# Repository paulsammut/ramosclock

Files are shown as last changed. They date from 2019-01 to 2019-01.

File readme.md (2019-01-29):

# Ramos Alarm Clock

The Ramos Alarm Clock was an alarm clock that forced people to get out of bed in
the morning by making it impossible to shut off the alarm from bed and simply
going back to sleep. It accomplished this by the use of a "defuse panel" which
was a wireless keypad that the user would place somewhere far away from their
bedroom. Most users put it in the bathroom; more extreme users put in their car.
When the alarm went off, the user had to get out of bed, and walk to the defuse
panel and punch in a defuse code to turn off the alarm. This gave well
intentioned users that really wanted to get up early but just had a hard time
escaping the cozy gravitational field of their bed the push they needed to start
their day fresh and early (kinda like how mom woke you up during high school).

This project started out as a [kickstarter
campaign](https://www.kickstarter.com/projects/2074185253/ramos-alarm-clock).

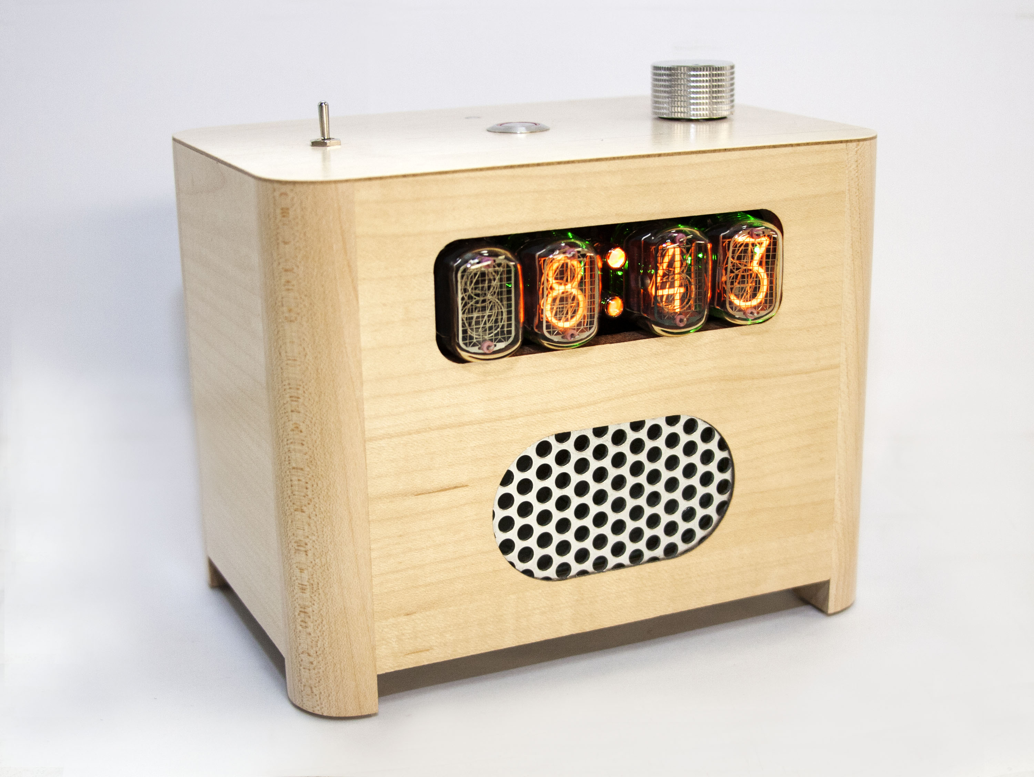
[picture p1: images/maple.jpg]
Maple Nixie Ramos Nixie_Ramos


## Source Code

This source was written by Nolan Sandberg, and Paul Sammut.

This is the source code for the Nixie Ramos, LED Ramos and the defuse panel.
These 3 devices shared similar code and all ran on the same PIC18F45K20
microcontroller. The code includes the MPLAB X project files and the compiler used
was the C18 compiler. All source is written in C and programmed using a PicKit3.
There are loads of features in the clock such as:

* Sound system for playing tones and a voice menu 
* Digit cycling on each minute for Nixie Tube health 
* The defuse code could be either the day's date or a random code 
* An external RTC with an built in TCXO with a clock accuracy of 3 ppm 
* Multiplex display driver that allowed for 32 levels of brightness for each tube 
* Auto-dim brightness with an light sensor, to dim the display to a settable
  level when there is no light in the room.

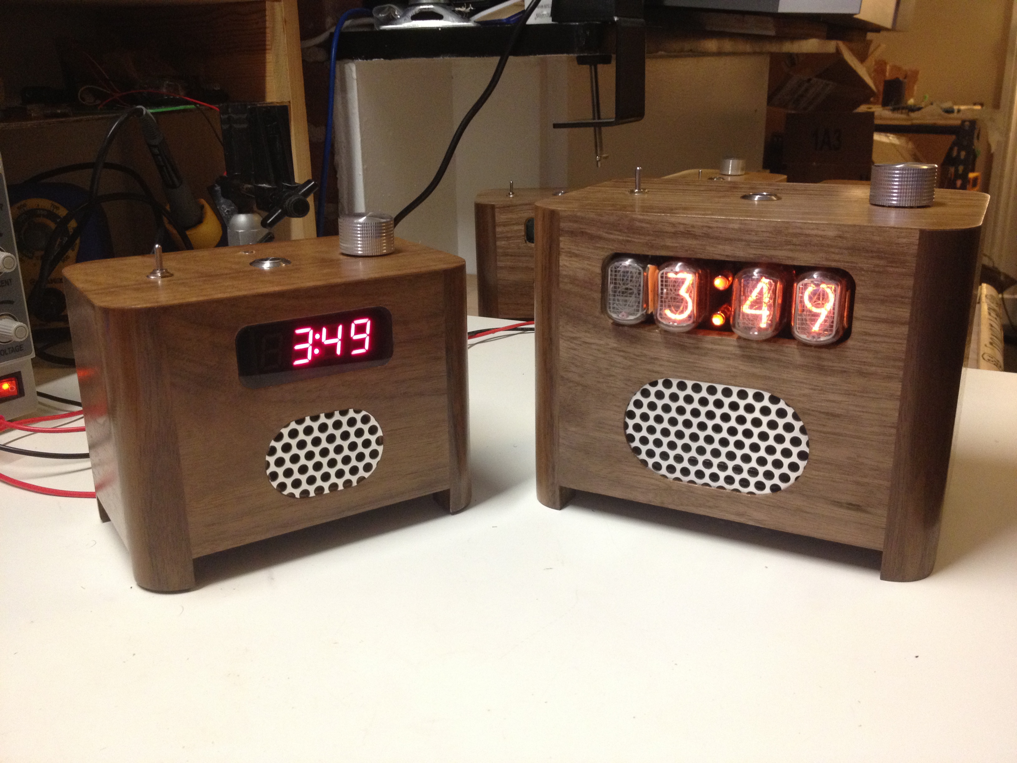
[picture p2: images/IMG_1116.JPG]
LED Ramos left and Nixie Ramos right LED_Nixie_Ramos


## Circuit Files

Included in this repo are also all the schematics, gerbers and Altium files. The
boards were panelized and mass produced. Great consideration was taken to
minimize the BOM count and facilitate assembly. These clocks all passed FCC
testing, even the Nixie! One of the very few Nixie Clocks that's FCC certified.
The EMC report is included in the schematics folder.

Circuit Board Nixie board

### Nixie Circuit

IN-12A Nixie tubes were used. I bought thousands in bulk from sellers in the
Ukraine and Russia. When I bought them in 2012-2014 the price was around $1.50 a
tube shipped. 

The nixie circuit used a Taylor Edge 1364 high voltage power supply that
supplied the 170 Volts. The display was controlled using ULN2003s in a neat way.
You can't find 8 channel transistor IC's that can handle 180V's anymore, and I
didn't want to use the original Russian nixie drivers IC's for reliability
issues, so I used the ULN2003's which had a max volt rating of 100V and clamped
the common voltage to 91V. This meant that in their off state, the tubes saw
91V, which wasn't enough to fire the tubes, and in their on state they saw the
full 170V. The ULN's only saw the delta of 170 and 91, which was below the max
rated voltage, so it was happy. Out of the thousand clocks we sold, we never had
an issue with the driver circuitry. 

### Wireless

The wireless data link between the defuse panel and the clock is handled by a
CC1101 chip on board an Anaren module. This module was the most expensive part
of the BOM ($11 at high volume) but it was pre-certified as an intentional
radiator. Interfacing to the CC1101 chip was a bit of a pain, the but the source
is all there as a reference. Great chip and we had very good range throughout a
house and sometimes outside the house.

### The Alarm Not Going Off Bug

We made a thousand of these clocks and only had one return. But, there was one
major bug that we caught early on and it had to do with the sound system
communication. A couple of people would email us, swearing that their alarm
didn't go off.

It was a really interesting problem because you could never replicated it on the
bench, and when the user would power cycle their clock it would magically work
again. This was because the problem was related to accumulated oscillator drift
which effected the PWM communication timing with the sound chip, meaning that
whenever you restarted the clock the problem would go away. The problem would
only manifest itself in a tiny percentage of our clocks, after the clock was
running for a long period of time. I was never ever able to reproduce the
problem, but I was able to pin point it to a less than robust communications PWM
protocol with the sound chip.

In the original firmware, the PIC18, who handled all the state flow stuff, would
send a signal to the sound chip using a PWM serial comms protocol to play a
sound. The PIC18 would assume that the sound was playing and happily move on.
This worked all the time during bench testing and our beta testing, and our
initial shipments. But it had no error checking and when you start playing
statistics, with a 1000 devices each with an alarm event every day, with
oscillator drift ranges, it meant that a tiny percentage of those sound commands
sent through PWM had their pulse widths exceeding the limits, meaning a poor
person's alarm wouldn't go off that morning. 

I fixed it by monitoring a DO line from the sound chip that would go high when
sound was playing. On every sound command sent by the PIC18, it made sure to
monitor the response from the sound chip. If it detected no sound was playing it
would do a live oscillator re-cal and resend the command. I was lucky to have
routed this line to a DI pin on the PIC18, so it was a simple firmware fix. 

### Altium Board Files

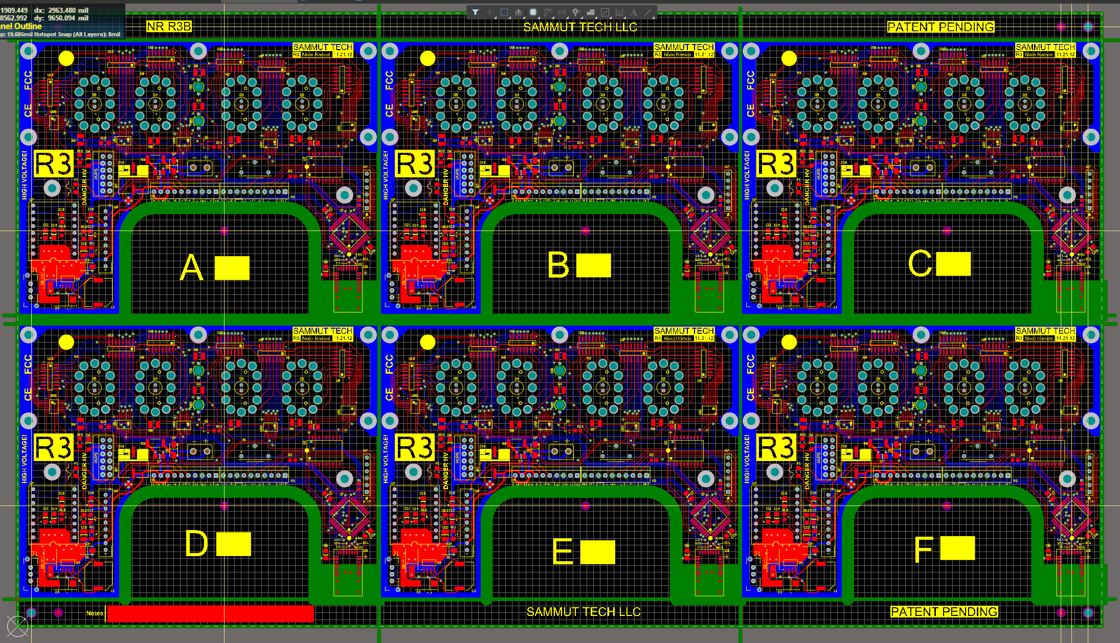
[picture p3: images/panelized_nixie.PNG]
Panelized boards Panelized Board


Included are packaged Altium files for all the boards. They were packed using
Altium 2019. Included are also all the panelized boards. The circuit boards were
4 layer: two signal, a ground and a power plane.

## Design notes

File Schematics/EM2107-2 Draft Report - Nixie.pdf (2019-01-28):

# Test Report

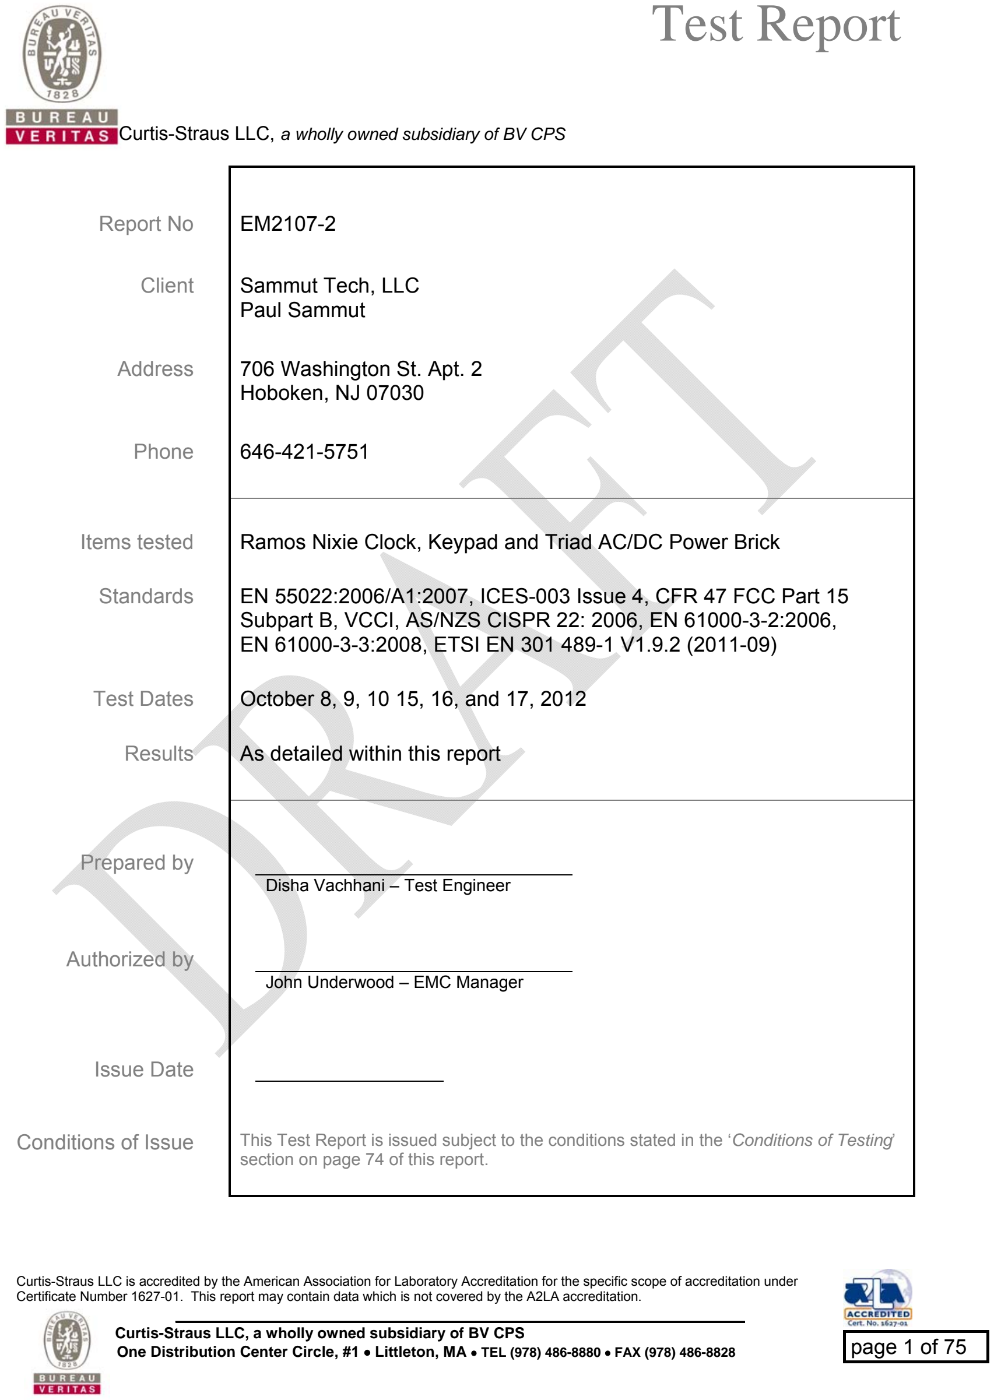
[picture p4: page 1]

Curtis-Straus LLC is accredited by the American Association for Laboratory Accreditation for the specific scope of accreditation under Certificate Number 1627-01. This report may contain data which is not covered by the A2LA accreditation.
____________________________________________________________
LLC • | Curtis-Straus LLC, a wholly owned subsidiary of BV CPS
One Distribution Center Circle, #1 • Littleton, MA • TEL (978) 486-8880 • FAX (978) 486-8828 | page 1 of 75

Curtis-Straus LLC, a wholly owned subsidiary of BV CPS

Report No | EM2107-2
Client | Sammut Tech, LLC Paul Sammut
Address | 706 Washington St. Apt. 2 Hoboken, NJ 07030
Phone | 646-421-5751
Items tested | Ramos Nixie Clock, Keypad and Triad AC/DC Power Brick
Standards | EN 55022:2006/A1:2007, ICES-003 Issue 4, CFR 47 FCC Part 15 Subpart B, VCCI, AS/NZS CISPR 22: 2006, EN 61000-3-2:2006, EN 61000-3-3:2008, ETSI EN 301 489-1 V1.9.2 (2011-09)
Test Dates | October 8, 9, 10 15, 16, and 17, 2012
Results | As detailed within this report

Prepared by
Disha Vachhani – Test Engineer

Authorized by
John Underwood – EMC Manager

Issue Date

Conditions of Issue This Test Report is issued subject to the conditions stated in the ‘Conditions of Testing’ section on page 74 of this report.

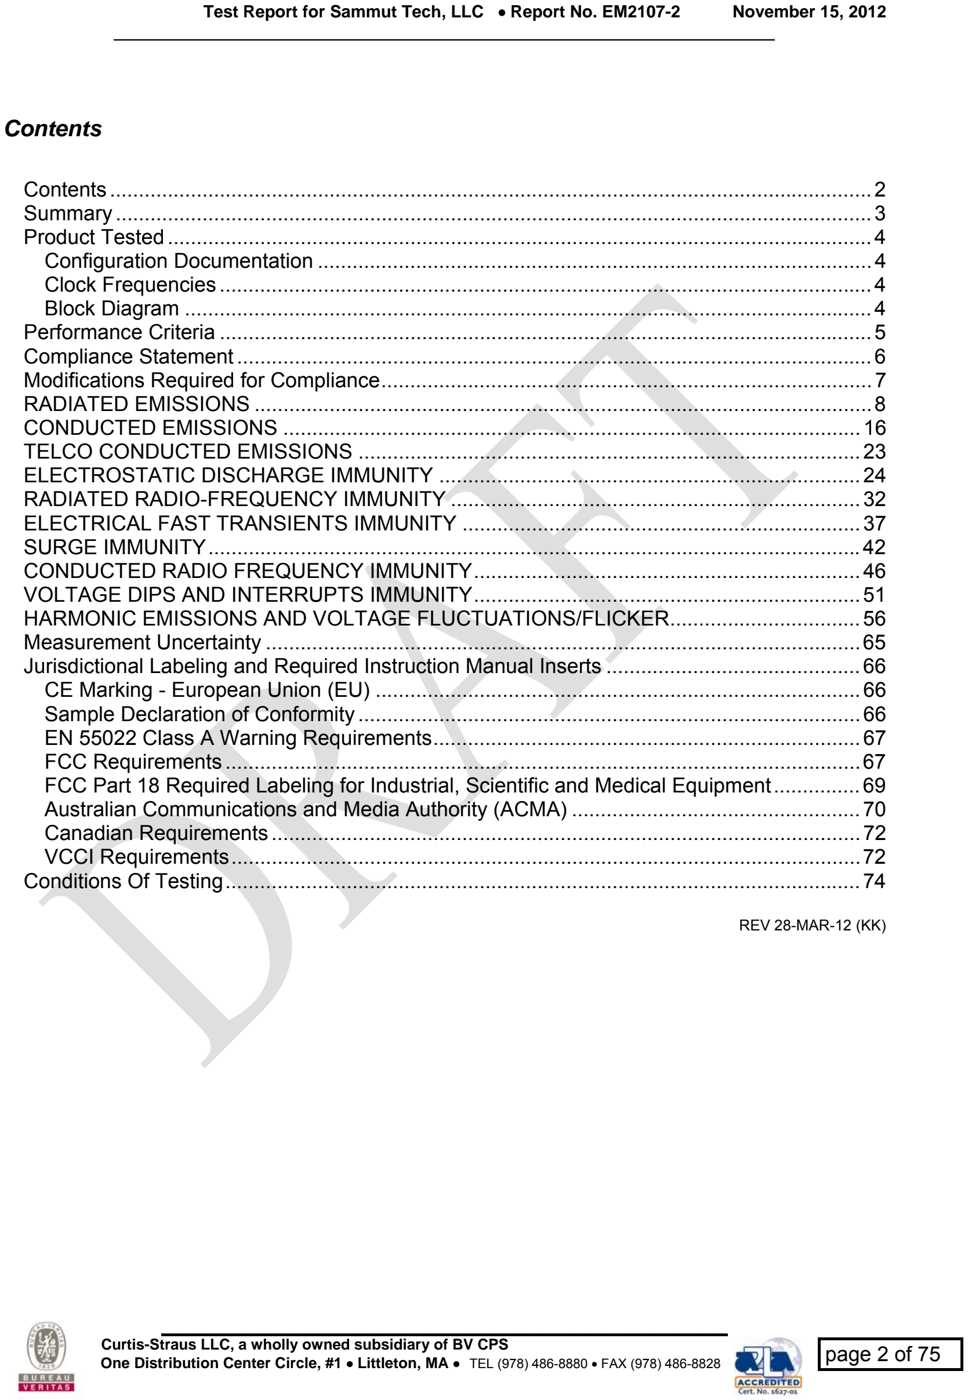
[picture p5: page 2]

Test Report for Sammut Tech, LLC • Report No. EM2107-2 November 15, 2012 ______________________________________________________________________

____________________________________________________________
Curtis-Straus LLC, a wholly owned subsidiary of BV CPS One Distribution Center Circle, #1 • Littleton, MA • TEL (978) 486-8880 • FAX (978) 486-8828 | page 2 of 75

Contents

REV 28-MAR-12 (KK)

Issue No. | Reason for change | Date Issued
1 | Original Release | November 15, 2012

_____________________________________________________________ Curtis-Straus LLC, a wholly owned subsidiary of BV CPS
One Distribution Center Circle, #1 • Littleton, MA • TEL (978) 486-8880 • FAX (978) 486-8828

page 3 of 75

Summary

On October 8, 9, 10 15, 16, 17, 2012 we tested the Ramos Nixie Clock, Keypad and Triad AC/DC Power Brick for compliance with the following requirements:

EMC Emissions:
- EN 55022:2006/A1:2007 Class B ITE emissions requirements (EU)
- ICES-003 Issue 4 Class B Digital Apparatus emissions requirements (Canada)
- CFR 47 FCC Part 15 Subpart B Class B emissions requirements (USA)
- VCCI Class B ITE emissions requirements (Japan)
- AS/NZS CISPR 22: 2006 Class B ITE emissions requirements (Australia)
- EN 61000-3-2:2006 Limits for harmonic current emissions (equipment input current up to and including 16A per phase)
- EN 61000-3-3:2008 Limitation of voltage fluctuations and flicker in low-voltage supply systems for equipment with rated current up to and including 16 A

EMC Emissions and Immunity:
- ETSI EN 301 489-1 V1.9.2 (2011-09) Electromagnetic compatibility and Radio spectrum Matters (ERM); ElectroMagnetic Compatibility (EMC) standard for radio equipment and services; Part 1: Common technical requirements – Fixed use

We found that the product met the above requirements with modification (see Modifications Required for Compliance section on page 6). The test sample was received in good condition. The sample was received on August 31, 2012.

Please note that the Ramos Nixie Clock was tested in alarm and standby modes.

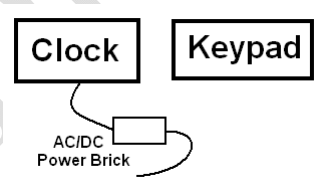
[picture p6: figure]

One Distribution Center Circle, #1 • Littleton, MA • TEL (978) 486-8880 • FAX (978) 486-8828 | page 4 of 75

Product Tested

Configuration Documentation

EUT Configuration

Work Order: M2107
Company: Sammut Tech, LLC
Company Address: 706 Washington St. Apt. 2 Hoboken, NJ 07030
Contact: Paul Sammut
| | MN | | | | | | SN
EUT:
Ramos Clock | | Nixie Ramos | | | | | | Sample 1
Ramos Keypad | | Not Listed | | | | | | Sample 1
Triad AC/DC Power Brick | | WSU135-1330 | | | | | | Sample 1
EUT Description: Ramos Clock and Ramos Clock Keypad
EUT Max Frequency: 32Mhz
EUT Min Frequency: 8MHz
EUT Ports:
Port Label | Port Type No. of ports
| | | No.
Populated Cable Type Shielded | Ferrites | Length
| | | | | | | | Max
| | | | | | | | Length | In/Out
| | | | | | | | | NEBS Type

Unpopulated
Reason
AC/DC Power Brick | AC Power | 1 | 1 | 2-wire | NA | no | NA | NA | Indoor
Software / Operating Mode Description:
EUT is a clock that has alarm settings. It can be operated with AC/DC power or battery. The keypad is used to set the alarm and to turn off the alarm.

Clock Frequencies

### EUT Frequencies (MHz)

8
32

Block Diagram

One Distribution Center Circle, #1 • Littleton, MA • TEL (978) 486-8880 • FAX (978) 486-8828 | page 5 of 75

Performance Criteria
Criterion A: The unit must operate as intended during the test. In particular, the clock shall update the time by 1 minute every 60 seconds; before the time is updated a random number will be displayed. In normal mode: the LED on the keypad shall continuously blink pink (indicating data is being sent) and then green (indicating data is being received). The LED shall not turn blue, which indicates standby mode. In standby mode: The clock shall not unintentionally transmit.

Criterion B: The unit must operate as intended at the conclusion of the test with no loss of state or data.

Criterion C: Temporary loss of function is allowed, provided the function is self-recoverable or can be restored by the operation of the controls by the user in accordance with the manufacturer's instructions.

One Distribution Center Circle, #1 • Littleton, MA • TEL (978) 486-8880 • FAX (978) 486-8828 | page 6 of 75

Compliance Statement

TEST | RESULT | STANDARD | TEST LEVEL | MARGIN | COMMENTS

Radiated
Emissions

PASS

EN55022:2006/A1:2007
ICES-003 Issue 4
CFR 47 FCC Part 15
Subpart B
VCCI
AS/NZS CISPR22:2006
Class B | -8.8dB @ 51.8MHz

AC Mains
Conducted
Emissions

PASS

EN55022:2006/A1:2007
ICES-003 Issue 4
CFR 47 FCC Part 15
Subpart B
VCCI
AS/NZS CISPR22:2006
Class B | -6.8dB @ 0.17MHz

Telco Line
Conducted
Emissions
N/A | EN55022:2006/A1:2007
VCCI | N/A | N/A | No telco cables
ESD | PASS | EN 61000-4-2

±4kV contact
±8kV air

N/A

Performance
Criteria B

RFI -
Amplitude
Modulated
| PASS | EN 61000-4-3

80-1000MHz and
1.4-2.7GHz at
3V/m
1KHZ 80% AM

N/A

Performance
Criteria A
EFT | PASS | EN 61000-4-4 | ±1kV AC | N/A
| | Performance Criteria B
±1kV Line-Line ±2kV Line-Earth | N/A | Performance Criteria B
| | EUT is AC powered
AC Surge | PASS | EN 61000-4-5
DC Surge | N/A | EN 61000-4-5 | N/A | N/A

Signal/Telco
Surge
N/A | EN 61000-4-5 | N/A | N/A | No signal/telco
cables

One Distribution Center Circle, #1 • Littleton, MA • TEL (978) 486-8880 • FAX (978) 486-8828 | page 7 of 75
TEST | RESULT | STANDARD | TEST LEVEL | MARGIN | COMMENTS
CRFI | PASS | EN 61000-4-6

0.15-80MHz at
3Vrms
1KHZ 80% AM

N/A

Performance
Criteria A

Voltage Dips
And Short
Interruptions
PASS | EN 61000-4-11

0%V for 0.5 and 1
cycle (B)
70%V for 25/30
cycles (C)
0%V 250/300
cycles (C)

N/A

Harmonics | PASS | EN 61000-3-2 | Class A | N/A
Flicker | PASS | EN 61000-3-3 | N/A | N/A

Modifications Required for Compliance

Modifications were required for the following tests:

- Conducted Emissions

In order to be compliant with AC Line conducted emissions, a 0.098µF capacitor was added to the Triad power supply. Prior to the modification, the EUT failed by 2.6dB at 0.21MHz.

One Distribution Center Circle, #1 • Littleton, MA • TEL (978) 486-8880 • FAX (978) 486-8828 | page 8 of 75

RADIATED EMISSIONS

Test Method:
In accordance with the following:
- EN55022:2006/A1:2007
- ICES-003 Issue 4
- CFR 47 FCC Part 15 Subpart B
- VCCI
- AS/NZS CISPR22:2006

Results:

TEST | RESULT | TEST LEVEL | MARGIN | COMMENTS

Radiated
Emissions
| PASS | Class B | -8.8dB @
51.8MHz

One Distribution Center Circle, #1 • Littleton, MA • TEL (978) 486-8880 • FAX (978) 486-8828 | page 9 of 75

Radiated Emissions Data Table(s):

Radiated Emissions Table | Version 1.017.066
Date: 09-Oct-12 | Company: Sammut Tech, LLC | Work Order: M2107
Engineer: Nirak So | EUT Desc: Nixie Ramos Clock | EUT Operating Voltage/Frequency: 230Vac, 50Hz
Temp: 24.7°C | Humidity: 24% | Pressure: 1016mBar
Frequency Range: 30 MHz to 1000MHz | Measurement Distance: 3 m
Notes: Alarm On mode with Triad PS and 0.098 microfarad capacitor | EUT Max Freq: 8MHz
Also checked Alarm on in Battery Mode. The emissions were not significantly different.
Antenna Polarization (H / V) | Frequency (MHz) | Reading (dBµV) | Preamp Factor (dB) | Antenna Factor (dB/m) | Cable Factor (dB) | Adjusted Reading (dBµV/m) | CISPR Class B | FCC Class B
Limit (dBµV/m) | Margin (dB) | Result (Pass/Fail) | Limit (dBµV/m) | Margin (dB) | Result (Pass/Fail)
v v v v v v | 51.8 84.5 102.8 144.0 154.0 206.0 | 49.0 27.6 30.5 26.0 38.0 29.0 | 25.7 25.7 25.7 25.8 25.7 25.9 | 7.5 7.4 11.6 12.8 12.4 10.6 | 0.4 0.6 0.5 0.6 0.7 0.8 | 31.2 9.9 16.9 13.6 25.4 14.5 | 40.5 40.5 40.5 40.5 40.5 40.5 | -9.3 -30.6 -23.6 -26.9 -15.1 -26.0 | Pass Pass Pass Pass Pass Pass | 40.0 40.0 43.5 43.5 43.5 43.5 | -8.8 -30.1 -26.6 -29.9 -18.1 -29.0 | Pass Pass Pass Pass Pass Pass
Table Result: | Pass | by | -8.8 dB | Worst Freq: | 51.8 MHz
Test Site: EMI Chamber 2 | Cable 1: Asset #1522 | Cable 2: Asset #1506 | Cable 3: ---
Analyzer: Gold | Preamp: Green | Antenna: Red-Brown | Preselector: ---
Radiated Emissions Table | Version 1.017.066
Date: 09-Oct-12 | Company: Sammut Tech, LLC | Work Order: M2017
Engineer: Nirak So | EUT Desc: Nixie Ramos Clock | EUT Operating Voltage/Frequency: 230Vac, 50Hz
Temp: 24.7°C | Humidity: 24% | Pressure: 1016mBar
Frequency Range: 30MHz to 1000MHz | Measurement Distance: 3 m
Notes: Alarm Off mode with Triad PS and 0.098 microfarad capacitor | EUT Max Freq: 8MHz
Also checked Alarm off in Battery mode. The emissions were not significantly different.
Antenna Polarization (H / V) | Frequency (MHz) | Reading (dBµV) | Preamp Factor (dB) | Antenna Factor (dB/m) | Cable Factor (dB) | Adjusted Reading (dBµV/m) | CISPR Class B | FCC Class B
Limit (dBµV/m) | Margin (dB) | Result (Pass/Fail) | Limit (dBµV/m) | Margin (dB) | Result (Pass/Fail)
v v v v v v | 51.8 85.3 103.3 156.0 185.2 207.0 | 47.7 32.0 30.5 40.0 28.5 28.2 | 25.7 25.7 25.7 25.7 25.8 25.9 | 7.5 7.4 11.8 12.4 11.1 10.6 | 0.4 0.6 0.5 0.7 0.7 0.8 | 29.9 14.3 17.1 27.4 14.5 13.7 | 40.5 40.5 40.5 40.5 40.5 40.5 | -10.6 -26.2 -23.4 -13.1 -26.0 -26.8 | Pass Pass Pass Pass Pass Pass | 40.0 40.0 43.5 43.5 43.5 43.5 | -10.1 -25.7 -26.4 -16.1 -29.0 -29.8 | Pass Pass Pass Pass Pass Pass
Table Result: | Pass | by | -10.1 dB | Worst Freq: | 51.8 MHz
Test Site: EMI Chamber 2 | Cable 1: Asset #1522 | Cable 2: Asset #1506 | Cable 3: ---
Analyzer: Gold | Preamp: Green | Antenna: Red-Brown | Preselector: ---
Rev.10/5/2012 | _
Spectrum Analyzers / Receivers /Preselectors | Range | MN | Mfr | SN | Asset | Cat | Calibration Due
Gold | 100Hz-26.5 GHz | E4407B | Agilent | MY45113816 | 1284 | I | 2/3/2013
_
Radiated Emissions Sites | FCC Code | IC Code | VCCI Code | | | Cat | Calibration Due
EMI Chamber 2 | 719150 | 2762A-7 | A-0015 | | | II | 2/15/2014
_
Preamps /Couplers Attenuators / Filters | Range | MN | Mfr | SN | Asset | Cat | Calibration Due
Green | 0.009-2000MHz ZFL-1000-LN | CS | N/A | 802 | II | 9/19/2013
_
Antennas | Range | MN | Mfr | SN | Asset | Cat | Calibration Due
Red-Brown Bilog | 30-2000MHz | JB1 | Sunol | A0032406 | 1218 | I | 10/25/2012
_
Cables | Range | | Mfr | | | Cat | Calibration Due
Asset #1522 | 9kHz - 26.5GHz | | Florida RF | | | II | 2/8/2013
Asset #1506 | 9kHz - 18GHz | | Florida RF | | | II | 2/2/2013
_
Meteorological Meters | | MN | Mfr | SN | Asset | Cat | Calibration Due
Weather Clock (Pressure Only) | | BA928 | Oregon Scientific | C3166-1 | 831 | I | 3/28/2013
CHAMBER2 Thermohygrometer | | 35519-044 | Control Company | 72457639 | 1347 | II | 8/19/2013
_
All equipment is calibrated using standards traceable to NIST or other nationally recognized calibration standard.

One Distribution Center Circle, #1 • Littleton, MA • TEL (978) 486-8880 • FAX (978) 486-8828 | page 10 of 75

Radiated Emissions Modifications:
None

Additional Modifications in place during testing: See modification required for AC Conducted Emissions.

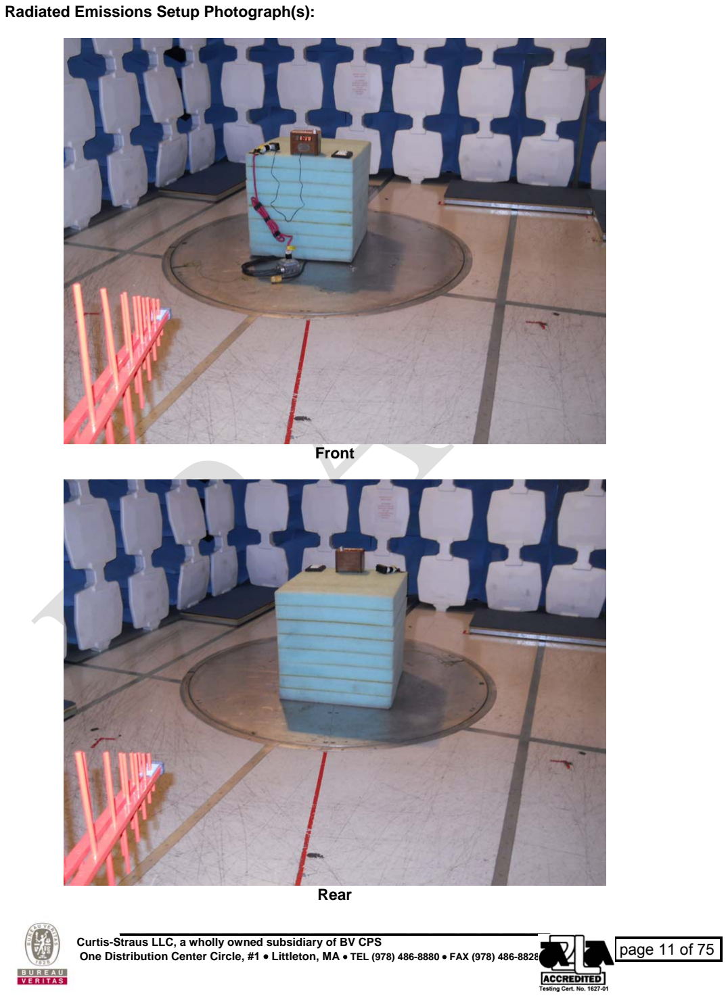
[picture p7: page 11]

One Distribution Center Circle, #1 • Littleton, MA • TEL (978) 486-8880 • FAX (978) 486-8828 | page 11 of 75

Radiated Emissions Setup Photograph(s):

Front

Rear

One Distribution Center Circle, #1 • Littleton, MA • TEL (978) 486-8880 • FAX (978) 486-8828 | page 12 of 75

Radiated Emissions Testing Overview

REV 10-APR-09
Digital and microprocessor based devices use radio frequency (RF) digital signals for timing purposes. An unintentional consequence of this signal usage is that a certain amount of RF energy is radiated from the device into the local environment. This radiated RF energy has the potential to interfere with constructive uses of the RF spectrum such as television broadcasting, police and fire radio, and the like. In order to reduce the likelihood that a device will interfere with these services, it is required that the amplitudes of radiated RF signals from the device are kept below an allowable level.
These RF signals decrease in strength as the distance from the source increases. Thus if the potential victim of interference, e.g. a TV receiver, is far enough from the radiator, e.g. a computer, then no interference will occur. For certain environments it is appropriate to expect that potential interference victims will be located at least a minimum distance from the radiator. For the residential environment this distance is generally accepted to be 10 meters while in the commercial environment the accepted distance is 30 meters. The allowable emissions levels are therefore specified to protect equipment which is located further than that distance from the radiator. In general, radiation from the Equipment Under Test (EUT) is measured at 3 or 10 meters to insure that it is at or below allowable levels.
Measurements of the radiated energy are made by recording the field strength indicated by an antenna placed at a specific distance from the device. Most devices do not radiate the RF energy in a predictable manner. The emitted energy may vary with changes in operating mode, physical configuration, or orientation. During the measurement process these parameters are varied to confirm that the emissions will remain below the allowable levels in the range of typical installations.
The extent of annoyance experienced by a person who is being affected by interference is related to the persistence of the interfering signal. For example, a low level steady whine from a receiver is considered to be more annoying than brief, loud, intermittent pops or clicks. This “human factor” is accounted for by the use of a “quasi-peak” detector in the receiver or spectrum analyzer which measures the signal from the measurement antenna. The detector is a weighted averaging filter with a fast charge time and a slow discharge time. Thus steady continuous signals will charge the quasi-peak detector fully while intermittent signals (those with pulse repetition rates less than 1kHz) are reported at a level which can be significantly below their peak level. It should be noted that most RF signals produced by digital devices are continuous in nature and thus the quasi-peak reading will be identical to the peak signal reading. To reduce the test time, the peak emission level is recorded for continuous wave signals as it is the same as the quasi-peak signal level.
Testing is performed according to test methods from ANSI C63.4 and CISPR 22.
The test site used for measuring radiated emissions follows the format developed internationally for a weather protected Open Area Test Site (OATS). The test site used for measuring radiated emissions above 1GHz for CISPR limits is a Free Space Open Area Test Site (FSOATS). An antenna mast is installed at the specified distance from a rotating table and is used to raise and lower the measuring antenna. The reference site is clear of reflecting objects, such as metal fences and buildings for an ellipse of twice the measurement test

One Distribution Center Circle, #1 • Littleton, MA • TEL (978) 486-8880 • FAX (978) 486-8828 | page 13 of 75

distance. Measuring equipment and personnel are present within the ellipse to facilitate cable manipulation, but measures are taken to minimize the effects. Often preliminary radiated emissions measurements are made at alternate test sites which do not meet the clear space reference criteria. The data collected at alternate test sites is not considered conclusive unless the alternate site also complies with a volumetric site attenuation survey performed over the area that the EUT occupies. The EUT and measuring antenna mark the two foci of the ellipse. The ground plane is made of a combination of galvanized steel sheets and tight wire mesh electrically connected along the seams. This metal ground plane extends 1 meter beyond the furthest extent of the EUT and the measuring antenna. It also covers the area between the EUT and the measuring antenna. The hardware cloth is connected to the utility ground or to stakes driven into the earth for safety. The site configuration for CISPR testing above 1GHz is a semi-anechoic chamber. The ground plane in the test volume is covered by an absorbing material between the antenna and the EUT. In the case of table top equipment, the absorbing material is also placed under the table. In the case of floor-standing equipment the absorbing material extends up from the ground plane 30cm into the test volume, and surrounds the EUT by at most 10cm from the footprint of the equipment.
In order for accurate emissions measurements to be made the test site must possess propagation characteristics which fall within accepted norms. The site has been checked for suitability using techniques specified in American National Standards Institute (ANSI) document C63.4. This document details a procedure which measures the attenuation of the site which is the chief indicator of site acceptability. The theory behind site attenuation is quite simple. A transmitting antenna is set up at a fixed location at one end of the site with a receiving antenna at the other end. If a signal of some arbitrary amplitude is fed into the transmitting antenna, a lesser amount of signal ought to be measured at the receiving antenna. This difference in signal amplitude is known as the site attenuation, which should follow a predicted curve. Data that does not correspond to the predicted site attenuation curve points to a problem with either the equipment being used or the physical characteristics of the site.
Actual emissions measurements are taken with broadband biconical-log-periodic hybrid antennas calibrated in accordance with the standard site method detailed in ANSI C63.5. Emissions are measured with the receiving antenna oriented in horizontal and vertical polarization with respect to the ground plane. If measurements are made at other than the limit distance, then the readings obtained are scaled to the limit distance using an inverse relationship. The actual test distance used is noted in the report.
The antenna mast is capable of a varying the antenna height between 1 and 4 meters above the ground plane. The receiving antenna is moved over this range at each emission frequency in order to record the maximum observed signal. The mast is non-conductive and remotely controllable. The test distance is measured from the antenna center (marked during calibration) and the periphery of the EUT.
The Equipment Under Test (EUT) is rotated in order to maximize emissions during the test. For equipment intended to operate on a tabletop or desk radiated tests are conducted on a 0.8 meter high, non-conductive platform. Larger floor standing equipment is tested on a floor mounted rotatable platform. In some cases, large equipment on its own casters may be tested without a platform.

One Distribution Center Circle, #1 • Littleton, MA • TEL (978) 486-8880 • FAX (978) 486-8828 | page 14 of 75

Since radiated emissions are a function of cable placement, the cable placement is varied to encompass typical configurations that an end user might encounter to determine the configuration resulting in maximum emissions. At least one cable for each I/O port type is attached to the EUT. If peripherals or modules are available, at least one of each available type is installed and noted in the report. Excess cable length beyond one meter is bundled in the center into a 30 to 40 cm bundle. Cables requiring non-standard lead dress are recorded in the report.
Network connections are simulated if necessary. Any simulator used matches the expected real network connection in terms of both functionality and impedance. For distributed systems, the support equipment may be placed at such a distance that it does not influence the measured emissions. If this option is used, such placement is noted in the test report.
The possible operating modes of the EUT are explored to determine the configuration which maximizes emissions. Software is investigated as well as different methods of displaying data if available. Data is recorded in the worst case operating mode.
At least the six highest emissions with respect to the limit are recorded. If less than six emissions are visible above the noise floor of the instrumentation, then noise floor
measurements at six representative frequencies are recorded. The test report will document if noise floor readings are reported.

FCC and European Norms Radiated Emissions Limits at 10 meters

Frequency (MHz) | FCC Class A | FCC Class B | CISPR Class A | CISPR Class B | Frequency (MHz)
30-88 | 39.1 | 29.5 | 40 | 30 | 30-88
88-216 | 43.5 | 33.1 | 40 | 30 | 88-216
216-230 | 46.4 | 35.6 | 40 | 30 | 216-230
230-960 | 46.4 | 35.6 | 47 | 37 | 230-960
960-1000 | 49.5 | 43.5 | 47 | 37 | 960-1000
1000-3000 | Avg: 49.5 Peak: 69.5 | Avg: 43.5 Peak: 63.5 | Not defined | Not defined | 1000-3000
3000+ | Avg: 49.5 Peak: 69.5 | Avg: 43.5 Peak: 63.5 | Not defined | Not defined | 3000+

At the transitions, the lower limit applies. Simple inverse scaling utilized to convert limits where appropriate.

FCC and European Norms Radiated Emissions Limits at 3 meters

Frequency (MHz) | FCC Class A | FCC Class B | CISPR Class A | CISPR Class B | Frequency (MHz)
30-88 | 49.5 | 40 | 50.5 | 40.5 | 30-88
88-216 | 54 | 43.5 | 50.5 | 40.5 | 88-216
216-230 | 56.9 | 46 | 50.5 | 40.5 | 216-230
230-960 | 56.9 | 46 | 57.5 | 47.5 | 230-960
960-1000 | 60 | 54 | 57.5 | 47.5 | 960-1000

One Distribution Center Circle, #1 • Littleton, MA • TEL (978) 486-8880 • FAX (978) 486-8828 | page 15 of 75
1000-3000 | Avg: 60 Peak: 80 | Avg: 54 Peak: 74 | Avg: 56 Peak: 76 | Avg: 50 Peak: 70 | 1000-3000
3000+ | Avg: 60 Peak: 80 | Avg: 54 Peak: 74 | Avg: 60 Peak: 80 | Avg: 54 Peak: 74 | 3000+

At the transitions, the lower limit applies. Simple inverse scaling utilized to convert limits where appropriate.

The measurement range is based on the highest frequency signal present or used in the device. The following table details the frequency range of measurements performed.

Frequency range of radiated emissions measurements
Highest frequency generated or used in the device or on which the device operates or tunes (MHz) | Upper frequency of measurement range (MHz)
FCC | EU/CISPR
Below 1.705 | 30 (No radiated measurements) | 1000
1.705-108 | 1000 | 1000
108-500 | 2000 | 2000
500-1000 | 5000 | 5000
Above 1000 | 5th harmonic of the highest frequency 40 GHz whichever is lower. | 5th harmonic of the highest frequency 6 GHz whichever is lower.

The test data is derived from the voltage on the spectrum analyzer. First the reading is corrected for gain factors associated with the use of preamps and loss in the cable. A factor in dB is subtracted from the reading to account for preamp gain, while a factor in dB is added to the signal to account for cable loss. A conversion is performed from the resulting voltage to field strength by multiplying the voltage by the antenna factor. Since antenna factor is expressed as a logarithm (dB/m), this operation takes the form of an addition (to multiply logarithmic numbers, you add them together). Thus:

Field Strength (dBuV/m) = Voltage Reading (dBuV) - Preamp Gain (dB) + Cable Loss (dB) + Antenna Factor (dB/m)
When the levels of ambient radio signals such as local television stations are within 6 dB of the appropriate limit, the following steps may be taken to assure compliance:
1. The measurement bandwidth may be reduced. A check is made to see that peak readings are not affected. The use of a narrower bandwidth allows examination of emissions close to local ambient signals.
2. The antenna may be brought closer to the EUT to increase signal-to-ambient signal strength.
3. For horizontally polarized signals the axis of the test site may be rotated to discriminate against local ambients.

One Distribution Center Circle, #1 • Littleton, MA • TEL (978) 486-8880 • FAX (978) 486-8828 | page 16 of 75

CONDUCTED EMISSIONS

Test Method:
In accordance with the following:
- EN55022:2006/A1:2007
- ICES-003 Issue 4
- CFR 47 FCC Part 15 Subpart B
- VCCI
- AS/NZS CISPR22:2006

Results:

TEST | RESULT | TEST LEVEL | MARGIN | COMMENTS

AC Mains
Conducted
Emissions
| PASS | Class B | -6.8dB @
0.17MHz

DC Mains
Conducted
Emissions
| N/A | N/A | N/A

EUT is AC
powered

One Distribution Center Circle, #1 • Littleton, MA • TEL (978) 486-8880 • FAX (978) 486-8828 | page 17 of 75

Conducted Emissions Data Table(s):

AC Conducted Emissions Data Table Date: 08-Oct-12 | Company: Sammut Tech | Work Order: M2107
Engineer: Ami Soni | EUT Desc: Nixie Ramos Clock
Temp: 22.5 ºC | Humidity: 30% | Pressure: 1014 mBar
Notes: Alarm mode with Triad PS and 0.098 microfarad capacitor
| Frequency Range: 0.15-30MHz | EUT Input Voltage/Frequency: 230V, 50Hz
Frequency (MHz) | Quasi-Peak Readings | Average Readings | LISN Factors | Cable Factor | ATTN Factor | FCC/CISPR Class B | FCC/CISPR Class B
| QP1 QP2 (dBuV) (dBuV) | AVG1 AVG2 (dBuV) (dBuV) | L1 L2 (dB) (dB) | | | QP Limit Margin Result (dB) (dB) (Pass/Fail) | AVG Limit Margin Result (dB) (dB) (Pass/Fail)
(dB) | (dB)
0.17 0.40 0.61 1.76 8.73 10.22 19.95 29.83 | 36.7 37.6 28.6 28.5 22.5 22.9 16.7 12.5 13.1 8.7 9.5 6.9 14.9 17.8 3.2 3.0 | 15.5 15.4 9.9 8.1 7.5 4.9 6.3 3.4 2.7 0.2 2.6 -0.2 1.2 7.6 -2.5 -2.8 | -0.9 -0.3 -0.6 -0.2 -0.5 -0.2 -0.2 -0.1 -0.1 -0.1 -0.1 -0.1 -0.4 -0.4 -0.7 -0.7 | -0.1 -0.1 -0.1 -0.1 -0.2 -0.2 -0.3 -0.4 | -20.0 -20.0 -20.0 -20.0 -20.0 -20.0 -20.0 -20.0 | 64.7 -6.8 Pass 57.9 -8.6 Pass 56.0 -12.9 Pass 56.0 -19.0 Pass 60.0 -26.6 Pass 60.0 -30.2 Pass 60.0 -21.5 Pass 60.0 -35.7 Pass | 54.7 -18.2 Pass 47.9 -17.3 Pass 46.0 -17.9 Pass 46.0 -19.3 Pass 50.0 -27.0 Pass 50.0 -27.1 Pass 50.0 -21.7 Pass 50.0 -31.4 Pass
Result: Pass | Worst Margin: | -6.8 dB | Frequency: | 0.17 MHz
Measurement Device: 230VAC LISN Asset 1492 | Cable: CEMI-05 | Spectrum Analyzer: Red
Attenuator: 20dB Attenuator-64 | Site: CEMI 1
Rev.10/5/2012 | _
Spectrum Analyzers / Receivers /Preselectors | Range | MN | Mfr | SN | Asset | Cat | Calibration Due
Red | 9kHz-1.8GHz | 8591E | Agilent | 3441A03559 | 24 | I | 5/23/2013
_
LISNs/Measurement Probes | Range | MN | Mfr | SN | Asset | Cat | Calibration Due
230VAC LISN Asset 1492 | 10kHz-50MHz 9252-50-R-24-BNC | Solar | 84713 | 1492 | I | 5/10/2013
_
Conducted Test Sites (Mains / Telco) | FCC Code | | VCCI Code | | | Cat | Calibration Due
CEMI 1 | 719150 | | A-0015 | | | III | NA
_
Cables | Range | | Mfr | | | Cat | Calibration Due
CEMI-05 | 9kHz - 2GHz | | C-S | | | II | 5/1/2013
_
Attenuators | Range | MN | Mfr | SN | Asset | Cat | Calibration Due
20dB Attenuator-64 | 9kHz-2GHz | | | N/A | | II | 6/28/2013
_
Meteorological Meters | | MN | Mfr | SN | Asset | Cat | Calibration Due
Weather Clock (Pressure Only) | | BA928 | Oregon Scientific | C3166-1 | 831 | I | 3/28/2013
CEMI1 Thermohygrometer | | 35519-044 | Control Company | 72457738 | 1335 | II | 8/19/2013
_
All equipment is calibrated using standards traceable to NIST or other nationally recognized calibration standard.
AC Conducted Emissions Data Table Date: 10-Oct-12 | Company: Sammut Tech, LLC | Work Order: M2107
Engineer: Tuyen Truong | EUT Desc: Ramos Clock and Ramos Clock Keypad
Temp: 22.0 ºC | Humidity: 31% | Pressure: 1015 mBar
Notes: Nixie config - Alarm mode
| Frequency Range: 0.15-30 MHz | EUT Input Voltage/Frequency: 120Vac/60Hz
Frequency (MHz) | Quasi-Peak Readings | Average Readings | LISN Factors | Cable Factor | ATTN Factor | FCC/CISPR Class B | FCC/CISPR Class B
| QP1 QP2 (dBuV) (dBuV) | AVG1 AVG2 (dBuV) (dBuV) | L1 L2 (dB) (dB) | | | QP Limit Margin Result (dB) (dB) (Pass/Fail) | AVG Limit Margin Result (dB) (dB) (Pass/Fail)
(dB) | (dB)
0.18 0.24 1.97 3.68 9.70 21.69 | 33.1 25.9 24.3 18.7 18.2 22.5 12.5 13.1 10.0 13.2 15.0 17.9 | 10.1 8.7 8.8 7.3 13.0 15.6 0.5 3.5 8.6 12.4 4.9 6.7 | -0.8 -0.3 -0.7 -0.2 -0.2 -0.1 -0.1 -0.1 -0.1 -0.1 -0.5 -0.4 | -0.1 -0.1 -0.1 -0.1 -0.2 -0.3 | -20.7 -20.7 -20.6 -20.6 -20.6 -20.6 | 64.4 -9.8 Pass 62.0 -16.3 Pass 56.0 -12.7 Pass 56.0 -22.1 Pass 60.0 -25.9 Pass 60.0 -20.8 Pass | 54.4 -22.8 Pass 52.0 -21.8 Pass 46.0 -9.7 Pass 46.0 -21.7 Pass 50.0 -16.7 Pass 50.0 -21.9 Pass
Result: Pass | Worst Margin: | -9.7 dB | Frequency: | 1.97 MHz
Measurement Device: 230VAC LISN Asset 1492 | Cable: CEMI-05 | Spectrum Analyzer: Red
Attenuator: 20dB Attenuator-74 | Site: CEMI 1
Rev.10/10/2012 | _
Spectrum Analyzers / Receivers /Preselectors | Range | MN | Mfr | SN | Asset | Cat | Calibration Due
Red | 9kHz-1.8GHz | 8591E | Agilent | 3441A03559 | 24 | I | 5/23/2013
_
LISNs/Measurement Probes | Range | MN | Mfr | SN | Asset | Cat | Calibration Due
230VAC LISN Asset 1492 | 10kHz-50MHz 9252-50-R-24-BNC | Solar | 84713 | 1492 | I | 5/10/2013
_
Conducted Test Sites (Mains / Telco) | FCC Code | | VCCI Code | | | Cat | Calibration Due
CEMI 1 | 719150 | | A-0015 | | | III | NA
_
Cables | Range | | Mfr | | | Cat | Calibration Due
CEMI-05 | 9kHz - 2GHz | | C-S | | | II | 5/1/2013
_
Attenuators | Range | MN | Mfr | SN | Asset | Cat | Calibration Due
20dB Attenuator-74 | 9kHz-2GHz | | | N/A | | II | 10/4/2013
_
Meteorological Meters | | MN | Mfr | SN | Asset | Cat | Calibration Due
Weather Clock (Pressure Only) | | BA928 | Oregon Scientific | C3166-1 | 831 | I | 3/28/2013
CEMI1 Thermohygrometer | | 35519-044 | Control Company | 72457738 | 1335 | II | 8/19/2013
_
All equipment is calibrated using standards traceable to NIST or other nationally recognized calibration standard.

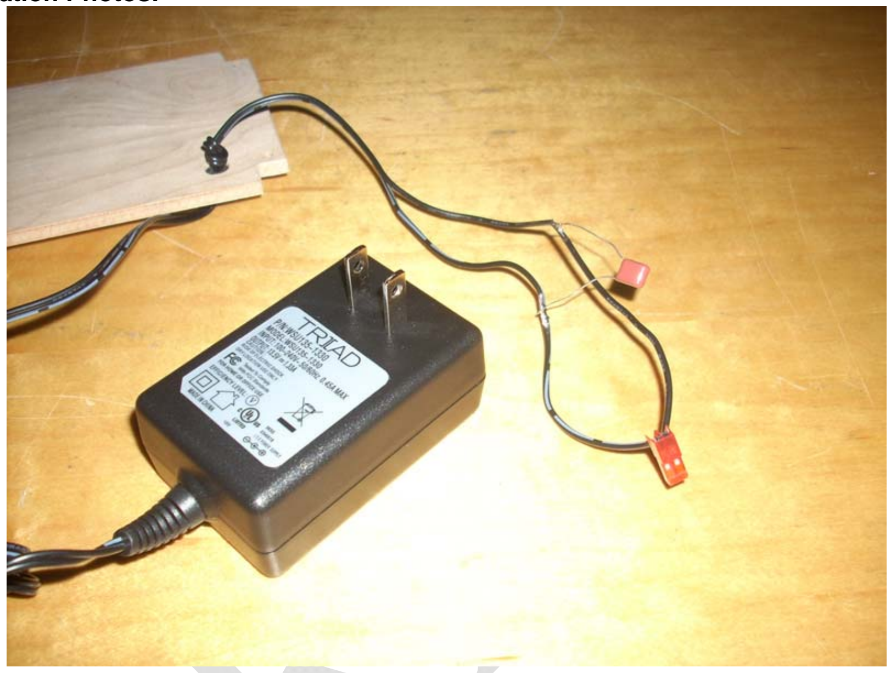
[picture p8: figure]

One Distribution Center Circle, #1 • Littleton, MA • TEL (978) 486-8880 • FAX (978) 486-8828 | page 18 of 75

Conducted Emissions Modifications:
In order to be compliant with AC Line conducted emissions, a 0.098µF capacitor was added to the Triad power supply. Prior to the modification, the EUT failed by 2.6dB at 0.21MHz.

Modification Photos:

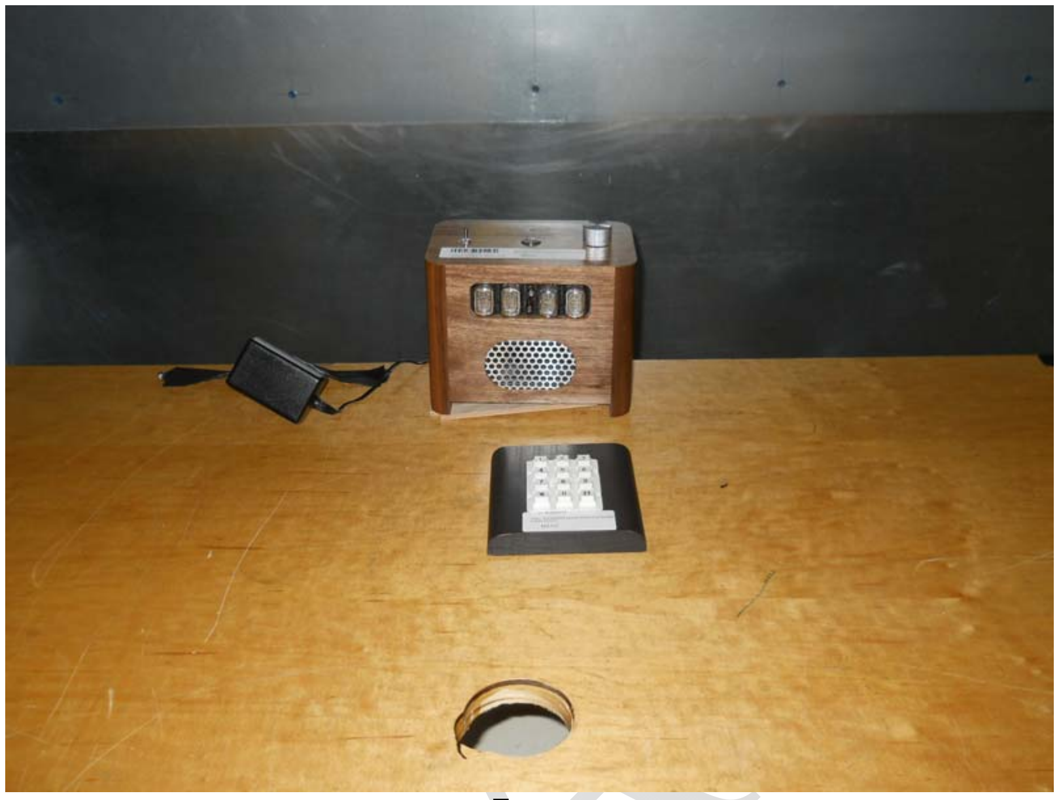
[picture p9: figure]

One Distribution Center Circle, #1 • Littleton, MA • TEL (978) 486-8880 • FAX (978) 486-8828 | page 19 of 75

Conducted Emissions Setup Photograph(s):

Front

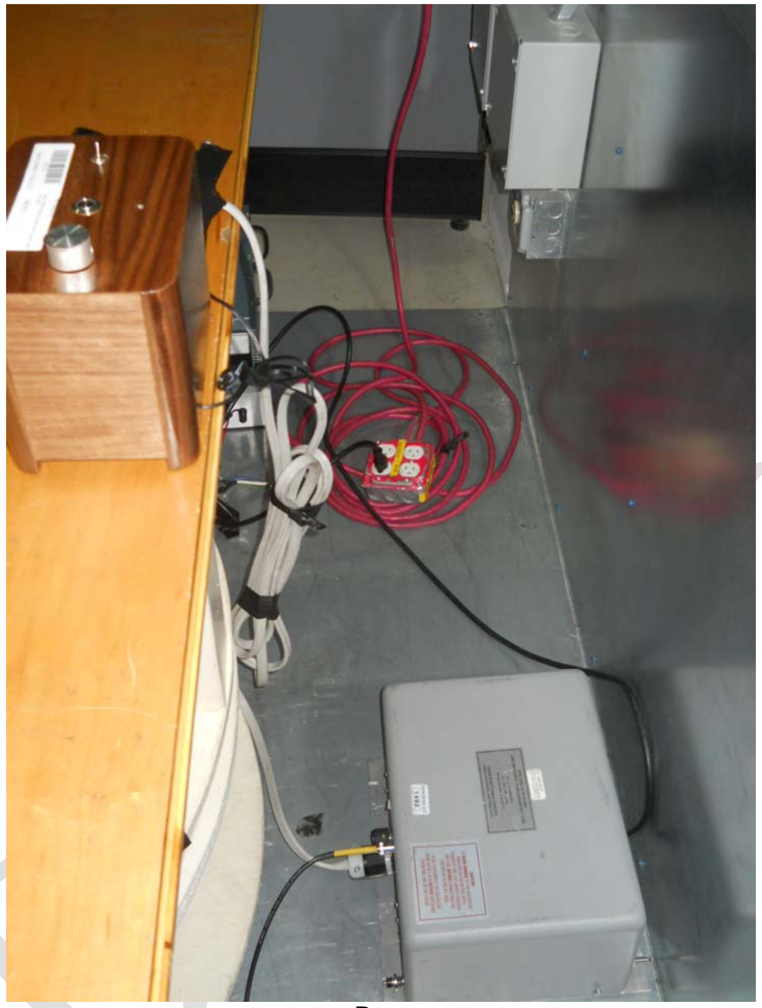
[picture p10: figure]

One Distribution Center Circle, #1 • Littleton, MA • TEL (978) 486-8880 • FAX (978) 486-8828 | page 20 of 75

Rear

One Distribution Center Circle, #1 • Littleton, MA • TEL (978) 486-8880 • FAX (978) 486-8828 | page 21 of 75

Line Conducted Emissions Overview:

REV 9-MAY-06
Digital and microprocessor based devices use radio frequency (RF) digital techniques for timing purposes and in applications such as switching power supplies. An unintentional consequence of this for AC powered devices is that a certain amount of the RF energy is impressed upon the AC power mains in the form of a conducted noise voltage. These conducted emissions have the potential to interfere with constructive uses of the RF spectrum such as AM radio and may also interfere with other devices attached to the same AC mains circuit. In order to reduce the likelihood that a device will interfere it is required that the conducted RF signals from the device are below an allowable level.
Testing is performed according to test methods from ANSI C63.4 and CISPR 22.
Line conducted emissions are measured from the device over the frequency range of 0.15 to 30 MHz. The EUT is powered from a Line Impedance Stabilization Network (LISN). The purpose of the LISN is to provide a calibrated impedance across which to measure the conducted emissions. The RF noise voltage produced by the EUT across the LISN is measured and compared to the limit. In order for the LISN to perform properly it is attached to a ground plane at least 2 meters by 2 meters in size. For tabletop equipment the measurement is performed with the equipment 40 cm from a vertical conducting surface bonded to a ground plane under the product. The ground plane extends 0.5 meters beyond the product and is 2.5mx3.7m in size. The vertical surface is 2.5mx2.5m.
As with radiated emissions, the “human factor” is accounted for by the use of a “quasi-peak” detector in the receiver or spectrum analyzer that measures the signal from the LISN. For certain tests (such as EN55022), both an average and a quasi-peak limit are specified. Emissions from a device must be below both limits when measured with the appropriate detector. If the emission level is below the average limit when measured with the quasi-peak detector, the EUT is presumed to pass both limits.
The possible operating modes of the EUT are explored to determine the configuration that maximizes emissions. Software is investigated as well as different methods of displaying data if available. Data is recorded in the worst case operating mode.
As of September 9, 2002, the FCC has harmonized its conducted emission limits with CISPR. The following table displays the limits applicable to both FCC and CISPR.

One Distribution Center Circle, #1 • Littleton, MA • TEL (978) 486-8880 • FAX (978) 486-8828 | page 22 of 75

Line Conducted Emissions Limits: Class A (dBµV)

Frequency (MHz) | Quasi-Peak | Average
0.15 - 0.5 | 79 | 66
0.5 - 30 | 73 | 60

Line Conducted Emissions Limits: Class B (dBµV)

Frequency (MHz) | Quasi-Peak | Average
0.15 - 0.5 | 66 - 56* | 56 - 46*
0.5 - 5 | 56 | 46
5 - 30 | 60 | 50
Note 1: The lower limit applies at the transition frequencies
*Note 2: The limit decreases linearly with the logarithm of the frequency

At least the six highest emissions with respect to the limit are recorded. If less than six emissions are visible above the noise floor of the instrumentation, then the noise floor at six representative frequencies is recorded. The test report will document if noise floor readings are reported.
All testing is performed within the framework of a laboratory quality system modeled on ISO/IEC 17025 General requirements for the competence of calibration and testing laboratories and is subject to our terms and conditions. This test method is covered by our A2LA accreditation.

One Distribution Center Circle, #1 • Littleton, MA • TEL (978) 486-8880 • FAX (978) 486-8828 | page 23 of 75

TELCO CONDUCTED EMISSIONS

Test Method:
In accordance with the following:
- EN55022:2006/A1:2007
- VCCI

Results:

TEST | RESULT | TEST LEVEL | MARGIN | COMMENTS

Telco Line
Conducted
Emissions
| N/A | N/A | N/A | No telco cables

One Distribution Center Circle, #1 • Littleton, MA • TEL (978) 486-8880 • FAX (978) 486-8828 | page 24 of 75

ELECTROSTATIC DISCHARGE IMMUNITY

Test Method:

In accordance with EN 61000-4-2:2001.

Results:

TEST | RESULT | TEST METHOD | TEST LEVEL | COMMENTS
ESD | PASS | EN 61000-4-2

±4kV contact
±8kV air

Performance
Criteria B

One Distribution Center Circle, #1 • Littleton, MA • TEL (978) 486-8880 • FAX (978) 486-8828 | page 25 of 75

Electrostatic Discharge Immunity Data Table(s):

ESD DATA SHEET
Work Order: M2107
Date(s): 10-Oct-12 17-Oct-12
Engineer(s): Tuyen Truong, Saida Elfaquir
EUT: Ramos clock (Nixie) and Ramos clock Keypad
Company: Sammut Tech, LLC | Client Present: None

Testing Location: Littleton Distribution Center, One Distribution Center Circle, #1 Littleton, MA 01460 Performance Criteria: B
Maximum Test Parameters: | ±4kV contact | ±8kV air
EUT Operating Voltage/Frequency: 230Vac, 50Hz
Test Equipment Used:
ESD Generators | MN | Mfr | SN | Asset | Cat | Calibration Due
Green | NSG435 | Schaffner | 839 | 763 | I | 10/4/2013
Green | NSG435 | Schaffner | 839 | 763 | I | 10/4/2013
_
Oscilloscopes and Probes | MN | Mfr | SN | Asset | Cat | Calibration Due
ESD Reference 1GHz | TDS 684B | Tektronix | B011287 | Rental | I | 7/6/2013
_
Meteorological Meters | MN | Mfr | SN | Asset | Cat | Calibration Due
Temp./Humidity/Atm. Pressure Gauge | 7400 Perception I | Davis | N/A | 965 | I | 4/4/2013
CEMI1 Thermohygrometer | 35519-044 | Control Company | 72457738 | 1335 | II | 8/19/2013
CEMI2 Thermohygrometer | 35519-044 | Control Company | 72436083 | 1336 | II | 8/19/2013
_
Atmospheric Conditions:
10-Oct-2012 Temp: 22.9°C | Humidity: 32% | Pressure: 998mbar
17-Oct-2012 Temp: 21.8°C | Humidity: 22% | Pressure: 1006mbar
Test Points: | | Pass/Fail | Test Levels: | | | Comments:
Horizontal Coupling Plane | | Pass | ±2kV, ±4kV | | | normal and standby modes
Vertical Coupling Plane | | Pass | ±2kV, ±4kV
Contact Discharge Test Points | | Pass | ±2kV, ±4kV
Photo Label
All contact discharge points are labeled with a C on the photos provided.
Air Discharge Test Points | Pass | ±2kV, ±4kV, ±8kV
Photo Label
All air discharge points are labeled with an A. Points where a discharge occurred are listed below:
Discharge Point Description | Discharge Voltage
Around Alarm and controlled knobs | | | ±8kV

ESD Modifications:
None

Additional Modifications in place during testing:
See modification required for AC Line Conducted Emissions.

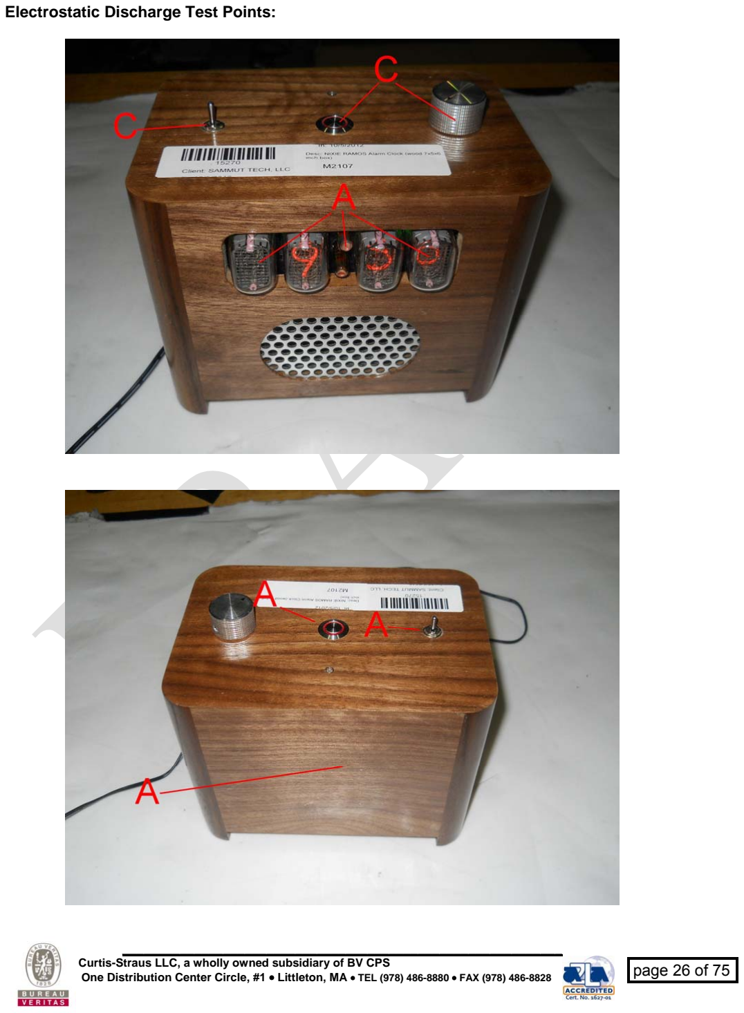
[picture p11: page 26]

One Distribution Center Circle, #1 • Littleton, MA • TEL (978) 486-8880 • FAX (978) 486-8828 | page 26 of 75

Electrostatic Discharge Test Points:

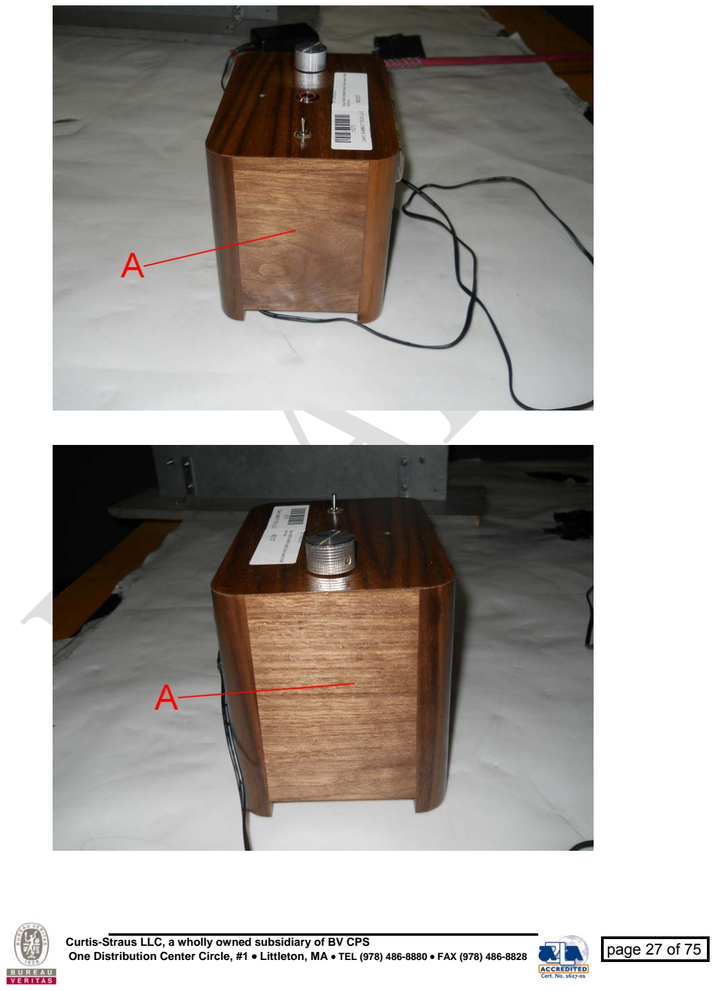
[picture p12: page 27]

One Distribution Center Circle, #1 • Littleton, MA • TEL (978) 486-8880 • FAX (978) 486-8828 | page 27 of 75

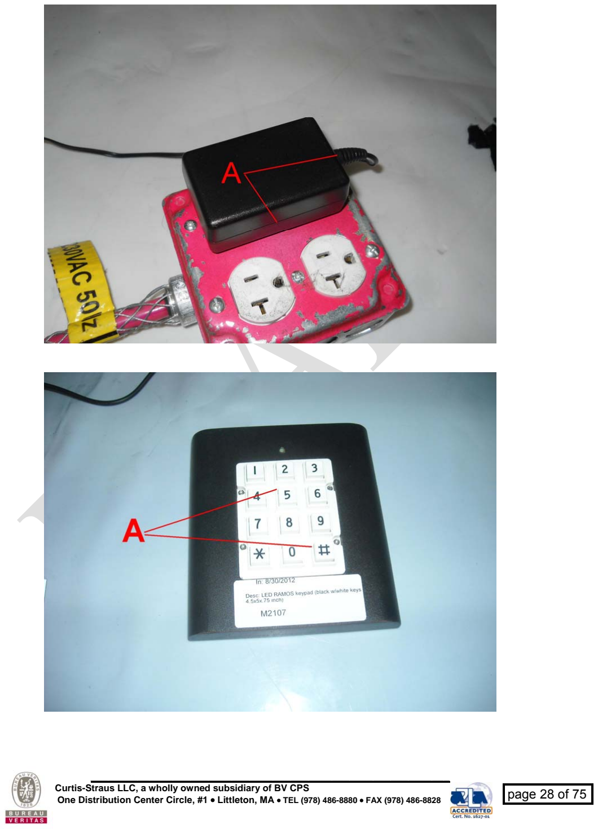
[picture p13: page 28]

One Distribution Center Circle, #1 • Littleton, MA • TEL (978) 486-8880 • FAX (978) 486-8828 | page 28 of 75

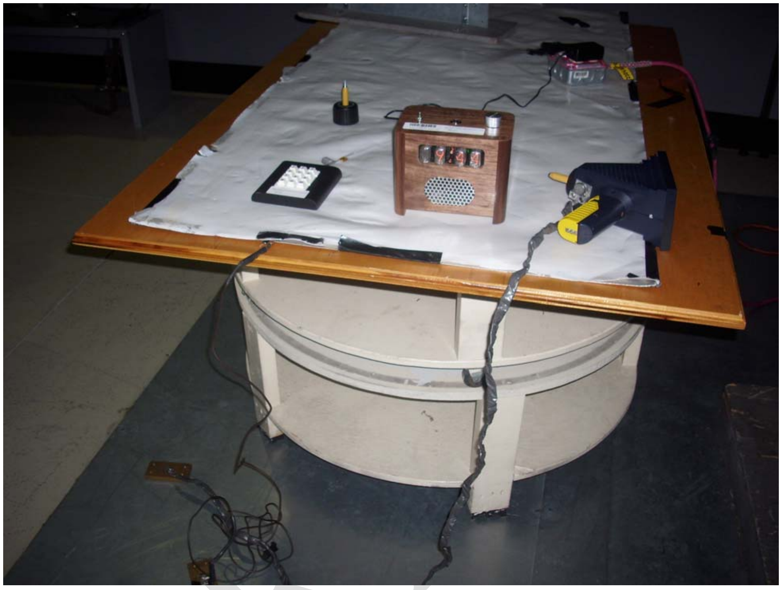
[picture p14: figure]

One Distribution Center Circle, #1 • Littleton, MA • TEL (978) 486-8880 • FAX (978) 486-8828 | page 29 of 75

Electrostatic Discharge Immunity Setup Photograph(s):

One Distribution Center Circle, #1 • Littleton, MA • TEL (978) 486-8880 • FAX (978) 486-8828 | page 30 of 75

Electrostatic Discharge Testing Overview

REV 17-FEB-04
Electrostatic charges build up on isolated materials under various conditions. One such condition is the rubbing of two materials together. When this occurs, the materials develop opposing charges. If they are isolated, this charge does not dissipate and will continue to accumulate. At some high level of voltage, depending on the material types and spacing, the insulation will break down and the charge will rapidly migrate in an attempt to reach equilibrium. This is what is commonly referred to as "Electrostatic Discharge" (ESD).
One example of materials rubbing creating an electrostatic buildup through friction is that of shoes (rubber, plastic, leather, etc.) on carpet (nylon, etc.), as a result of walking. A human body exhibits a capacitance depending on several factors including physical size. This capacitance stores the charge created by walking or other motions which can cause charge storage. The level of the stored voltage is limited by the size of the capacitance (human body is typically 100-400 pF) and the effects of leakage and corona discharge. Once the body accumulates charge, contact with a neutral or oppositely charged item causes a rapid discharge. The shape of the discharge waveform, and the amplitude of the discharge current, depend in part on the distributed capacitance and series resistance of the human body. A lumped element model of these distributed elements is commonly referred to as a human body model. The values of the lumped elements of the human body model, as well as the maximum charge voltage, vary widely. The model currently selected for use in EN 61000-4-2 is 330 Ohm/150 pF, usually with a charge voltage of 4kV contact mode/ 8 kV air discharge mode.
EN 61000-4-2 is the basic procedure for ESD testing. The preferred discharge method specified in EN 61000-4-2 is referred to as "contact discharge". In this method, a charged internal 150pF capacitor is isolated from the probe tip by a mechanical relay (typically filled with sodium hexaflorine gas). The tip is applied to a nearby metal surface or metal points on the product that the user may touch. The relay is then closed and the arc occurs within the relay, transferring the charge on the cap down the tip. If the product has insulated surfaces, then the “air discharge” method is also employed. In this method the relay is closed while the tip is at a great distance from the product. The tip is then brought to the insulated parts of the product at high speed. If an arc over occurs (though the insulation or more typically through cracks or slots) then that area is subject to more ESD stimulation.
For air discharge the high approach speed is especially important. As the length of the ionized air gap changes, it is necessary to control this variable. Some control can be exerted by making the discharge electrode approach the device under test at high speed. This high approach speed makes test results more repeatable because it reduces the variability of the discharge impedance.
The test site is assembled on top of a ground plane made of overlapping galvanized steel sheets 2.5m x 3.5m. The ground plane is connected to safety earth. Table top equipment is tested on an .8mx1.6m non-conductive table placed on this ground plane. If the tabletop system is especially large a second, separate table is added to support the additional equipment. A sheet of galvanized steel is placed on the tabletop. This plate is connected to the lower ground plane by a wire with 470k Ohm resistors at each end. The plate is called the Horizontal Coupling Plane (HCP). An additional .5mx.5m galvanized steel plate is used as a

One Distribution Center Circle, #1 • Littleton, MA • TEL (978) 486-8880 • FAX (978) 486-8828 | page 31 of 75

Vertical Coupling Plane (VCP). The VCP is also connected to the lower ground plane via a wire with 470k Ohm resistors at each end. Tabletop EUTs are isolated from the HCP by an insulator <.5mm thick. Typically a plastic sheet is employed. Floor standing equipment is tested on a 10cm insulator on top of the ground plane. For floor standing EUT configurations which do not have a tabletop component, an HCP is not part of the test setup as the ground plane is not an HCP. The EUT is grounded as normally installed.
The test begins with discharges to the HCP (if present) and VCP. All discharges are applied only in the contact discharge mode. 15 discharges are applied to the HCP 10cm from the EUT, at each of the four sides of the EUT at each voltage and polarity. Every voltage step of 2, 4, 6, 8kV is explored if below or equal to the maximum voltage to be applied. 15 discharges are also applied to the VCP held in four positions so that it illuminates in turn the four sides of the EUT. For large distributed floor standing systems, additional illumination points for the HCP and VCP are usually explored and will be noted in the test report. For EN55024, a minimum of four discharge points may be selected; this includes the coupling planes as well as the contact and air discharge points. The front center of the HCP must be one of the discharge points selected.
Once the indirect discharges to the coupling planes are done, testing moves on to direct discharges to the product itself. If the product is totally metal, only direct discharges are applied as that is the preferred mode. Air discharges are not performed to metal areas of the product. If the product has areas covered with an insulating material than those areas are subject to an air discharge test to see if an arc occurs. Contact discharges are not performed to insulated areas of the product. Some products are tested with only contact discharge (exclusively metal products) and some with only air discharge (insulated products such as those with plastic enclosures). Every voltage step in the standard is explored up to and including the maximum specified in the test. Thus 2 and 4 kV would be applied in a 4kV test. Each point subject to final ESD testing is noted in the test report.
While humidity is important in the charging of actual humans, it is much less important in the testing environment where a power supply within the ESD simulator controls very exactly the test voltage applied. For humans, the upper charging voltage achieved is limited by the bleed off of charge through the humidified atmosphere. EN 61000-4-2 requires air discharge testing to be performed with humidity in the range of 30% to 60%. Due to the lack of influence of humidity on ESD testing with ESD simulators operated with high approach speeds, we will occasionally perform testing outside of this range when atmospheric conditions warrant. Actual humidity conditions during the test are recorded on the test data sheet.
All testing is performed within the framework of a laboratory quality system modeled on ISO/IEC 17025 General requirements for the competence of calibration and testing laboratories and is subject to our terms and conditions. This test method is covered by our A2LA accreditation.

One Distribution Center Circle, #1 • Littleton, MA • TEL (978) 486-8880 • FAX (978) 486-8828 | page 32 of 75

RADIATED RADIO-FREQUENCY IMMUNITY

Test Method:

In accordance with EN 61000-4-3:2008.

Results:

TEST | RESULT | TEST METHOD | TEST LEVEL | COMMENTS
RFI | PASS | EN 61000-4-3

80-1000MHz
and 1.4-2.7GHz
at 3V/m
1KHZ 80% AM

Performance
Criteria A

One Distribution Center Circle, #1 • Littleton, MA • TEL (978) 486-8880 • FAX (978) 486-8828 | page 33 of 75

Radiated RF Immunity Data Table(s):

Work Order: M2107
| Date(s): 15-Oct-12 | 17-Oct-12
Engineer(s): Ami Soni, Adrian Gugushi
EUT: Ramos clock (Nixie) and Ramos clock Keypad
Company: Sammut Tech, LLC | Client Present: None

Testing Location: Littleton Distribution Center, One Distribution Center Circle, #1 - Littleton, MA 01460
Performance Criteria: A
Frequency Range: | 80-1000MHz | 1400-2700MHz
Maximum Field Strength: | 3V/m | 3V/m
Modulation: 1KHZ 80% AM
Dwell frequencies: none
EUT Operating Voltage/Frequency: 230Vac, 50Hz | EUT Cycle Time: continuous
Clock dwell frequencies include:
Test Equipment Used:
RFI Systems | Range | Equipment Combo | | | | Cat | Calibration Due
RFI 1 - Yellow Amp - Yellow-Black Bilog | 80 - 1000MHz | RFI Combo 18 | | | | II | 2/4/2013
RFI 1 | | 3 Meter Compact | Panashield | N/A | 797 | II
Yellow Amp | 80-1000MHz | 150W1000 | AR | 324607 | 1253 | II
Yellow-Black Bilog | 20-2000MHz | CBL6140A | Chase | 1112 | 126 | II
RFI 1 - High 1c - Red Horn - EU | 1 - 2GHz | RFI High Combo 1 | | | | II | 1/7/2013
RFI 1 | | 3 Meter Compact | Panashield | N/A | 797 | II
High 1c | 1.0-2 GHz | 8020H09F000 | Hughes | 257 | 1688 | II
Red Horn | 1-10GHz | 3115 | EMCO | | 1687 | II
RFI 1 - High 2 - Red Horn - EU | 2 - 4GHz | RFI High Combo 2 | | | | II | 1/7/2013
RFI 1 | | 3 Meter Compact | Panashield | N/A | 797 | II
High 2 | 2.0-4.0GHz | 1177H01 | Hughes | 55 | 1689 | II
Red Horn | 1-10GHz | 3115 | EMCO | | 1687 | II
_
Field Probes | Range | MN | Mfr | SN | Asset | Cat | Calibration Due
Blue | 0.01-1000MHz | HI-4422 | Holaday | 95696 | 1100 | I | 8/13/2013
_
Signal Generators | Range | MN | Mfr | SN | Asset | Cat | Calibration Due
Blue | 0.1-1000MHz | HP8648A | Agilent | 3426A00548 | 34 | I | 12/2/2012
Brown-White | 0.01Hz-15MHz | HP33120A | Agilent | SG40019842 | 1232 | I | 3/19/2013
Rental Sweeper | 0.01-20.0GHz | HP83752B | Agilent | 3610A01297 | Rental | I | 8/28/2013
_
Meteorological Meters | | MN | Mfr | SN | Asset | Cat | Calibration Due
Weather Clock (Pressure Only) | | BA928 | Oregon Scientific | C3166-1 | 831 | I | 3/28/2013
RFI1 Thermohygrometer | | 35519-044 | Control Company | 90823034 | 1499 | II | 4/4/2013
_
Cables | Range | | Mfr | | | Cat | Calibration Due
Asset #1722 | 1GHz -20GHz | | Florida RF | | | II | 1/31/2013
Asset #1723 | 1GHz -20GHz | | Florida RF | | | II | 1/31/2013
CRFI-RFI-05 | 9kHz - 2GHz | | C-S | | | II | 3/31/2013
RFI-High-08 | 1GHz - 10GHz | | C-S | | | II | 6/4/2013
_
Atmospheric Conditions:
17-Oct-2012 Temp: 22.7°C | Humidity: 29% | Pressure: 999mbar
15-Oct-2012 Temp: 24.3°C | Humidity: 31% | Pressure: 997mbar
Results:
| Front | Back | Left | Right | | | Comments
Horizontal | Pass | Pass | Pass | Pass | In Stand By mode, 80-1000MHz was tested only on front and left sides
Vertical | Pass | Pass | Pass | Pass | In Stand By mode, 80-1000MHz was tested only on front and left sides

RFI DATA SHEET

None in this range.

RFI Modifications:
None

Additional Modifications in place during testing: See modification required for AC Conducted Emissions.

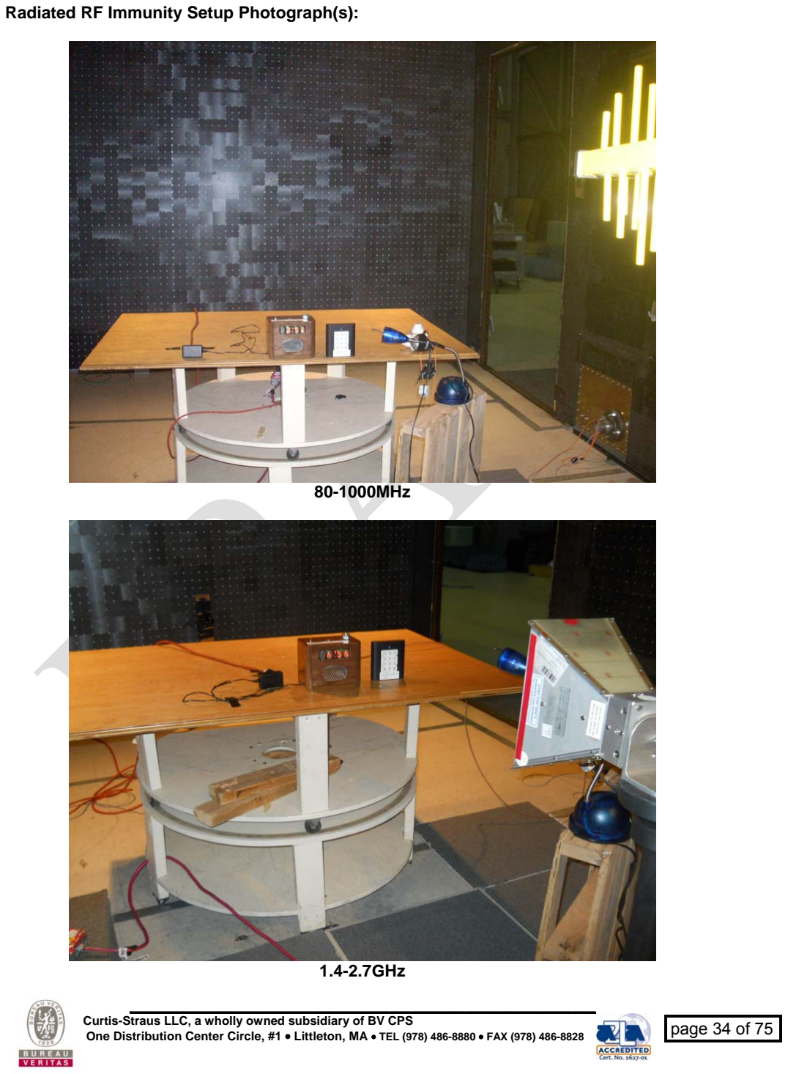
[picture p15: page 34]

One Distribution Center Circle, #1 • Littleton, MA • TEL (978) 486-8880 • FAX (978) 486-8828 | page 34 of 75

Radiated RF Immunity Setup Photograph(s):

80-1000MHz

1.4-2.7GHz

One Distribution Center Circle, #1 • Littleton, MA • TEL (978) 486-8880 • FAX (978) 486-8828 | page 35 of 75

Radiated RF Immunity Testing Overview
REV 13-SEP-07
Radiated fields result from many sources. In today's environment the RF spectrum is crowded by broadcast media (radio and TV), cellular phone systems, telemetry, amateur radio, radio navigation aids, industrial scientific, medical (ISM) devices, etc. All of which have the potential to disturb electronic products.
The development of test standards is based on statistical analysis of various RF sources within these allocations. In some rare cases, electrical field levels can reach hundreds of volts per meter (e.g. - an installation close to a high power broadcast transmitter). At other, remote locations, fields are usually less than 1 V/m. Modulation types and levels also vary from site to site.
The generic immunity standard for residential, commercial and light industrial environments EN 50082-1 and EN61000-6-1 specify the EN 61000-4-3 test methodology and applies a field intensity level of 3 V/m in the frequency range of 80 to 1000 MHz. The 3V/m field intensity, which corresponds to Severity Level 2 as specified in EN 61000-4-3, is generated with 1kHz, 80% depth amplitude modulation.
The generic heavy industrial immunity specification EN 61000-6-2 specifies the EN 61000-4-3 test methodologies. It applies a field intensity level of 10 V/m in the frequency range of 80 to 1000 MHz with reductions to 3 V/m in the European TV bands of 87-108 MHz, 174-230 MHz, and 470-790 MHz. The 3V/m field intensity, which corresponds to Severity Level 2 as specified in EN 61000-4-3, is generated with 1kHz, 80% depth amplitude modulation. Other test levels and frequency ranges may be explored depending on client request. Frequency ranges, field strength levels, and modulation schemes are recorded on the test data sheets.
The field levels specified in EN 61000-4-3, while generally lower than accepted safe human exposure levels, can cause harmful interference to communications and other electronics. For this reason, testing for radiated immunity must be conducted in a controlled area. This controlled area may be a RF shielded enclosure, a Transverse Electromagnetic (TEM) cell (also known as a Crawford cell) or an RF absorber lined shielded enclosure. Most testing is performed in a shielded enclosure.
Power is applied to the EUT in its normal operating condition either through an AC power cord, from an external power supply or battery. In the case of DC units, the power supply or battery is placed on the floor of the shielded enclosure.
Any Test Support Equipment (TSE) which is used to operate or monitor the performance of the EUT is placed either outside of the shielded enclosure or at such a distance that it is unaffected by the field. In cases where cable length prohibits placement of the TSE outside the enclosure, the TSE is placed on the enclosure floor or otherwise isolated from the radiated field. Unless specified by the manufacturer, all interface cabling used is twisted pair wire which is unshielded for at least 1m from the EUT. I/O cables are terminated in their normal resistance as specified by the manufacturer. All cables beyond 1m may be shielded to prevent additional coupling. All cables which exit the shielded enclosure are filtered or suppressed using ferrite beads to prevent affecting the TSE.
In cases where no TSE is used to monitor EUT performance, a closed circuit TV camera may be set up inside the shielded enclosure. The camera is used to monitor any performance

One Distribution Center Circle, #1 • Littleton, MA • TEL (978) 486-8880 • FAX (978) 486-8828 | page 36 of 75

indications. The TV monitor can be located outside the enclosure and the EUT is observed for performance deviations during testing.
The RF field is generated by linearly polarized antennas such as bicon/log periodic hybrid antennas. The antenna is set up at a distance of 1m from the EUT. A signal generator is set up outside of the enclosure and connected by a coaxial cable to a 10 watt broadband amplifier. The output of the amplifier is connected via coaxial cable to the transmitting antenna. An isotropic field probe is placed near the EUT to monitor the field strength present at the EUT. For EN 61000-4-3 and similar standards, the signal generator and amplifier are adjusted by a leveling computer to generate a constant field as the signal generator is tuned from 80 to 1000 MHz at a rate of approximately 10 minutes per decade (.0015 decades/second). Step size for the frequency tuning is 1%. As the frequency is tuned, the signal generator output amplitude is adjusted by the computer to maintain the required field strength. The amplitudes are then reproduced for the desired immunity disturbance level once the EUT is configured inside the enclosure. In each frequency band, the test is performed with the antenna in both horizontal and vertical polarization, for each of the 4 sides of the EUT.
For EN 61000-4-3, the enclosure is calibrated without the EUT present. The 1.5m x 1.5m field is uniform within 0 to +6dB of the calibration level. At the 40cm height, the field is uniform within -12 to +6dB of the calibration level. The distance between the UFA and the antenna is 3m.
In the event of an operating anomaly, the transmitting frequency and the nature of the anomaly is recorded. The field strength is reduced until the normal operation is restored. This field strength is recorded as the threshold of susceptibility. After the device is characterized in the required environment, modifications are made to the EUT to improve immunity as appropriate. In some cases, the EUT is extremely sensitive at several frequencies. In these instances, characterization testing may be terminated early to preclude damage.
All testing is performed within the framework of a laboratory quality system modeled on ISO/IEC 17025 General requirements for the competence of calibration and testing laboratories and is subject to our terms and conditions. This test method is covered by our A2LA accreditation.

One Distribution Center Circle, #1 • Littleton, MA • TEL (978) 486-8880 • FAX (978) 486-8828 | page 37 of 75

ELECTRICAL FAST TRANSIENTS IMMUNITY

Test Method:

In accordance with EN 61000-4-4:2004.

Results:

TEST | RESULT | TEST METHOD | TEST LEVEL | COMMENTS
EFT | PASS | EN 61000-4-4 | ±1kV AC

Performance
Criteria B

One Distribution Center Circle, #1 • Littleton, MA • TEL (978) 486-8880 • FAX (978) 486-8828 | page 38 of 75

Electrical Fast Transient Burst Immunity Data Table(s):

EFT DATA SHEET
Work Order: M2107
Date(s): 10-Oct-12 17-Oct-12
Engineer(s): Tuyen Truong, Saida Elfquir
EUT: Ramos clock (Nixie) and Ramos clock Keypad
Company: Sammut Tech, LLC | Client Present: None scan

Testing Location: Littleton Distribution Center, One Distribution Center Circle, #1 Littleton, MA 01460
Performance Criteria: B
Maximum Test Parameters: | ±1kV AC
EUT Operating Voltage/Frequency: 230Vac, 50Hz
Test Equipment Used:
EFT | MN | Mfr | SN | ASSET | Cat | Calibration Due
CAS 3025 Burst Verification Attenuators | INA 265A/266 | Schaffner | 20096 | 947 | II | 6/1/2013
Modula6150 | Modula6150 | Teseq | 34525 | 1268 | I | 6/18/2013
_
Meteorological Meters | MN | Mfr | SN | Asset | Cat | Calibration Due
Temp./Humidity/Atm. Pressure Gauge | 7400 Perception II | Davis | N/A | 965 | I | 4/4/2013
CEMI1 Thermohygrometer | 35519-044 | Control Company | 72457738 | 1335 | II | 8/19/2013
CEMI2 Thermohygrometer | 35519-044 | Control Company | 72436083 | 1336 | II | 8/19/2013
_
Atmospheric Conditions:
10-Oct-2012 Temp: 22.9°C | Humidity: 32% | Pressure: 998mbar
17-Oct-2012 Temp: 21.8°C | Humidity: 22% | Pressure: 1006mbar
Test Points: | | Pass/Fail/NA | | Comments:
AC/DC Power Brick | Pass | normal and standby modes

EFT Modifications:
None

Additional Modifications in place during testing:
See modification required for AC Line Conducted Emissions.

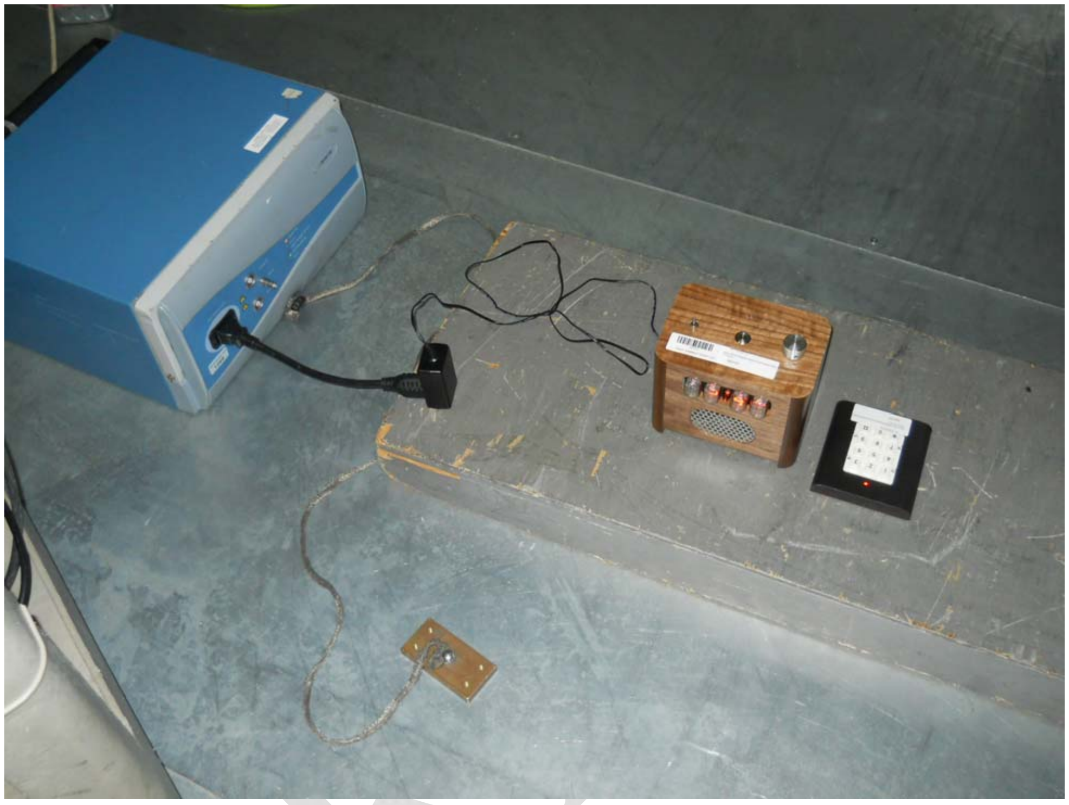
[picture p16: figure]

One Distribution Center Circle, #1 • Littleton, MA • TEL (978) 486-8880 • FAX (978) 486-8828 | page 39 of 75

Electrical Fast Transient Burst Immunity Setup Photograph(s):

One Distribution Center Circle, #1 • Littleton, MA • TEL (978) 486-8880 • FAX (978) 486-8828 | page 40 of 75

Electrical Fast Transient Burst Testing Overview

REV 18-MAR-04
High-voltage transients are developed on the power mains as a result of numerous types of switching actions. The interruption of current to inductive loads, relay contact bounce, and other actions may cause transients of several thousands of volts. These transients are characterized by very fast rise times and short pulse widths. They typically occur in bursts, with repetition rates as high as 100 kHz.
With the fast rise time associated with the transient, the energy content of the waveform extends to several hundred megahertz. With this high frequency content, the generated noise exists not only on the power lines, but also as noise coupled to the control and signal lines.
The basic measurement standard for these Electrical Fast Transient Bursts (EFT) is EN 61000-4-4. This standard specifies transients with a double exponential waveshape. The rise time of the pulse is 5 nS, and the pulse width is 50 nS. The transients are injected in 15 mS bursts with a repetition rate between individual pulses of 5 kHz. The period between each burst is 300 mS.
The test equipment necessary to generate the required bursts usually uses an energy storage capacitor and high voltage source to charge the capacitor. The capacitor is charged to a specified high voltage and discharged into a discharge shaping resistor. The interaction of the storage capacitor and the discharge resistor determine the fall time of the pulse. The rise time of the waveform depends on the inductance in the discharge path, and the capacitance to ground. The standard (EN 61000-4-4) specifies that the transient generator should have a source impedance of 50 Ohms and that signal characteristics should be measured with the generator loaded with a matched 50 Ohm impedance.
EN 61000-4-4 offers a choice between two different test set-ups. The first is for a "field test" which is performed in actual installed conditions. In the case of a stationary, floor-mounted EUT, a 1m x 1m reference ground plane is placed near the EUT and grounded to the protective earth at the electrical mains outlet. The plane must be a metallic sheet of at least 0.25mm thick if made of copper or aluminum, or 0.65mm thick if made of other metal. The transient generator is located on the ground plane and grounded directly to the plane. The transient output of the generator is connected by an unshielded wire through a 33 nF capacitor to each of the power supply terminals and the protective earth terminal.
For field tests on non-stationary equipment, the EUT is in a normal configuration, and no artificial ground plane is used. The transient is injected between each power supply terminal and the protective earth terminal at the mains outlet to which the EUT is connected.
"Type tests", which are performed in a laboratory, use a somewhat different set-up. Our tests are type tests unless otherwise noted.
During laboratory tests, all equipment whether floor standing or tabletop must be mounted on a ground plane. The ground plane is 2.5m x 3.5m and is made of galvanized sheet steel. It is connected to the green wire of protective earth of the facility.
In the case of floor standing equipment, the EUT is placed on the groundplane and insulated from it by a 10 cm support. The EUT is configured and operated in accordance with its normal installation procedures. Any conductive structures located near the EUT must be a minimum of 50 cm from it. All connections to earth ground, whether the "green wire safety

One Distribution Center Circle, #1 • Littleton, MA • TEL (978) 486-8880 • FAX (978) 486-8828 | page 41 of 75

ground" or cable shields, etc., are made in accordance with manufacturer's specifications. No additional connections of the chassis or ground system to the ground plane are permitted.
For tabletop equipment, the EUT is mounted approximately 0.8m above the reference ground plane. This is accomplished by placing the device on a wooden table. The requirements for ground plane size and connection to the ground plane by the EUT are the same as floor standing equipment.
The EFT test voltages are applied to the EUT in three basic configurations. First, the injection is performed on power supply inputs through a coupling network. This network consists of a capacitor to inject the signal onto the power line, and a decoupling network to prevent the injected signals from being impressed on the AC mains supply. They are built into the test equipment. The test voltage is applied between each power line individually with respect to earth ground. For higher current applications, the transient is injected using a discrete 33 nF capacitor into the power lines.
The second configuration involves injection of the EFT bursts onto I/O circuits and communication lines. This injection requires the use of a capacitive coupling clamp. The appropriate I/O cables are placed inside the coupling clamp and the specified peak voltage is injected between the coupling clamp and ground plane. The coupling clamp is placed at a distance of 1m or less from the EUT. In cases where the I/O cables exceeds 1m in length, the excess length is coiled, with a 0.4m diameter, and placed 10 cm above the ground plane. In the case of an uninterruptible power source tested to the requirements of EN50091-2, all cabling including AC input and output cabling and communication lines is conditioned using this injection method.
The third injection point is the earth connection of the EUT. In general, this earth connection is the "green wire ground" connected via the power cable. In some cases, additional grounding points may be installed. In these cases, the transient voltage is injected through the coupling network into these ground terminals as well. The EFT is injected via a coupling network similar to the power line injection method.
EN 61000-4-4 specifies that the bursts are injected for a period of 1 minute or more each configuration and polarity. Longer times are used for equipment with longer cycle times in order to apply the bursts during all EUT states. Injection is usually performed first at lower levels and then increased incrementally to the specification level. This incremental method again is performed in order to increase the probability of detecting anomalies before any potential damage is suffered at the higher voltage levels.
In the case of any anomalies, the peak level of the transient voltage is recorded, as well as the nature of the anomaly and the injection point.
All testing is performed within the framework of a laboratory quality system modeled on ISO/IEC 17025 General requirements for the competence of calibration and testing laboratories and is subject to our terms and conditions. This test method is covered by our A2LA accreditation.

One Distribution Center Circle, #1 • Littleton, MA • TEL (978) 486-8880 • FAX (978) 486-8828 | page 42 of 75

SURGE IMMUNITY

Test Method:

In accordance with EN 61000-4-5:2005.

Results:

TEST | RESULT | TEST METHOD | TEST LEVEL | COMMENTS
AC Surge | PASS | EN 61000-4-5

±1kV Line-Line
±2kV Line-Earth

Performance
Criteria B
DC Surge | N/A | EN 61000-4-5 | N/A

EUT is AC
powered

Signal/Telco
Surge
N/A | EN 61000-4-5 | N/A | No signal/telco cables

One Distribution Center Circle, #1 • Littleton, MA • TEL (978) 486-8880 • FAX (978) 486-8828 | page 43 of 75

Surge Immunity Data Table(s):

SURGE DATA SHEET
Work Order: M2107
Date(s): 10-Oct-12 17-Oct-12
Engineer(s): Tuyen Truong, Saida Elfaquir
EUT: Ramos clock (Nixie) and Ramos clock Keypad
Company: Sammut Tech, LLC | Client Present: None

Testing Location: Littleton Distribution Center, One Distribution Center Circle, #1 Littleton, MA 01460

Performance Criteria: B

Maximum Test Parameters: | Input and Output AC Power Ports
Open Circuit Waveshape (Tr/Th): | 1.2/50µs | Repitition Rate: 1 surge per minute
Voltage | Impedance / Current | Reps/Polarity/Phase Angle: 5 (maximum test level)
| Line-to-earth: | ±2kV | 12Ω | | | | 1 (lower test levels)
| Line-to-line: | ±1kV | 2Ω
EUT Operating Voltage/Frequency: | 230Vac, 50Hz

Test Equipment Used:
LISNs/Measurement Probes | Range | MN | Mfr | SN | Asset | Cat | Calibration Due
Surge Current Probe | NA | CM-1-L | Ion Physics | NA | 1276 | I | 5/23/2013
_
Oscilloscopes and Probes | | MN | Mfr | SN | Asset | Cat | Calibration Due
EMC 100MHz | | TDS 220 | Tektronix | C036986 | 1166 | I | 1/27/2013
Transient Waveform Monitor - Voltage | | TWM-5 | CDI | N/A | 1533 | II | 7/10/2013
_
Surge Generators | | MN | Mfr | SN | Asset | Cat | Calibration Due
Modula6150 | | Modula6150 | Teseq | 34525 | 1268 | I | 6/24/2013
_
Meteorological Meters | | MN | Mfr | SN | Asset | Cat | Calibration Due
Temp./Humidity/Atm. Pressure Gauge | | 7400 Perception II | Davis | N/A | 965 | I | 4/4/2013
CEMI1 Thermohygrometer | | 35519-044 | Control Company | 72457738 | 1335 | II | 8/19/2013
CEMI2 Thermohygrometer | | 35519-044 | Control Company | 72436083 | 1336 | II | 8/19/2013
_
Atmospheric Conditions:
10-Oct-2012 Temp: 22.9°C | Humidity: 32% | Pressure: 998mbar
17-Oct-2012 Temp: 21.8°C | Humidity: 22% | Pressure: 1006mbar
Test Points:
AC/DC Power Brick | Test Level | Pass/Fail | Phase Angle | Comment
Line - Neutral | ±0.5kV | Pass | 0°, 90°, 180°, 270° normal and standby modes
Line - Neutral | ±1kV | Pass | 0°, 90°, 180°, 270°
Line - Ground | ±0.5kV | Pass | 0°, 90°, 180°, 270°
Line - Ground | ±1kV | Pass | 0°, 90°, 180°, 270°
Line - Ground | ±2kV | Pass | 0°, 90°, 180°, 270°
Neutral - Ground | ±0.5kV | Pass | 0°, 90°, 180°, 270°
Neutral - Ground | ±1kV | Pass | 0°, 90°, 180°, 270°
Neutral - Ground | ±2kV | Pass | 0°, 90°, 180°, 270°

Surge Modifications:
None

Additional Modifications in place during testing:
See modification required for AC Line Conducted Emissions.

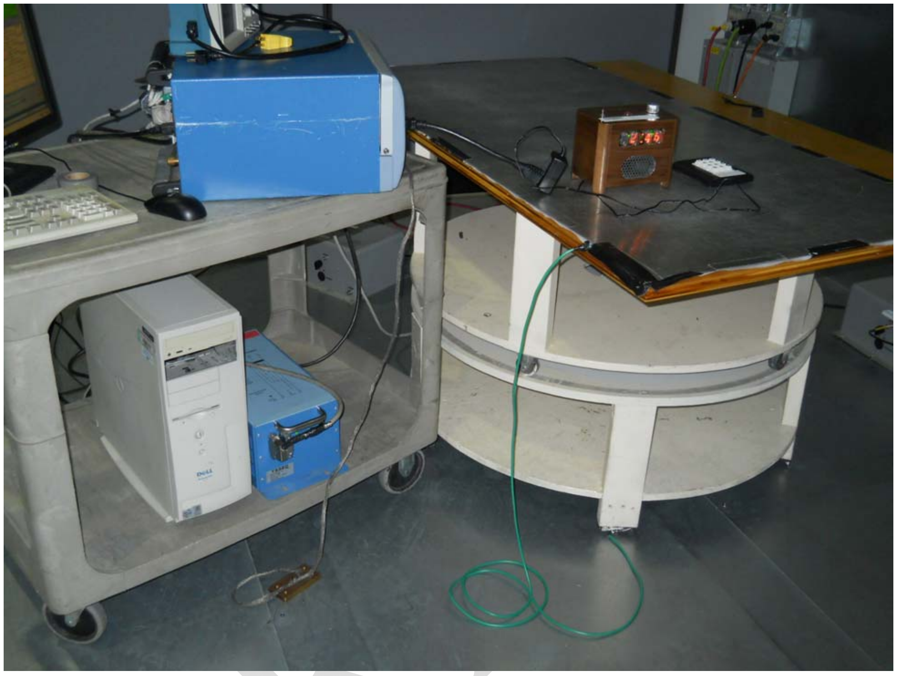
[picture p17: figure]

One Distribution Center Circle, #1 • Littleton, MA • TEL (978) 486-8880 • FAX (978) 486-8828 | page 44 of 75

Surge Immunity Setup Photograph(s):

One Distribution Center Circle, #1 • Littleton, MA • TEL (978) 486-8880 • FAX (978) 486-8828 | page 45 of 75

Power Line Lightning Transient Testing

REV 17-FEB-04
Power lines are subjected to surges which result primarily from lightning events. Typical lightning waveforms, are specified in EN 61000-4-5. The transients specified are double exponential waveforms with a rise time of 1.2 µS and a pulse width of 50 µS (open circuit). The short circuit waveform is an 8 x 20 µS double exponential. The usual level for longitudinal common mode injection AC power ports is 2 kV open circuit with a short circuit current of 1 kA. In the differential mode (between phase and neutral) the peak level is limited to 1 kV. The surges are injected in both positive and negative polarities into the AC line at phase angles between 0 and 360º. A CDI M5 Universal Surge Generator™ is used to generate the appropriate waveshapes and amplitudes.
For the EN 61000-4-5 test method, 5 repetitions are applied in each polarity and at the 0, 90, 180, and 270 points of the AC cycle. Surges are applied from each line to ground using a 12 Ohm source impedance and from each line to every other line combination (including neutral) using a 2 Ohm source impedance. DC power ports and some signal lines are also subjected to 1.2 x 50 µS lightning surges. In this case, however, the peak voltage is usually limited to 500 volts in both common and differential mode.
All testing is performed within the framework of a laboratory quality system modeled on ISO/IEC 17025 General requirements for the competence of calibration and testing laboratories and is subject to our terms and conditions. This test method is covered by our A2LA accreditation.

One Distribution Center Circle, #1 • Littleton, MA • TEL (978) 486-8880 • FAX (978) 486-8828 | page 46 of 75

CONDUCTED RADIO FREQUENCY IMMUNITY

Test Method:

In accordance with EN 61000-4-6:2007.

Results:

TEST | RESULT | TEST METHOD | TEST LEVEL | COMMENTS
CRFI | PASS | EN 61000-4-6

0.15-80MHz
3Vrms
1kHz 80% AM

Performance
Criteria A

One Distribution Center Circle, #1 • Littleton, MA • TEL (978) 486-8880 • FAX (978) 486-8828 | page 47 of 75

Conducted RF Immunity Data Table(s):

CRFI DATA SHEET
Work Order: M2107
| Date(s): 10-Oct-12 | 16-Oct-12
Engineer(s): Tuyen Truong and Karl Klemm
EUT: Ramos clock (Nixie) and Ramos clock Keypad
Company: Sammut Tech, LLC | Client Present: None scan

Testing Location: Littleton Distribution Center, One Distribution Center Circle, #1 Littleton, MA 01460

Performance Criteria: A
Frequency Range: | 0.15-80MHz
Signal Level: | 3Vrms
Modulation: 1KHZ 80% AM
Dwell frequencies: 0.2, 1, 7.1, 13.56, 21, 27.12, 40.68 MHz
EUT Operating Voltage/Frequency: 230Vac, 50Hz | EUT Cycle Time: Continuous
Clock Frequencies:

Test Equipment Used:
CRFI Systems | Range | Equipment Combo | | | | Cat | Calibration Due
Blue Amp - Asset 1653 M2 | 0.10 - 100MHz | CRFI Combo 29 | | | | II | 1/4/2013
Blue Amp | 0.01-250MHz | 75A250 | AR | 19165 | 39 | II
Asset 1653 M2 | 0.1-100MHz | CDN M2-25 | COM-Power | 511026 | 1653 | II
Black Amp - Asset 1654 M2 | 0.10 - 100MHz | CRFI Combo 3 | | | | II | 1/5/2013
Black Amp | 0.01-100MHz | 75A250 | AR | 23411 | 122 | II
Asset 1654 M2 | 0.1-100MHz | CDN M2-25 | COM-Power | 511037 | 1654 | II
_
Signal Generators | Range | MN | Mfr | SN | Asset | Cat | Calibration Due
Blue | 0.1-1000MHz | HP8648A | Agilent | 3426A00548 | 34 | I | 12/2/2012
Orange | 0.1-1000MHz | HP8648B | Agilent | 3537A01210 | 25 | I | 10/5/2013
_
Meteorological Meters | | MN | Mfr | SN | Asset | Cat | Calibration Due
Temp./Humidity/Atm. Pressure Gauge | | 7400 Perception II | Davis | N/A | 965 | I | 4/4/2013
CEMI1 Thermohygrometer | | 35519-044 | Control Company | 72457738 | 1335 | II | 8/19/2013
Weather Clock (Pressure Only) | | BA928 | Oregon Scientific | C3166-1 | 831 | I | 3/28/2013
CEMI2 Thermohygrometer | | 35519-044 | Control Company | 72436083 | 1336 | II | 8/19/2013
_
Cables | Range | | Mfr | | | Cat | Calibration Due
CRFI-RFI-05 | 9kHz - 2GHz | | C-S | | | II | 3/31/2013
CRFI-RFI-13 | 9kHz - 2GHz | | C-S | | | II | 8/31/2013
CRFI-RFI-16 | 9kHz - 2GHz | | C-S | | | II | 9/19/2013
CRFI-RFI-36 | 9kHz - 2GHz | | C-S | | | II | 3/31/2013
_
Atmospheric Conditions:
10-Oct-2012 Temp: 22.9°C | Humidity: 32% | Pressure: 998mbar
16-Oct-2012 Temp: 22.8°C | Humidity: 25% | Pressure: 995mbar
Test Points: | Pass/Fail/NA | Comments:
AC/DC Power Brick | Pass | normal and standby modes

8 and 32 MHz

CRFI Modifications:
None

Additional Modifications in place during testing:
See modification required for AC Line Conducted Emissions.

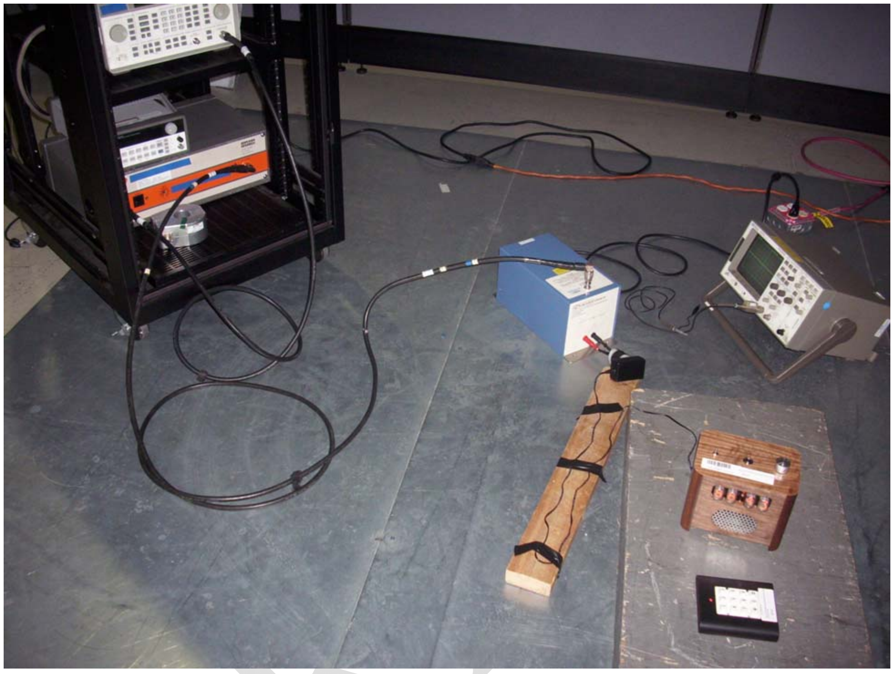
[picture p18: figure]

One Distribution Center Circle, #1 • Littleton, MA • TEL (978) 486-8880 • FAX (978) 486-8828 | page 48 of 75

Conducted RF Immunity Setup Photograph(s):

One Distribution Center Circle, #1 • Littleton, MA • TEL (978) 486-8880 • FAX (978) 486-8828 | page 49 of 75

Conducted RF Immunity Testing Overview

REV 17-FEB-04
At lower frequencies it is difficult to design a radiating test source to simulate the coupling that occurs in the real world due to radiated fields. For all testing below 26MHz and occasionally for testing as high as 230MHz, Conducted RF (sometimes called “bulk current injection”) is utilized to simulate radiated field disturbances.
Radiated fields result from many sources. In today's environment the RF spectrum is crowded by broadcast media (radio and TV), cellular phone systems, telemetry, amateur radio, radio navigation aids, industrial scientific and medical (ISM) devices, and others, all of which have the potential to disturb electronic products.
Development of test standards is based on statistical analysis of various RF sources within these allocations. In some rare cases, electrical field levels can reach hundreds of volts per meter (e.g. - an installation close to a high power broadcast transmitter). At other, remote locations, fields are usually less than 1 V/m. Modulation types and levels also vary from site to site. For stimulation from a 150 Ohm RF source, EN 61000-4-6 has set a level of 1 V open circuit as equivalent to 1 V/m.
The EUT is configured on a 0.1 meter high non-conductive platform over a ground plane which extends at least 0.5 meters beyond the edge of the EUT. All vertical conducting surfaces are at a distance of at least 0.5 meters. Where possible, each cable leaving the EUT is terminated in an equivalent 150 Ohm common mode load. The purpose of the test is to have RF current flow through the EUT as if it was the center of a dipole made from it and its cables. Thus one cable is stimulated at a time with a 150 Ohm RF source and the current flows to the EUT and out to the cables which are passively terminated to the ground plane in 150 Ohm common mode loads. For shielded (screened) cables, the shield is the injection point. For unshielded cables either a decoupling network with a total parallel impedance of 150 Ohms or a bulk current injection clamp is utilized to inject the disturbance. For the AC mains, a decoupling network with 150 Ohm parallel RF impedance is used.
The signal generator and amplifier are adjusted by a computer using predetermined signal levels derived during a calibration routine. During calibration, a 150 Ohm load is driven by the signal generator and the coupling network or clamp being calibrated. Signal levels at specific frequencies required to produce the desired stimulation level are recorded. The stimulation level desired is one-half that the open circuit voltage as the 150 Ohm source is loaded with 150 Ohms. If a bulk current probe is used, a second measurement current probe is inserted over the cable and the signal level is reduced if the current exceeds that which would be injected into a 150 Ohm load.
For complex EUT’s, not all possible conduction paths are explored. In accordance with EN 61000-4-6, n paths are evaluated, where 2 ≤ n ≤ 5. This is assumed to adequately stimulate the EUT and expose failures. The paths are picked based on an evaluation of the EUT architecture and are expected to be the most vulnerable to the conducted disturbances. The test report will detail the paths selected for stimulation.
In the event of an operating anomaly, the frequency and the nature of the anomaly is recorded. The signal strength is reduced until the normal operation is restored. The equivalent open circuit voltage is recorded as the threshold of susceptibility. After the device is characterized

One Distribution Center Circle, #1 • Littleton, MA • TEL (978) 486-8880 • FAX (978) 486-8828 | page 50 of 75

in the required environment, modifications are made to the EUT to improve immunity as appropriate. In some cases, the EUT is extremely sensitive at several frequencies. In these instances, characterization testing may be terminated early to preclude damage.
All testing is performed within the framework of a laboratory quality system modeled on ISO/IEC 17025 General requirements for the competence of calibration and testing laboratories and is subject to our terms and conditions. This test method is covered by our A2LA accreditation.

One Distribution Center Circle, #1 • Littleton, MA • TEL (978) 486-8880 • FAX (978) 486-8828 | page 51 of 75

VOLTAGE DIPS AND INTERRUPTS IMMUNITY

Test Method:

In accordance with EN 61000-4-11:2004.

Results:

TEST | RESULT | TEST METHOD | TEST LEVEL | COMMENTS

Voltage Dips
and Short
Interruptions

PASS EN 61000-4-11

0%V for 0.5 and 1
cycle (B)
70%V for 25/30
cycles (C)
0%V 250/300
cycles (C)

One Distribution Center Circle, #1 • Littleton, MA • TEL (978) 486-8880 • FAX (978) 486-8828 | page 52 of 75

Mains Supply Voltage Dips, Short Interrupts and Variations Data Table(s):

VOLTAGE DIPS AND INTERRUPTS DATA SHEET
Work Order: M2107
Date(s): 10-Oct-12 17-Oct-12
Engineer(s): Tuyen Truong, Saida Elfaquir
EUT: Ramos clock (Nixie) and Ramos clock Keypad
Company: Sammut Tech, LLC | Client Present: None

Testing Location:

Maximum Test Parameters: 100% Voltage Reduction | 5.0 Seconds
Test Equipment Used:
Dips and Interrupts | MN | Mfr | SN | Asset | Cat | Calibration Due
Modula6150 | Modula6150 | Teseq | 34525 | 1268 | I | 4/28/2013
INA 6502 Automatic Steptransformer | INA 6502 | Teseq | 105 | 1269 | I | 4/28/2013
_
RMS Voltmeters/Current Clamp | MN | Mnfr | SN | Asset | Cat | Calibration Due
D+I Verification DMM | 115 | Fluke | 94470416 | 1294 | I | 5/21/2013
_
Meteorological Meters | MN | Mfr | SN | Asset | Cat | Calibration Due
Temp./Humidity/Atm. Pressure Gauge | 7400 Perception II | Davis | N/A | 965 | I | 4/4/2013
CEMI1 Thermohygrometer | 35519-044 | Control Company | 72457738 | 1335 | II | 8/19/2013
_
Atmospheric Conditions:
10-Oct-2012 Temp: 22.9°C | Humidity: 32% | Pressure: 998mbar
17-Oct-2012 Temp: 21.8°C | Humidity: 22% | Pressure: 1006mbar

EUT Low Voltage: 100Vac, 60Hz
%V | Duration | Criteria | Result | Comment
0% | 0.5 cycle | B | Pass | 90°,270° | normal and standby modes
0% | 1 cycle | B | Pass
70% | 30 cycles | B | Pass
0% | 300 cycles | C | Pass

EUT High Voltage: 230Vac, 50Hz
%V | Duration | Criteria | Result | Comment
0% | 0.5 cycle | B | Pass | 90°,270°
0% | 1 cycle | B | Pass
70% | 25 cycles | B | Pass
0% | 250 cycles | C | Pass

Littleton Distribution Center, One Distribution Center Circle, #1 Littleton, MA 01460

Dips and Interrupts Modifications:
None

Additional Modifications in place during testing:
See modification required for AC Line Conducted Emissions.

One Distribution Center Circle, #1 • Littleton, MA • TEL (978) 486-8880 • FAX (978) 486-8828 | page 53 of 75

Mains Supply Voltage Dips, Short Interrupts and Variations Setup Photograph(s):

One Distribution Center Circle, #1 • Littleton, MA • TEL (978) 486-8880 • FAX (978) 486-8828 | page 54 of 75

Mains Supply Voltage Dips, Short Interrupts and Variations
REV 17-FEB-04
A device connected to an a.c. mains distribution network will often experience changes, abrupt or gradual, in the voltage level seen on the line due to activity on the network. This includes reductions, interruptions and variations in voltage associated with load switching and operation of protection devices.
A voltage dip is a sudden reduction of the supply voltage at a particular node in the distribution network which is followed by voltage recovery after a short period of time (0.5 cycles to a few seconds). A short interrupt is the disappearance of this supply voltage for a period of time (usually less than 1 minute); it is a voltage dip with 100% (>95%) amplitude. If the change to the supply voltage is gradual, it is considered a voltage variation. A voltage variation can be higher or lower than the rated voltage, and the duration of change can be short or long with regard to the period. These phenomena are often random and can be characterized in terms of duration and deviation from the rated voltage.
Rotating machines and protection elements connected to the mains network help dictate the behavior the network exhibits when large portions of the network are disconnected (local within a plant or wide area within a region). When the disconnection occurs, the slow reaction time of many rotating machines forces a gradual reduction in voltage; for a short period, these machines will actually operate as generators, sending power into the network.
Some equipment is more sensitive to gradual variations in voltage than to abrupt change. Most data processing equipment, for instance, have built in power fail detectors in order to protect and save the data properly; these detectors will often not react fast enough to a gradual decrease in mains voltage. The DC voltage to the integrated circuits may decrease to a level below the minimum operating voltage before the detector is activated and results in lost or distorted data, generally making necessary the re-programming of the data processing equipment.
We use the international standard EN 61000-4-11 which outlines the procedure and apparatus used to demonstrate the immunity of equipment to the reductions, interruptions and variations in voltage supplied by an a.c. mains distribution network. The test is performed with the EUT connected to the test generator as described in EN 61000-4-11. EN 61000-4-11 offers the preferred test levels and duration times of conditioning, although whenever possible a specific product standard should be consulted for these values. The EUT is tested for each selected combination of test level and duration with a sequence of 3 dips/interruptions with intervals of at least 10 seconds between each event. Each representative mode of operation is tested. The equipment is considered immune if, during and after the conditioning, it is able to fulfill the functional requirements established by the specific product standard.
For voltage variations we expose the equipment to each of the maximum (e.g. nominal supply voltage + 10%) and minimum (e.g. nominal supply voltage – 15%) power supply conditions for a sufficient time to obtain temperature stability. Where provision is made to adapt the equipment to suit a number of nominal supply voltages such as with a transformer tap change, the maximum and minimum values are tested for each value. For equipment which is claimed to be suitable for a range of nominal mains voltages (e.g. 120/240 V) without user intervention, the minimum condition is applied to the lower end of the range, while the maximum

One Distribution Center Circle, #1 • Littleton, MA • TEL (978) 486-8880 • FAX (978) 486-8828 | page 55 of 75

condition is applied to the larger value in the range. The equipment is considered immune if, during the conditioning, it is able to fulfill the functional requirements established by the specific product standard.
All testing is performed within the framework of a laboratory quality system modeled on ISO/IEC 17025 General requirements for the competence of calibration and testing laboratories and is subject to our terms and conditions. This test method is covered by our A2LA accreditation.

One Distribution Center Circle, #1 • Littleton, MA • TEL (978) 486-8880 • FAX (978) 486-8828 | page 56 of 75

HARMONIC EMISSIONS AND VOLTAGE FLUCTUATIONS/FLICKER

Test Method:

In accordance with EN 61000-3-2:2006 and EN 61000-3-3:2008.

Results:

TEST | RESULT | TEST METHOD | EQUIPMENT TYPE | COMMENTS
Harmonics | PASS | EN 61000-3-2 | Class A
Flicker | PASS | EN 61000-3-3 | N/A

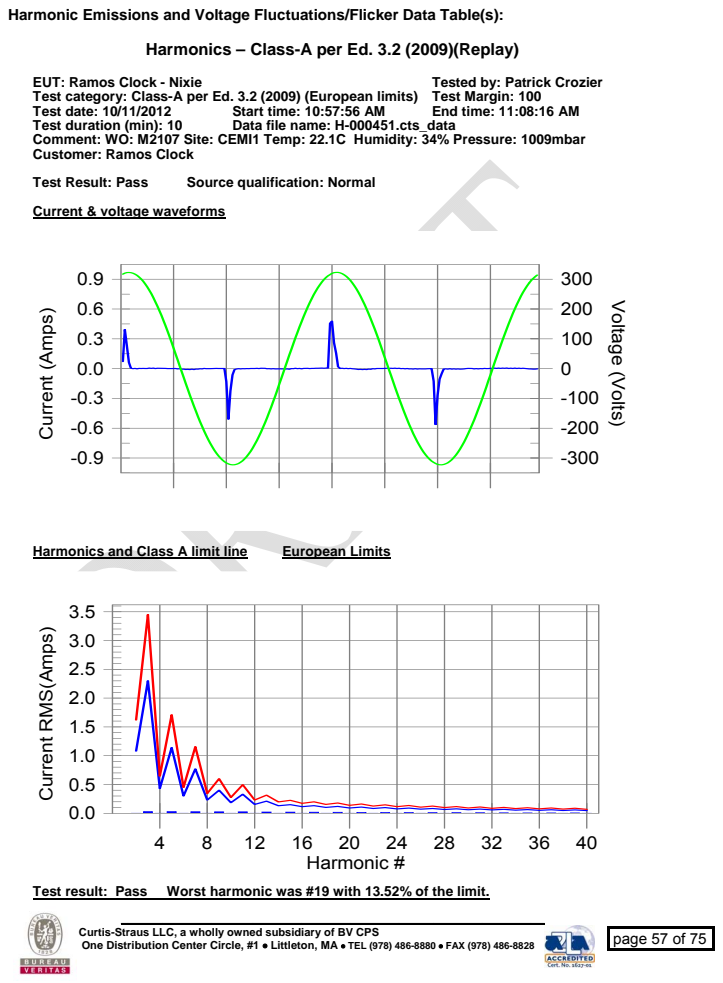
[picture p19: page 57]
One Distribution Center Circle, #1 • Littleton, MA • TEL (978) 486-8880 • FAX (978) 486-8828; page 57 of 75; EUT: Ramos Clock - Nixie; Tested by: Patrick Crozier; Test date: 10/11/2012; Start time: 10:57:56 AM; End time: 11:08:16 AM; Test duration (min): 10; Data file name: H-000451.cts_data; Test Result: Pass; Source qualification: Normal; Current (Amps); Voltage (Volts); Harmonics and Class A limit line; European Limits; Harmonic #; Test result: Pass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

Harmonic Emissions and Voltage Fluctuations/Flicker Data Table(s):

Harmonics – Class-A per Ed. 3.2 (2009)(Replay)

Test category: Class-A per Ed. 3.2 (2009) (European limits) Test Margin: 100
Comment: WO: M2107 Site: CEMI1 Temp: 22.1C Humidity: 34% Pressure: 1009mbar
Customer: Ramos Clock
Current & voltage waveforms

Current RMS(Amps)

One Distribution Center Circle, #1 • Littleton, MA • TEL (978) 486-8880 • FAX (978) 486-8828 | page 58 of 75

Current Test Result Summary (Replay)

EUT: Ramos Clock - Nixie | Tested by: Patrick Crozier
Test category: Class-A per Ed. 3.2 (2009) (European limits) Test Margin: 100
Test date: 10/11/2012 | Start time: 10:57:56 AM | End time: 11:08:16 AM
Test duration (min): 10 | Data file name: H-000451.cts_data
Comment: WO: M2107 Site: CEMI1 Temp: 22.1C Humidity: 34% Pressure: 1009mbar Customer: Ramos Clock
Test Result: Pass | Source qualification: Normal
THC(A): 0.07 | I-THD(%): 269.43 | POHC(A): 0.031 | POHC Limit(A): 0.251
Highest parameter values during test:
V_RMS (Volts): 228.34 | Frequency(Hz): 50.00
I_Peak (Amps): 0.654 | I_RMS (Amps): 0.097
I_Fund (Amps): 0.030 | Crest Factor: | 8.472
Power (Watts): 7.1 | Power Factor: | 0.364
Harm# Harms(avg) 100%Limit %of Limit | Harms(max) 150%Limit %of Limit Status
2 | 0.000 | 1.080 | 0.0 | 0.000 | 1.620 | 0.02 | Pass
3 | 0.026 | 2.300 | 1.1 | 0.029 | 3.450 | 0.84 | Pass
4 | 0.000 | 0.430 | 0.0 | 0.000 | 0.645 | 0.05 | Pass
5 | 0.025 | 1.140 | 2.2 | 0.028 | 1.710 | 1.63 | Pass
6 | 0.000 | 0.300 | 0.0 | 0.000 | 0.450 | 0.10 | Pass
7 | 0.024 | 0.770 | 3.1 | 0.027 | 1.155 | 2.33 | Pass
8 | 0.000 | 0.230 | 0.0 | 0.000 | 0.345 | 0.11 | Pass
9 | 0.023 | 0.400 | 5.8 | 0.026 | 0.600 | 4.29 | Pass
10 | 0.000 | 0.184 | 0.0 | 0.000 | 0.276 | 0.14 | Pass
11 | 0.022 | 0.330 | 6.7 | 0.024 | 0.495 | 4.88 | Pass
12 | 0.000 | 0.153 | 0.0 | 0.001 | 0.230 | 0.24 | Pass
13 | 0.021 | 0.210 | 9.8 | 0.022 | 0.315 | 7.10 | Pass
14 | 0.000 | 0.131 | 0.0 | 0.000 | 0.197 | 0.21 | Pass
15 | 0.019 | 0.150 | 12.7 | 0.021 | 0.225 | 9.14 | Pass
16 | 0.000 | 0.115 | 0.0 | 0.000 | 0.173 | 0.26 | Pass
17 | 0.018 | 0.132 | 13.3 | 0.019 | 0.199 | 9.40 | Pass
18 | 0.000 | 0.102 | 0.0 | 0.001 | 0.153 | 0.35 | Pass
19 | 0.016 | 0.118 | 13.5 | 0.017 | 0.178 | 9.43 | Pass
20 | 0.000 | 0.092 | 0.0 | 0.000 | 0.138 | 0.31 | Pass
21 | 0.014 | 0.107 | 13.5 | 0.015 | 0.161 | 9.27 | Pass
22 | 0.000 | 0.084 | 0.0 | 0.000 | 0.125 | 0.38 | Pass
23 | 0.013 | 0.098 | 13.3 | 0.013 | 0.147 | 9.01 | Pass
24 | 0.000 | 0.077 | 0.0 | 0.000 | 0.115 | 0.42 | Pass
25 | 0.012 | 0.090 | 12.9 | 0.012 | 0.135 | 8.76 | Pass
26 | 0.000 | 0.071 | 0.0 | 0.000 | 0.106 | 0.43 | Pass
27 | 0.010 | 0.083 | 12.4 | 0.011 | 0.125 | 8.48 | Pass
28 | 0.000 | 0.066 | 0.0 | 0.000 | 0.099 | 0.47 | Pass
29 | 0.009 | 0.078 | 11.9 | 0.010 | 0.116 | 8.20 | Pass
30 | 0.000 | 0.061 | 0.0 | 0.000 | 0.092 | 0.52 | Pass
31 | 0.008 | 0.073 | 11.5 | 0.009 | 0.109 | 7.87 | Pass
32 | 0.000 | 0.058 | 0.0 | 0.000 | 0.086 | 0.56 | Pass
33 | 0.008 | 0.068 | 11.0 | 0.008 | 0.102 | 7.60 | Pass
34 | 0.000 | 0.054 | 0.0 | 0.000 | 0.081 | 0.57 | Pass
35 | 0.007 | 0.064 | 10.6 | 0.007 | 0.096 | 7.31 | Pass
36 | 0.000 | 0.051 | 0.0 | 0.000 | 0.077 | 0.60 | Pass
37 | 0.006 | 0.061 | 10.2 | 0.006 | 0.091 | 7.02 | Pass
38 | 0.000 | 0.048 | 0.0 | 0.000 | 0.073 | 0.64 | Pass
39 | 0.006 | 0.058 | 9.8 | 0.006 | 0.087 | 6.79 | Pass
40 | 0.000 | 0.046 | 0.0 | 0.000 | 0.069 | 0.68 | Pass

One Distribution Center Circle, #1 • Littleton, MA • TEL (978) 486-8880 • FAX (978) 486-8828 | page 59 of 75

Voltage Source Verification Data (Replay)

EUT: Ramos Clock - Nixie | Tested by: Patrick Crozier
Test category: Class-A per Ed. 3.2 (2009) (European limits) Test Margin: 100
Test date: 10/11/2012 | Start time: 10:57:56 AM | End time: 11:08:16 AM
Test duration (min): 10 | Data file name: H-000451.cts_data
Comment: WO: M2107 Site: CEMI1 Temp: 22.1C Humidity: 34% Pressure: 1009mbar Customer: Ramos Clock

Test Result: Pass Source qualification: Normal

Highest parameter values during test:
Voltage (Vrms): 228.34 | Frequency(Hz): 50.00
I_Peak (Amps): 0.654 | I_RMS (Amps): 0.097
I_Fund (Amps): 0.030 | Crest Factor: | 8.472
Power (Watts): 7.1 | Power Factor: | 0.364
Harm# | Harmonics V-rms | Limit V-rms | % of Limit | Status
2 | 0.079 | 0.457 | 17.21 | OK
3 | 0.334 | 2.055 | 16.27 | OK
4 | 0.031 | 0.457 | 6.89 | OK
5 | 0.014 | 0.913 | 1.54 | OK
6 | 0.016 | 0.457 | 3.44 | OK
7 | 0.043 | 0.685 | 6.20 | OK
8 | 0.018 | 0.457 | 3.93 | OK
9 | 0.008 | 0.457 | 1.85 | OK
10 | 0.016 | 0.457 | 3.46 | OK
11 | 0.024 | 0.228 | 10.63 | OK
12 | 0.016 | 0.228 | 6.91 | OK
13 | 0.007 | 0.228 | 3.13 | OK
14 | 0.008 | 0.228 | 3.50 | OK
15 | 0.021 | 0.228 | 9.27 | OK
16 | 0.017 | 0.228 | 7.45 | OK
17 | 0.007 | 0.228 | 2.99 | OK
18 | 0.021 | 0.228 | 9.14 | OK
19 | 0.017 | 0.228 | 7.57 | OK
20 | 0.022 | 0.228 | 9.68 | OK
21 | 0.011 | 0.228 | 4.70 | OK
22 | 0.008 | 0.228 | 3.49 | OK
23 | 0.015 | 0.228 | 6.70 | OK
24 | 0.005 | 0.228 | 2.12 | OK
25 | 0.013 | 0.228 | 5.56 | OK
26 | 0.007 | 0.228 | 3.02 | OK
27 | 0.013 | 0.228 | 5.82 | OK
28 | 0.006 | 0.228 | 2.65 | OK
29 | 0.015 | 0.228 | 6.64 | OK
30 | 0.008 | 0.228 | 3.29 | OK
31 | 0.013 | 0.228 | 5.74 | OK
32 | 0.005 | 0.228 | 2.17 | OK
33 | 0.013 | 0.228 | 5.89 | OK
34 | 0.003 | 0.228 | 1.12 | OK
35 | 0.008 | 0.228 | 3.64 | OK
36 | 0.003 | 0.228 | 1.48 | OK
37 | 0.013 | 0.228 | 5.54 | OK
38 | 0.003 | 0.228 | 1.41 | OK
39 | 0.010 | 0.228 | 4.42 | OK
40 | 0.014 | 0.228 | 5.93 | OK

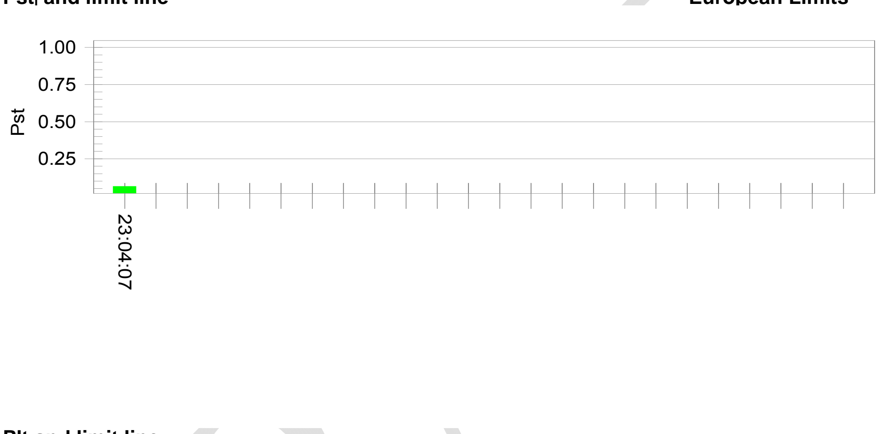
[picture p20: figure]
Pst
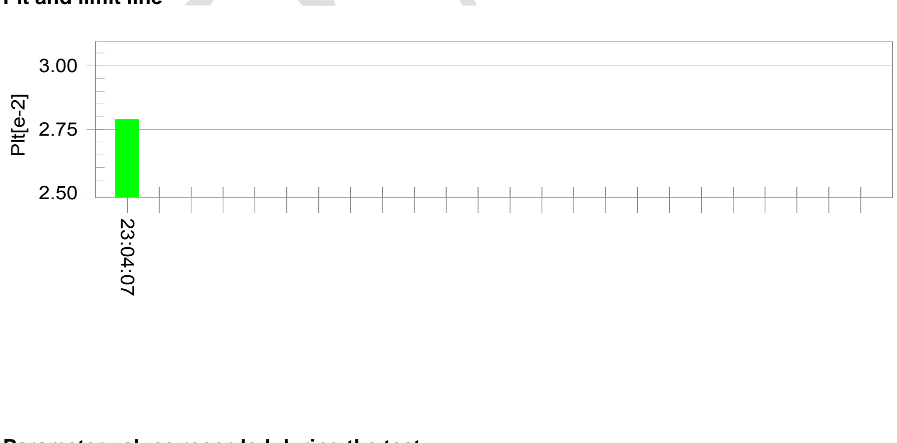
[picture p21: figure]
Plt[e-2]

One Distribution Center Circle, #1 • Littleton, MA • TEL (978) 486-8880 • FAX (978) 486-8828 | page 60 of 75

Flicker Test Summary per EN/IEC61000-3-3 (Replay)

EUT: Ramos Clock (Nixie) | | Tested by: Tuyen Truong
Test category: dt,dmax,dc and Pst (European limits) | Test Margin: 100
Test date: 10/10/2012 | Start time: 10:54:08 PM | End time: 11:04:07 PM
Test duration (min): 10 | Data file name: F-000443.cts_data
Comment: WO:M2107 Site: CEMI1 Temp:23.C Humidity: 36% Pressure: 1015mbar Customer: Sammut Tech, LLC
Test Result: Pass | Status: Test Completed
Psti and limit line | | European Limits

Plt and limit line

Parameter values recorded during the test:
Vrms at the end of test (Volt): | 228.35
Highest dt (%): | 0.00 | Test limit (%): | 3.30 | Pass
Time(mS) > dt: | 0.0 | Test limit (mS): | 500.0 | Pass
Highest dc (%): | 0.00 | Test limit (%): | 3.30 | Pass
Highest dmax (%): | 0.00 | Test limit (%): | 4.00 | Pass
Highest Pst (10 min. period): | 0.064 | Test limit: | 1.000 | Pass

One Distribution Center Circle, #1 • Littleton, MA • TEL (978) 486-8880 • FAX (978) 486-8828 | page 61 of 75

Rev. 10/10/2012
Harmonic & Flicker and Power Analyzer | MN | Mfr | SN | Asset | Cat | Calibration Due
5001IX AC POWER SYSTEM | 5001IX | CI | HK53687 | 376 | II | 10/31/2012
PACS-1 | 10-CTS-PCI | CI | 72297 | 1060 | II | 10/31/2012
_
Meteorological Meters | MN | Mfr | SN | Asset | Cat | Calibration Due
Weather Clock (Pressure Only) | BA928 | Oregon Scientific | C3166-1 | 831 | I | 3/28/2013
CEMI1 Thermohygrometer | 35519-044 | Control Company 72457738 | 1335 | II | 8/19/2013
_
All equipment is calibrated using standards traceable to NIST or other nationally recognized calibration standard.

Harmonics and Flicker Modifications:
None

Additional Modifications in place during testing:
See modification required for AC Line Conducted Emissions.

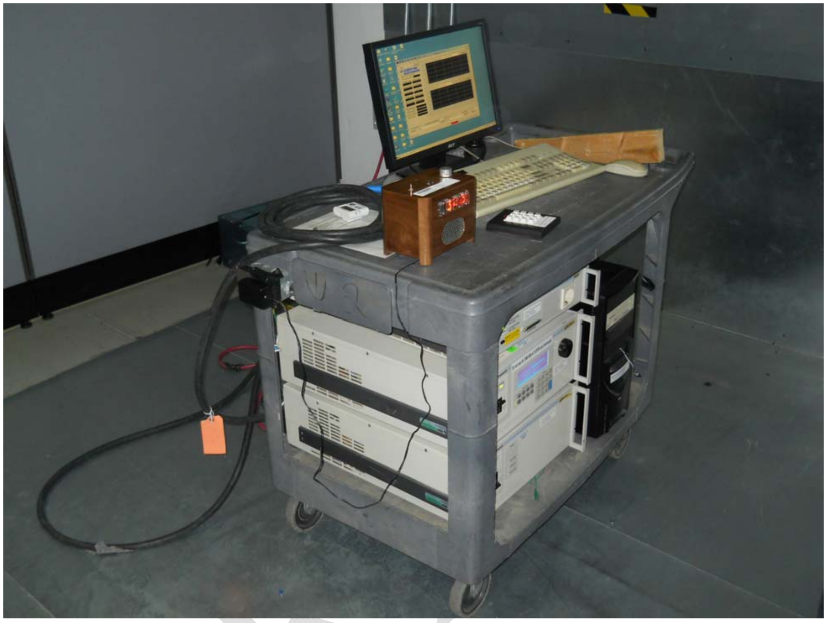
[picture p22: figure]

One Distribution Center Circle, #1 • Littleton, MA • TEL (978) 486-8880 • FAX (978) 486-8828 | page 62 of 75

Harmonic Emissions and Voltage Fluctuations/Flicker Setup Photograph(s):

One Distribution Center Circle, #1 • Littleton, MA • TEL (978) 486-8880 • FAX (978) 486-8828 | page 63 of 75

Meeting Harmonic Emissions Requirements:

REV 17-FEB-04
Power line harmonics are generated when a load draws a non-linear current from a sinusoidal voltage. Consider an ideal single phase line. If that line is a perfect sinusoidal voltage source, with zero source impedance, it would not matter how non-linear the attached equipment is. In the real world, however, wiring raises the power line impedance to a non-zero level. If a device demands an unusually high proportion of higher frequency harmonics, it will impose high frequency supply fluctuations on adjacent equipment. Some components, such as motor start/run capacitors, will dissipate excessive energy and be damaged. A second effect can be seen in three phase lines. Here, third harmonic energy winds up in phase, causing current to flow on the neutral lead. This situation has undesired safety consequences.
Switching power supplies are a common source of harmonics due to the discontinuous current drain which they present to the supply line. The increasing use of microprocessors and sensitive digital circuitry in many electronic products has given rise to increased concern over utility power quality. Low level digital circuitry is more sensitive to line variations than heavier industrial loads such as motors and standard lighting. Unfortunately, such devices also generally present non-linear loads to the power lines, which result in distortion on the supply in the form of harmonic generation and transients.
We measure the first 40 harmonic emissions of 50/60Hz in accordance with EN61000-3-2 using an HP test set.
All testing is performed within the framework of a laboratory quality system modeled on ISO/IEC 17025 General requirements for the competence of calibration and testing laboratories and is subject to our terms and conditions. This test is covered by our A2LA accreditation.

Meeting Voltage Fluctuation Requirements

REV 16-FEB-04
Household appliances and similar equipment, having electronic or electromechanical control devices, may produce voltage fluctuations in the supply systems they are attached to as the power demands of such equipment changes with time. In some installations the combination of these time varying current requirements and high supply system impedance can cause excessive changes in the power mains line voltage. If excessive voltage changes are repeated at short intervals of time, objectionable fluctuations of luminance (flicker) will be produced in lumination sources, e.g. an incandescent light bulb, connected to the same supply network. EN 61000-3-3 specifies the measurements which must be made to ensure that these voltage fluctuations are kept to an acceptable level. The equipment under test is powered from a low impedance AC power main through a controlled impedance. Observations are made of the subjective flicker of a flicker meter to determine if the equipment is producing objectionable luminary flicker. The flicker meter implements a complex mathematical model of the human response to light flicker taking into account factors such as frequency, amplitude and duration of flicker events. All operating automatic modes of the equipment are evaluated. Changes caused by manual switching are not measured.

One Distribution Center Circle, #1 • Littleton, MA • TEL (978) 486-8880 • FAX (978) 486-8828 | page 64 of 75

Examples of electrical equipment to which this requirement applies are appliances for cooking and heating, motor operated or magnetically driven appliances, and portable tools. Equipment which is connected to higher than 240 VAC single phase power mains or 415 VAC three phase power mains is excluded from testing as are devices which produce less than one voltage change per hour or more than 1800 per minute. Other types and applications of equipment are currently under consideration for inclusion in future drafts of the standard.
All testing is performed within the framework of a laboratory quality system modeled on ISO/IEC 17025 General requirements for the competence of calibration and testing laboratories and is subject to our terms and conditions. This test method is covered by our A2LA accreditation.

One Distribution Center Circle, #1 • Littleton, MA • TEL (978) 486-8880 • FAX (978) 486-8828 | page 65 of 75

Measurement Uncertainty

The listed uncertainties are the worst case uncertainty for the entire range of measurement. Please note that the uncertainty values are provided for informational purposes only and are not used in determining the PASS/FAIL results.

Measurement | Expanded Uncertainty k=2 | Maximum allowable uncertainty
Radiated Emissions (30-1000MHz)
NIST CISPR | 5.6dB 4.6dB | N/A 5.2dB (Ucispr)
Radiated Emissions (1-26.5GHz) | 4.6dB | N/A
Radiated Emissions (above 26.5GHz) | 4.9dB | N/A
Magnetic Radiated Emissions | 5.6dB | N/A
Conducted Emissions
NIST CISPR | 3.9dB 3.6dB | N/A 3.6dB (Ucispr)
Telco Conducted Emissions (Current) | 2.9dB | N/A
Telco Conducted Emissions (Voltage) | 4.4dB | N/A
Electrostatic Discharge | 11.5% | N/A
Radiated RF Immunity (Uniform Field) | 1.6dB | N/A
Electrical Fast Transients | 23.1% | N/A
Surge | 23.1% | N/A
Conducted RF Immunity | 3dB | N/A
Magnetic Immunity | 12.8% | N/A
Dips and Interrupts | 2.3V | N/A
Harmonics | 3.5% | N/A
Flicker | 3.5% | N/A
Radio frequency (@ 2.4GHz) | 3.23 x 10⁻⁸ | 1 x 10⁻⁷
RF power, conducted | 0.40dB | 0.75dB
Maximum frequency deviation:
- Within 300Hz and 6kHz of audio frequency / Within 6kHz and 25kHz of audio frequency | 3.4% 0.3dB | 5% 3dB
Adjacent channel power | 1.9dB | 3dB
Conducted spurious emission of transmitter, valid up to 12.75GHz | 2.39dB | 3dB
Conducted emission of receivers | 1.3dB | 3dB
Radiated emission of transmitter, valid up to 26.5GHz | 3.9dB | 6dB
Radiated emission of transmitter, valid up to 80GHz | 3.3dB | 6dB
Radiated emission of receiver, valid up to 26.5GHz | 3.9dB | 6dB
Radiated emission of receiver, valid up to 80GHz | 3.3dB | 6dB
Humidity | 2.37% | 5%
Temperature | 0.7°C | 1.0°C
Time | 4.1% | 10%
RF Power Density, Conducted | 0.4dB | 3dB
DC and low frequency voltages | 1.3% | 3%
Voltage (AC, <10kHz) | 1.3% | 2%
Voltage (DC) | 0.62% | 1%

The above reflects a 95% confidence level

One Distribution Center Circle, #1 • Littleton, MA • TEL (978) 486-8880 • FAX (978) 486-8828 | page 66 of 75

Jurisdictional Labeling and Required Instruction Manual Inserts

CE Marking - European Union (EU)
The CE mark is affixed by a manufacturer to its product in order to demonstrate to customs and other officials that the product marked is in conformity with all applicable European Union (EU) Directives. The CE mark must take the form shown below and must be affixed to the product unless the product is too small. If the product is too small, the CE mark may be affixed to the packaging, instructions for use or the guarantee certificate. The CE mark must be a minimum 5mm in height.
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

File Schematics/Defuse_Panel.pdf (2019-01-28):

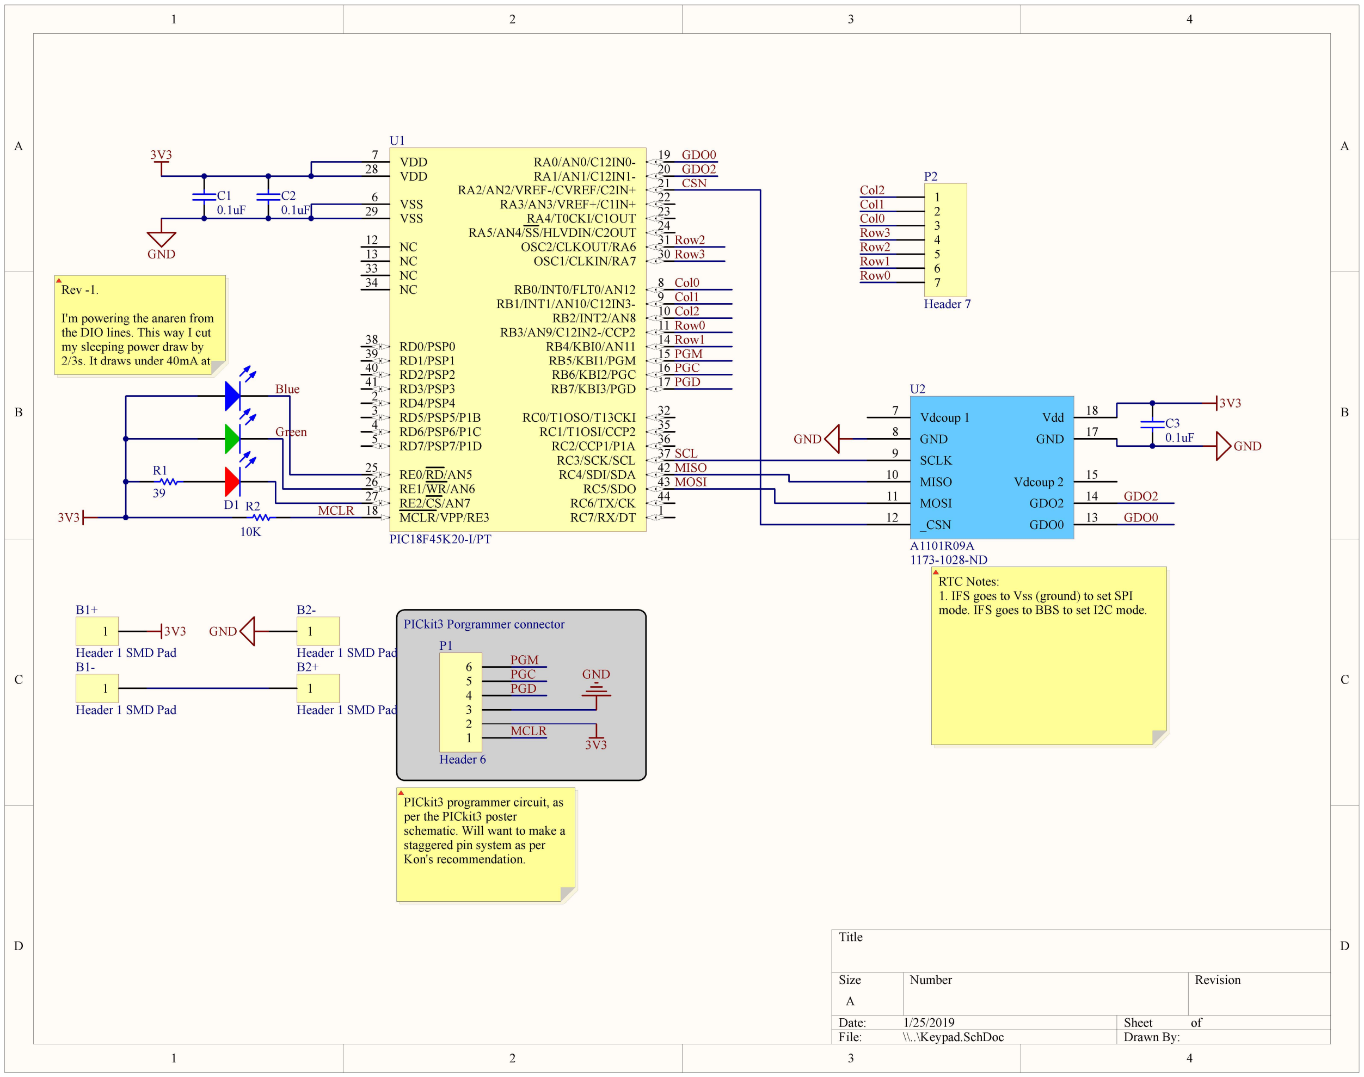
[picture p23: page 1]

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
Title

Size | Number | | Revision
A
Date: | 1/25/2019 | Sheet | of
File: | \\..\Keypad.SchDoc | Drawn By:
RC7/RX/DT | 1

RD4/PSP4 2
RD5/PSP5/P1B 3
RD6/PSP6/P1C 4
RD7/PSP7/P1D 5

VSS 6

VDD 7

RB0/INT0/FLT0/AN12 | 8
RB1/INT1/AN10/C12IN3- | 9
RB2/INT2/AN8 | 10
RB3/AN9/C12IN2-/CCP2 | 11

NC 12
NC 13
RB4/KBI0/AN11 | 14
RB5/KBI1/PGM | 15
RB6/KBI2/PGC | 16
RB7/KBI3/PGD | 17

MCLR/VPP/RE3 18

RA0/AN0/C12IN0- | 19
RA1/AN1/C12IN1- | 20
RA2/AN2/VREF-/CVREF/C2IN+ | 21
RA3/AN3/VREF+/C1IN+ | 22
RA4/T0CKI/C1OUT | 23
RA5/AN4/SS/HLVDIN/C2OUT | 24

RE0/RD/AN5 25
RE1/WR/AN6 26
RE2/CS/AN7 27

VDD 28

VSS 29

OSC1/CLKIN/RA7 | 30 OSC2/CLKOUT/RA6 | 31
RC0/T1OSO/T13CKI | 32

NC 33
NC 34
RC1/T1OSI/CCP2 | 35
RC2/CCP1/P1A | 36
RC3/SCK/SCL | 37

RD0/PSP0 38
RD1/PSP1 39
RD2/PSP2 40
RD3/PSP3 41
RC4/SDI/SDA | 42
RC5/SDO | 43
RC6/TX/CK | 44

U1

PIC18F45K20-I/PT

GND

3V3

3V3

GND

PICkit3 Porgrammer connector

MCLR

MOSI

SCL
MISO

3V3

PGM
PGC
PGD

MCLR

PGD

PGC

PGM

GND | GND

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
Header 7

1

2

3

4

5

6

P1

Header 6

GDO0
GDO2

Col0
Col1
Col2
Row0
Row1

Col0

Col1

Col2

Row0

Row1

Row3
Row2 Row3

Row2

1

B1+

Header 1 SMD Pad

1

B2+

Header 1 SMD Pad

1

B1-

Header 1 SMD Pad

1

B2-

Header 1 SMD Pad

3V3 GND

D1

CSN

1173-1028-ND

Vdcoup 1 7
GND 8
SCLK 9
MISO 10
MOSI 11
_CSN 12 | GDO0 | 13
| GDO2 | 14
Vdcoup 2 | 15
GND | 17
Vdd | 18

U2

A1101R09A

GDO0

GDO2

0.1uF

C1
0.1uF

C2

0.1uF

C3

10K

R2

39

R1

3V3
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

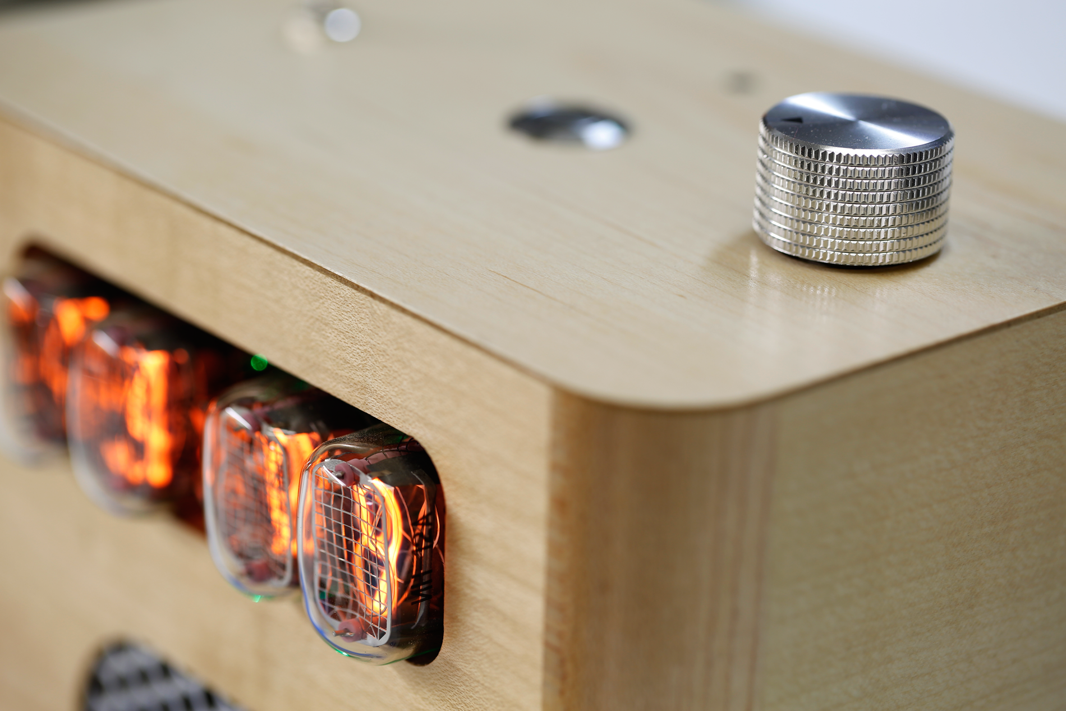
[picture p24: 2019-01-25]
images/Maple_D.png

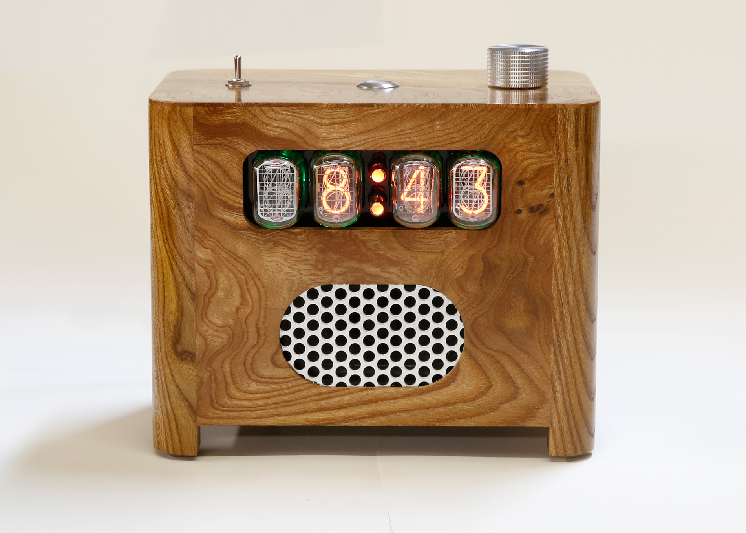
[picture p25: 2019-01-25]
images/ELM_A.png

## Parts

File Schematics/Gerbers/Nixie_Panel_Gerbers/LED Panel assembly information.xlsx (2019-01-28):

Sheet: LED Panel Info
Sammut Tech LLC
706 Washington Str. | LED SMT Manufacturing Datasheet
Hoboken, NJ, 07030 |  |  | 2012-12-03
This is information for the SMT components of the LED panel. The other sheets contain centroid data (units in mils) and the bom. Shipped 31 Panels.
General Information
Panel name: | LED Panel
Panel Width: | 13.228 | in
Panel Height: | 8.110 | in
Board offset X: | 4409.5 | mil
Board offset Y: | 2480.3 | mil
Boards per panel: | 9
Fiducial Locations (mils) | X | Y
Lower left | 590.6 | 196.8
Lower right | 12637.8 | 196.8
Top Left | 590.6 | 7913.4
Top Right | 12637.8 | 7913.4
Notes:
1. The polarity mark on the diode is hard to see. Make sure the polarity mark corresponds to the
silk screen markings on the board.
2. Missing the R11 resistor. Will ship to AMS
3. Many of the components will be later used for the Keypad and Nixie.

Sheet: Pick Place for LED_Panel
 | Designator | Footprint | Mid X | Mid Y | Ref X | Ref Y | Pad X | Pad Y | Layer | Comment
1 | L1 | INDP104103X40N | 304.921 | 1417.323 | 314.764 | 1417.323 | 304.921 | 1240.158 | T | PF0560.683NLT
1 | U4 | SOIC127P600-8AN | 834.448 | 1421.26 | 834.449 | 1421.26 | 909.448 | 1519.685 | T | MIC4680-3.3YM
1 | D1 | B260A | 590.354 | 1417.316 | 590.354 | 1417.323 | 590.354 | 1496.057 | T | B260A-13-F
1 | C4 | TC7343-2917 | 892.229 | 1695.922 | 892.228 | 1695.921 | 1018.213 | 1695.922 | T | TPSD156M035R0300
1 | C1 | 1206 | 4063.78 | 1559.055 | 4063.78 | 1559.055 | 4063.78 | 1503.937 | T | C1206C104K5RACTU
1 | C2 | 1206 | 3375.787 | 1534.449 | 3375.787 | 1534.449 | 3375.787 | 1479.331 | T | C1206C104K5RACTU
1 | C3 | 1206 | 3998.227 | 2229.921 | 3998.228 | 2229.921 | 3998.227 | 2285.039 | T | C1206C104K5RACTU
1 | C6 | 1206 | 3792 | 1022.937 | 3792 | 1022.937 | 3792 | 967.819 | T | C1206C104K5RACTU
1 | Q2 | SOT-23B_N | 2224.212 | 2275.59 | 2224.213 | 2275.591 | 2186.81 | 2231.299 | T | PBRP123YT,215
1 | Q7 | SOT-23B_N | 2440.748 | 2275.59 | 2440.748 | 2275.591 | 2403.346 | 2231.299 | T | PBRP123YT,215
1 | R1 | 6-0805 | 3693.629 | 1220.921 | 3693.629 | 1220.922 | 3656.228 | 1220.921 | T | ERJ-6GEYJ103V
1 | U1 | TQFP-PT44_N | 3700.59 | 1547.244 | 3700.59 | 1547.244 | 3478.15 | 1704.725 | T | PIC18F45K20-I/PT
1 | U2 | SOIC127P1030-20BN | 3680.905 | 2204.724 | 3680.905 | 2204.724 | 3486.023 | 2429.724 | T | PCF2129AT
1 | C10 | 1210 | 320 | 2179.819 | 320 | 2179.819 | 320 | 2124.701 | T | C1210C105K5RACTU
1 | C11 | 1206 | 1314.001 | 2210.819 | 1314 | 2210.819 | 1314.001 | 2265.937 | T | C1206C104K5RACTU
1 | C12 | 1206 | 342.323 | 2460.631 | 342.323 | 2460.63 | 342.323 | 2405.513 | T | C1206C476M8PACTU
1 | C13 | 1206 | 1413.999 | 2208.818 | 1414 | 2208.819 | 1413.999 | 2263.936 | T | C1206C104K5RACTU
1 | C14 | 1206 | 1520.999 | 2210.818 | 1521 | 2210.819 | 1520.999 | 2265.936 | T | C1206C104K5RACTU
1 | C15 | 1206 | 330 | 1971.819 | 330 | 1971.819 | 330 | 1916.701 | T | C1206C104K5RACTU
1 | C16 | PANASONIC_SIZE_G | 853.228 | 2042.921 | 853.228 | 2042.921 | 853.228 | 1883.473 | T | EEE-FK1H221P
1 | Q3 | SOT-23B_N | 2007.874 | 2273.74 | 2007.874 | 2273.74 | 1970.473 | 2229.449 | T | PBRP123YT,215
1 | Q4 | SOT-23B_N | 2224.213 | 2027.559 | 2224.213 | 2027.559 | 2261.614 | 2071.851 | T | PBRP123YT,215
1 | Q5 | SOT-23B_N | 2007.677 | 2027.559 | 2007.677 | 2027.559 | 2045.079 | 2071.85 | T | PBRP123YT,215
1 | Q6 | SOT-23B_N | 2440.748 | 2027.559 | 2440.748 | 2027.559 | 2478.15 | 2071.851 | T | PBRP123YT,215
1 | R11 | 8-1206 | 767.519 | 2391.732 | 767.52 | 2391.732 | 767.519 | 2336.614 | T | 150k
1 | R12 | 8-1206 | 659.253 | 2391.732 | 659.252 | 2391.732 | 659.253 | 2446.85 | T | 5.1k
1 | R13 | 6-0805 | 1616 | 2221.418 | 1616 | 2221.418 | 1616 | 2184.017 | T | 1.2k
1 | U3 | A1101 | 4096.968 | 881.102 | 4258.386 | 711.811 | 4258.386 | 711.811 | T | A1101R09A
1 | R2 | 6-0805 | 3247.835 | 1604.331 | 3247.835 | 1604.331 | 3247.835 | 1566.929 | T | ERJ-6GEYJ103V
1 | U5 | BOURNS_4816P_RESISTOR | 2788.228 | 2209.921 | 2788.228 | 2209.921 | 2926.024 | 2034.921 | T | 4816P-T01-330LF
1 | U8 | SOIC127P600X175-16N | 3143.228 | 2209.921 | 3143.228 | 2209.921 | 3237.716 | 2034.921 | T | ULN2003A
1 | C5 | TC7343-2917 | 521.457 | 996.063 | 521.457 | 996.063 | 521.457 | 870.078 | T | TPSD227M010R0100
1 | C7 | 1206 | 1322.902 | 1728.628 | 1322.902 | 1728.628 | 1267.784 | 1728.628 | T | C1206C104K5RACTU
2 | L1 | INDP104103X40N | 304.921 | 3897.638 | 314.764 | 3897.638 | 304.921 | 3720.472 | T | PF0560.683NLT
2 | U4 | SOIC127P600-8AN | 834.448 | 3901.575 | 834.449 | 3901.575 | 909.448 | 4000 | T | MIC4680-3.3YM
2 | D1 | B260A | 590.354 | 3897.631 | 590.354 | 3897.638 | 590.354 | 3976.372 | T | B260A-13-F
2 | C4 | TC7343-2917 | 892.229 | 4176.237 | 892.228 | 4176.236 | 1018.213 | 4176.237 | T | TPSD156M035R0300
2 | C1 | 1206 | 4063.78 | 4039.37 | 4063.78 | 4039.37 | 4063.78 | 3984.252 | T | C1206C104K5RACTU
2 | C2 | 1206 | 3375.787 | 4014.764 | 3375.787 | 4014.764 | 3375.787 | 3959.646 | T | C1206C104K5RACTU
2 | C3 | 1206 | 3998.227 | 4710.236 | 3998.228 | 4710.236 | 3998.227 | 4765.354 | T | C1206C104K5RACTU
2 | C6 | 1206 | 3792 | 3503.252 | 3792 | 3503.252 | 3792 | 3448.134 | T | C1206C104K5RACTU
2 | Q2 | SOT-23B_N | 2224.212 | 4755.905 | 2224.213 | 4755.906 | 2186.81 | 4711.614 | T | PBRP123YT,215
2 | Q7 | SOT-23B_N | 2440.748 | 4755.905 | 2440.748 | 4755.906 | 2403.346 | 4711.614 | T | PBRP123YT,215
2 | R1 | 6-0805 | 3693.629 | 3701.236 | 3693.629 | 3701.237 | 3656.228 | 3701.236 | T | ERJ-6GEYJ103V
2 | U1 | TQFP-PT44_N | 3700.59 | 4027.559 | 3700.59 | 4027.559 | 3478.15 | 4185.039 | T | PIC18F45K20-I/PT
2 | U2 | SOIC127P1030-20BN | 3680.905 | 4685.039 | 3680.905 | 4685.039 | 3486.023 | 4910.039 | T | PCF2129AT
2 | C10 | 1210 | 320 | 4660.134 | 320 | 4660.134 | 320 | 4605.016 | T | C1210C105K5RACTU
2 | C11 | 1206 | 1314.001 | 4691.134 | 1314 | 4691.134 | 1314.001 | 4746.252 | T | C1206C104K5RACTU
2 | C12 | 1206 | 342.323 | 4940.946 | 342.323 | 4940.945 | 342.323 | 4885.828 | T | C1206C476M8PACTU
2 | C13 | 1206 | 1413.999 | 4689.133 | 1414 | 4689.134 | 1413.999 | 4744.252 | T | C1206C104K5RACTU
2 | C14 | 1206 | 1520.999 | 4691.133 | 1521 | 4691.134 | 1520.999 | 4746.252 | T | C1206C104K5RACTU
2 | C15 | 1206 | 330 | 4452.134 | 330 | 4452.134 | 330 | 4397.016 | T | C1206C104K5RACTU
2 | C16 | PANASONIC_SIZE_G | 853.228 | 4523.236 | 853.228 | 4523.236 | 853.228 | 4363.788 | T | EEE-FK1H221P
2 | Q3 | SOT-23B_N | 2007.874 | 4754.055 | 2007.874 | 4754.055 | 1970.473 | 4709.764 | T | PBRP123YT,215
2 | Q4 | SOT-23B_N | 2224.213 | 4507.874 | 2224.213 | 4507.874 | 2261.614 | 4552.166 | T | PBRP123YT,215
2 | Q5 | SOT-23B_N | 2007.677 | 4507.874 | 2007.677 | 4507.874 | 2045.079 | 4552.165 | T | PBRP123YT,215
2 | Q6 | SOT-23B_N | 2440.748 | 4507.874 | 2440.748 | 4507.874 | 2478.15 | 4552.166 | T | PBRP123YT,215
2 | R11 | 8-1206 | 767.519 | 4872.047 | 767.52 | 4872.047 | 767.519 | 4816.929 | T | 150k
2 | R12 | 8-1206 | 659.253 | 4872.047 | 659.252 | 4872.047 | 659.253 | 4927.165 | T | 5.1k
2 | R13 | 6-0805 | 1616 | 4701.733 | 1616 | 4701.733 | 1616 | 4664.332 | T | 1.2k
2 | U3 | A1101 | 4096.968 | 3361.417 | 4258.386 | 3192.126 | 4258.386 | 3192.126 | T | A1101R09A
2 | R2 | 6-0805 | 3247.835 | 4084.646 | 3247.835 | 4084.646 | 3247.835 | 4047.244 | T | ERJ-6GEYJ103V
2 | U5 | BOURNS_4816P_RESISTOR | 2788.228 | 4690.236 | 2788.228 | 4690.236 | 2926.024 | 4515.236 | T | 4816P-T01-330LF
2 | U8 | SOIC127P600X175-16N | 3143.228 | 4690.236 | 3143.228 | 4690.236 | 3237.716 | 4515.236 | T | ULN2003A
2 | C5 | TC7343-2917 | 521.457 | 3476.378 | 521.457 | 3476.378 | 521.457 | 3350.393 | T | TPSD227M010R0100
2 | C7 | 1206 | 1322.902 | 4208.943 | 1322.902 | 4208.943 | 1267.784 | 4208.943 | T | C1206C104K5RACTU
3 | L1 | INDP104103X40N | 304.921 | 6377.953 | 314.764 | 6377.953 | 304.921 | 6200.788 | T | PF0560.683NLT
3 | U4 | SOIC127P600-8AN | 834.448 | 6381.89 | 834.449 | 6381.89 | 909.448 | 6480.315 | T | MIC4680-3.3YM
3 | D1 | B260A | 590.354 | 6377.946 | 590.354 | 6377.953 | 590.354 | 6456.687 | T | B260A-13-F
3 | C4 | TC7343-2917 | 892.229 | 6656.552 | 892.228 | 6656.551 | 1018.213 | 6656.552 | T | TPSD156M035R0300
3 | C1 | 1206 | 4063.78 | 6519.685 | 4063.78 | 6519.685 | 4063.78 | 6464.567 | T | C1206C104K5RACTU
3 | C2 | 1206 | 3375.787 | 6495.079 | 3375.787 | 6495.079 | 3375.787 | 6439.961 | T | C1206C104K5RACTU
3 | C3 | 1206 | 3998.227 | 7190.551 | 3998.228 | 7190.551 | 3998.227 | 7245.669 | T | C1206C104K5RACTU
3 | C6 | 1206 | 3792 | 5983.567 | 3792 | 5983.567 | 3792 | 5928.449 | T | C1206C104K5RACTU
3 | Q2 | SOT-23B_N | 2224.212 | 7236.22 | 2224.213 | 7236.221 | 2186.81 | 7191.929 | T | PBRP123YT,215
3 | Q7 | SOT-23B_N | 2440.748 | 7236.22 | 2440.748 | 7236.221 | 2403.346 | 7191.929 | T | PBRP123YT,215
3 | R1 | 6-0805 | 3693.629 | 6181.551 | 3693.629 | 6181.552 | 3656.228 | 6181.551 | T | ERJ-6GEYJ103V
3 | U1 | TQFP-PT44_N | 3700.59 | 6507.874 | 3700.59 | 6507.874 | 3478.15 | 6665.355 | T | PIC18F45K20-I/PT
3 | U2 | SOIC127P1030-20BN | 3680.905 | 7165.354 | 3680.905 | 7165.354 | 3486.023 | 7390.354 | T | PCF2129AT
3 | C10 | 1210 | 320 | 7140.449 | 320 | 7140.449 | 320 | 7085.331 | T | C1210C105K5RACTU
3 | C11 | 1206 | 1314.001 | 7171.449 | 1314 | 7171.449 | 1314.001 | 7226.567 | T | C1206C104K5RACTU
3 | C12 | 1206 | 342.323 | 7421.261 | 342.323 | 7421.26 | 342.323 | 7366.143 | T | C1206C476M8PACTU
3 | C13 | 1206 | 1413.999 | 7169.449 | 1414 | 7169.449 | 1413.999 | 7224.566 | T | C1206C104K5RACTU
3 | C14 | 1206 | 1520.999 | 7171.449 | 1521 | 7171.449 | 1520.999 | 7226.566 | T | C1206C104K5RACTU
3 | C15 | 1206 | 330 | 6932.449 | 330 | 6932.449 | 330 | 6877.331 | T | C1206C104K5RACTU
3 | C16 | PANASONIC_SIZE_G | 853.228 | 7003.551 | 853.228 | 7003.551 | 853.228 | 6844.102 | T | EEE-FK1H221P
3 | Q3 | SOT-23B_N | 2007.874 | 7234.37 | 2007.874 | 7234.37 | 1970.473 | 7190.079 | T | PBRP123YT,215
3 | Q4 | SOT-23B_N | 2224.213 | 6988.189 | 2224.213 | 6988.189 | 2261.614 | 7032.481 | T | PBRP123YT,215
3 | Q5 | SOT-23B_N | 2007.677 | 6988.189 | 2007.677 | 6988.189 | 2045.079 | 7032.48 | T | PBRP123YT,215
3 | Q6 | SOT-23B_N | 2440.748 | 6988.189 | 2440.748 | 6988.189 | 2478.15 | 7032.481 | T | PBRP123YT,215
3 | R11 | 8-1206 | 767.519 | 7352.362 | 767.52 | 7352.362 | 767.519 | 7297.244 | T | 150k
3 | R12 | 8-1206 | 659.253 | 7352.362 | 659.252 | 7352.362 | 659.253 | 7407.48 | T | 5.1k
3 | R13 | 6-0805 | 1616 | 7182.048 | 1616 | 7182.047 | 1616 | 7144.647 | T | 1.2k
3 | U3 | A1101 | 4096.968 | 5841.732 | 4258.386 | 5672.441 | 4258.386 | 5672.441 | T | A1101R09A
3 | R2 | 6-0805 | 3247.835 | 6564.961 | 3247.835 | 6564.961 | 3247.835 | 6527.559 | T | ERJ-6GEYJ103V
3 | U5 | BOURNS_4816P_RESISTOR | 2788.228 | 7170.551 | 2788.228 | 7170.551 | 2926.024 | 6995.551 | T | 4816P-T01-330LF
3 | U8 | SOIC127P600X175-16N | 3143.228 | 7170.551 | 3143.228 | 7170.551 | 3237.716 | 6995.551 | T | ULN2003A
3 | C5 | TC7343-2917 | 521.457 | 5956.693 | 521.457 | 5956.693 | 521.457 | 5830.708 | T | TPSD227M010R0100
3 | C7 | 1206 | 1322.902 | 6689.258 | 1322.902 | 6689.258 | 1267.784 | 6689.258 | T | C1206C104K5RACTU
4 | L1 | INDP104103X40N | 4714.37 | 1417.323 | 4724.213 | 1417.323 | 4714.37 | 1240.158 | T | PF0560.683NLT
4 | U4 | SOIC127P600-8AN | 5243.897 | 1421.26 | 5243.898 | 1421.26 | 5318.897 | 1519.685 | T | MIC4680-3.3YM
4 | D1 | B260A | 4999.803 | 1417.316 | 4999.803 | 1417.323 | 4999.803 | 1496.057 | T | B260A-13-F
4 | C4 | TC7343-2917 | 5301.678 | 1695.922 | 5301.677 | 1695.921 | 5427.662 | 1695.922 | T | TPSD156M035R0300
4 | C1 | 1206 | 8473.229 | 1559.055 | 8473.228 | 1559.055 | 8473.229 | 1503.937 | T | C1206C104K5RACTU
4 | C2 | 1206 | 7785.236 | 1534.449 | 7785.236 | 1534.449 | 7785.236 | 1479.331 | T | C1206C104K5RACTU
4 | C3 | 1206 | 8407.676 | 2229.921 | 8407.677 | 2229.921 | 8407.676 | 2285.039 | T | C1206C104K5RACTU
4 | C6 | 1206 | 8201.449 | 1022.937 | 8201.449 | 1022.937 | 8201.449 | 967.819 | T | C1206C104K5RACTU
4 | Q2 | SOT-23B_N | 6633.661 | 2275.59 | 6633.662 | 2275.591 | 6596.259 | 2231.299 | T | PBRP123YT,215
4 | Q7 | SOT-23B_N | 6850.197 | 2275.59 | 6850.197 | 2275.591 | 6812.795 | 2231.299 | T | PBRP123YT,215
4 | R1 | 6-0805 | 8103.078 | 1220.921 | 8103.078 | 1220.922 | 8065.677 | 1220.921 | T | ERJ-6GEYJ103V
4 | U1 | TQFP-PT44_N | 8110.039 | 1547.244 | 8110.039 | 1547.244 | 7887.599 | 1704.725 | T | PIC18F45K20-I/PT
4 | U2 | SOIC127P1030-20BN | 8090.354 | 2204.724 | 8090.355 | 2204.724 | 7895.472 | 2429.724 | T | PCF2129AT
4 | C10 | 1210 | 4729.449 | 2179.819 | 4729.449 | 2179.819 | 4729.449 | 2124.701 | T | C1210C105K5RACTU
4 | C11 | 1206 | 5723.45 | 2210.819 | 5723.449 | 2210.819 | 5723.45 | 2265.937 | T | C1206C104K5RACTU
4 | C12 | 1206 | 4751.772 | 2460.631 | 4751.772 | 2460.63 | 4751.772 | 2405.513 | T | C1206C476M8PACTU
4 | C13 | 1206 | 5823.448 | 2208.818 | 5823.449 | 2208.819 | 5823.448 | 2263.936 | T | C1206C104K5RACTU
4 | C14 | 1206 | 5930.448 | 2210.818 | 5930.449 | 2210.819 | 5930.448 | 2265.936 | T | C1206C104K5RACTU
4 | C15 | 1206 | 4739.449 | 1971.819 | 4739.449 | 1971.819 | 4739.449 | 1916.701 | T | C1206C104K5RACTU
4 | C16 | PANASONIC_SIZE_G | 5262.677 | 2042.921 | 5262.677 | 2042.921 | 5262.677 | 1883.473 | T | EEE-FK1H221P
4 | Q3 | SOT-23B_N | 6417.323 | 2273.74 | 6417.323 | 2273.74 | 6379.922 | 2229.449 | T | PBRP123YT,215
4 | Q4 | SOT-23B_N | 6633.662 | 2027.559 | 6633.662 | 2027.559 | 6671.063 | 2071.851 | T | PBRP123YT,215
4 | Q5 | SOT-23B_N | 6417.126 | 2027.559 | 6417.126 | 2027.559 | 6454.528 | 2071.85 | T | PBRP123YT,215
4 | Q6 | SOT-23B_N | 6850.197 | 2027.559 | 6850.197 | 2027.559 | 6887.599 | 2071.851 | T | PBRP123YT,215
4 | R11 | 8-1206 | 5176.968 | 2391.732 | 5176.969 | 2391.732 | 5176.968 | 2336.614 | T | 150k
4 | R12 | 8-1206 | 5068.702 | 2391.732 | 5068.701 | 2391.732 | 5068.702 | 2446.85 | T | 5.1k
4 | R13 | 6-0805 | 6025.449 | 2221.418 | 6025.449 | 2221.418 | 6025.449 | 2184.017 | T | 1.2k
4 | U3 | A1101 | 8506.417 | 881.102 | 8667.835 | 711.811 | 8667.835 | 711.811 | T | A1101R09A
4 | R2 | 6-0805 | 7657.284 | 1604.331 | 7657.284 | 1604.331 | 7657.284 | 1566.929 | T | ERJ-6GEYJ103V
4 | U5 | BOURNS_4816P_RESISTOR | 7197.677 | 2209.921 | 7197.677 | 2209.921 | 7335.473 | 2034.921 | T | 4816P-T01-330LF
4 | U8 | SOIC127P600X175-16N | 7552.677 | 2209.921 | 7552.677 | 2209.921 | 7647.166 | 2034.921 | T | ULN2003A
4 | C5 | TC7343-2917 | 4930.906 | 996.063 | 4930.906 | 996.063 | 4930.906 | 870.078 | T | TPSD227M010R0100
4 | C7 | 1206 | 5732.351 | 1728.628 | 5732.351 | 1728.628 | 5677.233 | 1728.628 | T | C1206C104K5RACTU
5 | L1 | INDP104103X40N | 4714.37 | 3897.638 | 4724.213 | 3897.638 | 4714.37 | 3720.472 | T | PF0560.683NLT
5 | U4 | SOIC127P600-8AN | 5243.897 | 3901.575 | 5243.898 | 3901.575 | 5318.897 | 4000 | T | MIC4680-3.3YM
5 | D1 | B260A | 4999.803 | 3897.631 | 4999.803 | 3897.638 | 4999.803 | 3976.372 | T | B260A-13-F
5 | C4 | TC7343-2917 | 5301.678 | 4176.237 | 5301.677 | 4176.236 | 5427.662 | 4176.237 | T | TPSD156M035R0300
5 | C1 | 1206 | 8473.229 | 4039.37 | 8473.228 | 4039.37 | 8473.229 | 3984.252 | T | C1206C104K5RACTU
5 | C2 | 1206 | 7785.236 | 4014.764 | 7785.236 | 4014.764 | 7785.236 | 3959.646 | T | C1206C104K5RACTU
5 | C3 | 1206 | 8407.676 | 4710.236 | 8407.677 | 4710.236 | 8407.676 | 4765.354 | T | C1206C104K5RACTU
5 | C6 | 1206 | 8201.449 | 3503.252 | 8201.449 | 3503.252 | 8201.449 | 3448.134 | T | C1206C104K5RACTU
5 | Q2 | SOT-23B_N | 6633.661 | 4755.905 | 6633.662 | 4755.906 | 6596.259 | 4711.614 | T | PBRP123YT,215
5 | Q7 | SOT-23B_N | 6850.197 | 4755.905 | 6850.197 | 4755.906 | 6812.795 | 4711.614 | T | PBRP123YT,215
5 | R1 | 6-0805 | 8103.078 | 3701.236 | 8103.078 | 3701.237 | 8065.677 | 3701.236 | T | ERJ-6GEYJ103V
5 | U1 | TQFP-PT44_N | 8110.039 | 4027.559 | 8110.039 | 4027.559 | 7887.599 | 4185.039 | T | PIC18F45K20-I/PT
5 | U2 | SOIC127P1030-20BN | 8090.354 | 4685.039 | 8090.355 | 4685.039 | 7895.472 | 4910.039 | T | PCF2129AT
5 | C10 | 1210 | 4729.449 | 4660.134 | 4729.449 | 4660.134 | 4729.449 | 4605.016 | T | C1210C105K5RACTU
5 | C11 | 1206 | 5723.45 | 4691.134 | 5723.449 | 4691.134 | 5723.45 | 4746.252 | T | C1206C104K5RACTU
5 | C12 | 1206 | 4751.772 | 4940.946 | 4751.772 | 4940.945 | 4751.772 | 4885.828 | T | C1206C476M8PACTU
5 | C13 | 1206 | 5823.448 | 4689.133 | 5823.449 | 4689.134 | 5823.448 | 4744.252 | T | C1206C104K5RACTU
5 | C14 | 1206 | 5930.448 | 4691.133 | 5930.449 | 4691.134 | 5930.448 | 4746.252 | T | C1206C104K5RACTU
5 | C15 | 1206 | 4739.449 | 4452.134 | 4739.449 | 4452.134 | 4739.449 | 4397.016 | T | C1206C104K5RACTU
5 | C16 | PANASONIC_SIZE_G | 5262.677 | 4523.236 | 5262.677 | 4523.236 | 5262.677 | 4363.788 | T | EEE-FK1H221P
5 | Q3 | SOT-23B_N | 6417.323 | 4754.055 | 6417.323 | 4754.055 | 6379.922 | 4709.764 | T | PBRP123YT,215
5 | Q4 | SOT-23B_N | 6633.662 | 4507.874 | 6633.662 | 4507.874 | 6671.063 | 4552.166 | T | PBRP123YT,215
5 | Q5 | SOT-23B_N | 6417.126 | 4507.874 | 6417.126 | 4507.874 | 6454.528 | 4552.165 | T | PBRP123YT,215
5 | Q6 | SOT-23B_N | 6850.197 | 4507.874 | 6850.197 | 4507.874 | 6887.599 | 4552.166 | T | PBRP123YT,215
5 | R11 | 8-1206 | 5176.968 | 4872.047 | 5176.969 | 4872.047 | 5176.968 | 4816.929 | T | 150k
5 | R12 | 8-1206 | 5068.702 | 4872.047 | 5068.701 | 4872.047 | 5068.702 | 4927.165 | T | 5.1k
5 | R13 | 6-0805 | 6025.449 | 4701.733 | 6025.449 | 4701.733 | 6025.449 | 4664.332 | T | 1.2k
5 | U3 | A1101 | 8506.417 | 3361.417 | 8667.835 | 3192.126 | 8667.835 | 3192.126 | T | A1101R09A
5 | R2 | 6-0805 | 7657.284 | 4084.646 | 7657.284 | 4084.646 | 7657.284 | 4047.244 | T | ERJ-6GEYJ103V
5 | U5 | BOURNS_4816P_RESISTOR | 7197.677 | 4690.236 | 7197.677 | 4690.236 | 7335.473 | 4515.236 | T | 4816P-T01-330LF
5 | U8 | SOIC127P600X175-16N | 7552.677 | 4690.236 | 7552.677 | 4690.236 | 7647.166 | 4515.236 | T | ULN2003A
5 | C5 | TC7343-2917 | 4930.906 | 3476.378 | 4930.906 | 3476.378 | 4930.906 | 3350.393 | T | TPSD227M010R0100
5 | C7 | 1206 | 5732.351 | 4208.943 | 5732.351 | 4208.943 | 5677.233 | 4208.943 | T | C1206C104K5RACTU
6 | L1 | INDP104103X40N | 4714.37 | 6377.953 | 4724.213 | 6377.953 | 4714.37 | 6200.788 | T | PF0560.683NLT
6 | U4 | SOIC127P600-8AN | 5243.897 | 6381.89 | 5243.898 | 6381.89 | 5318.897 | 6480.315 | T | MIC4680-3.3YM
6 | D1 | B260A | 4999.803 | 6377.946 | 4999.803 | 6377.953 | 4999.803 | 6456.687 | T | B260A-13-F
6 | C4 | TC7343-2917 | 5301.678 | 6656.552 | 5301.677 | 6656.551 | 5427.662 | 6656.552 | T | TPSD156M035R0300
6 | C1 | 1206 | 8473.229 | 6519.685 | 8473.228 | 6519.685 | 8473.229 | 6464.567 | T | C1206C104K5RACTU
6 | C2 | 1206 | 7785.236 | 6495.079 | 7785.236 | 6495.079 | 7785.236 | 6439.961 | T | C1206C104K5RACTU
6 | C3 | 1206 | 8407.676 | 7190.551 | 8407.677 | 7190.551 | 8407.676 | 7245.669 | T | C1206C104K5RACTU
6 | C6 | 1206 | 8201.449 | 5983.567 | 8201.449 | 5983.567 | 8201.449 | 5928.449 | T | C1206C104K5RACTU
6 | Q2 | SOT-23B_N | 6633.661 | 7236.22 | 6633.662 | 7236.221 | 6596.259 | 7191.929 | T | PBRP123YT,215
6 | Q7 | SOT-23B_N | 6850.197 | 7236.22 | 6850.197 | 7236.221 | 6812.795 | 7191.929 | T | PBRP123YT,215
6 | R1 | 6-0805 | 8103.078 | 6181.551 | 8103.078 | 6181.552 | 8065.677 | 6181.551 | T | ERJ-6GEYJ103V
6 | U1 | TQFP-PT44_N | 8110.039 | 6507.874 | 8110.039 | 6507.874 | 7887.599 | 6665.355 | T | PIC18F45K20-I/PT
6 | U2 | SOIC127P1030-20BN | 8090.354 | 7165.354 | 8090.355 | 7165.354 | 7895.472 | 7390.354 | T | PCF2129AT
6 | C10 | 1210 | 4729.449 | 7140.449 | 4729.449 | 7140.449 | 4729.449 | 7085.331 | T | C1210C105K5RACTU
6 | C11 | 1206 | 5723.45 | 7171.449 | 5723.449 | 7171.449 | 5723.45 | 7226.567 | T | C1206C104K5RACTU
6 | C12 | 1206 | 4751.772 | 7421.261 | 4751.772 | 7421.26 | 4751.772 | 7366.143 | T | C1206C476M8PACTU
6 | C13 | 1206 | 5823.448 | 7169.449 | 5823.449 | 7169.449 | 5823.448 | 7224.566 | T | C1206C104K5RACTU
6 | C14 | 1206 | 5930.448 | 7171.449 | 5930.449 | 7171.449 | 5930.448 | 7226.566 | T | C1206C104K5RACTU
6 | C15 | 1206 | 4739.449 | 6932.449 | 4739.449 | 6932.449 | 4739.449 | 6877.331 | T | C1206C104K5RACTU
6 | C16 | PANASONIC_SIZE_G | 5262.677 | 7003.551 | 5262.677 | 7003.551 | 5262.677 | 6844.102 | T | EEE-FK1H221P
6 | Q3 | SOT-23B_N | 6417.323 | 7234.37 | 6417.323 | 7234.37 | 6379.922 | 7190.079 | T | PBRP123YT,215
6 | Q4 | SOT-23B_N | 6633.662 | 6988.189 | 6633.662 | 6988.189 | 6671.063 | 7032.481 | T | PBRP123YT,215
6 | Q5 | SOT-23B_N | 6417.126 | 6988.189 | 6417.126 | 6988.189 | 6454.528 | 7032.48 | T | PBRP123YT,215
6 | Q6 | SOT-23B_N | 6850.197 | 6988.189 | 6850.197 | 6988.189 | 6887.599 | 7032.481 | T | PBRP123YT,215
6 | R11 | 8-1206 | 5176.968 | 7352.362 | 5176.969 | 7352.362 | 5176.968 | 7297.244 | T | 150k
6 | R12 | 8-1206 | 5068.702 | 7352.362 | 5068.701 | 7352.362 | 5068.702 | 7407.48 | T | 5.1k
6 | R13 | 6-0805 | 6025.449 | 7182.048 | 6025.449 | 7182.047 | 6025.449 | 7144.647 | T | 1.2k
6 | U3 | A1101 | 8506.417 | 5841.732 | 8667.835 | 5672.441 | 8667.835 | 5672.441 | T | A1101R09A
6 | R2 | 6-0805 | 7657.284 | 6564.961 | 7657.284 | 6564.961 | 7657.284 | 6527.559 | T | ERJ-6GEYJ103V
6 | U5 | BOURNS_4816P_RESISTOR | 7197.677 | 7170.551 | 7197.677 | 7170.551 | 7335.473 | 6995.551 | T | 4816P-T01-330LF
6 | U8 | SOIC127P600X175-16N | 7552.677 | 7170.551 | 7552.677 | 7170.551 | 7647.166 | 6995.551 | T | ULN2003A
6 | C5 | TC7343-2917 | 4930.906 | 5956.693 | 4930.906 | 5956.693 | 4930.906 | 5830.708 | T | TPSD227M010R0100
6 | C7 | 1206 | 5732.351 | 6689.258 | 5732.351 | 6689.258 | 5677.233 | 6689.258 | T | C1206C104K5RACTU
7 | L1 | INDP104103X40N | 9123.819 | 1417.323 | 9133.662 | 1417.323 | 9123.819 | 1240.158 | T | PF0560.683NLT
7 | U4 | SOIC127P600-8AN | 9653.346 | 1421.26 | 9653.347 | 1421.26 | 9728.346 | 1519.685 | T | MIC4680-3.3YM
7 | D1 | B260A | 9409.252 | 1417.316 | 9409.252 | 1417.323 | 9409.252 | 1496.057 | T | B260A-13-F
7 | C4 | TC7343-2917 | 9711.127 | 1695.922 | 9711.126 | 1695.921 | 9837.111 | 1695.922 | T | TPSD156M035R0300
7 | C1 | 1206 | 12882.678 | 1559.055 | 12882.677 | 1559.055 | 12882.678 | 1503.937 | T | C1206C104K5RACTU
7 | C2 | 1206 | 12194.685 | 1534.449 | 12194.685 | 1534.449 | 12194.685 | 1479.331 | T | C1206C104K5RACTU
7 | C3 | 1206 | 12817.126 | 2229.921 | 12817.126 | 2229.921 | 12817.126 | 2285.039 | T | C1206C104K5RACTU
7 | C6 | 1206 | 12610.898 | 1022.937 | 12610.898 | 1022.937 | 12610.898 | 967.819 | T | C1206C104K5RACTU
7 | Q2 | SOT-23B_N | 11043.11 | 2275.59 | 11043.111 | 2275.591 | 11005.708 | 2231.299 | T | PBRP123YT,215
7 | Q7 | SOT-23B_N | 11259.646 | 2275.59 | 11259.646 | 2275.591 | 11222.244 | 2231.299 | T | PBRP123YT,215
7 | R1 | 6-0805 | 12512.527 | 1220.921 | 12512.527 | 1220.922 | 12475.126 | 1220.921 | T | ERJ-6GEYJ103V
7 | U1 | TQFP-PT44_N | 12519.488 | 1547.244 | 12519.488 | 1547.244 | 12297.048 | 1704.725 | T | PIC18F45K20-I/PT
7 | U2 | SOIC127P1030-20BN | 12499.803 | 2204.724 | 12499.803 | 2204.724 | 12304.921 | 2429.724 | T | PCF2129AT
7 | C10 | 1210 | 9138.898 | 2179.819 | 9138.898 | 2179.819 | 9138.898 | 2124.701 | T | C1210C105K5RACTU
7 | C11 | 1206 | 10132.899 | 2210.819 | 10132.898 | 2210.819 | 10132.899 | 2265.937 | T | C1206C104K5RACTU
7 | C12 | 1206 | 9161.221 | 2460.631 | 9161.221 | 2460.63 | 9161.221 | 2405.513 | T | C1206C476M8PACTU
7 | C13 | 1206 | 10232.897 | 2208.818 | 10232.898 | 2208.819 | 10232.897 | 2263.936 | T | C1206C104K5RACTU
7 | C14 | 1206 | 10339.897 | 2210.818 | 10339.898 | 2210.819 | 10339.897 | 2265.936 | T | C1206C104K5RACTU
7 | C15 | 1206 | 9148.898 | 1971.819 | 9148.898 | 1971.819 | 9148.898 | 1916.701 | T | C1206C104K5RACTU
7 | C16 | PANASONIC_SIZE_G | 9672.126 | 2042.921 | 9672.126 | 2042.921 | 9672.126 | 1883.473 | T | EEE-FK1H221P
7 | Q3 | SOT-23B_N | 10826.772 | 2273.74 | 10826.772 | 2273.74 | 10789.371 | 2229.449 | T | PBRP123YT,215
7 | Q4 | SOT-23B_N | 11043.111 | 2027.559 | 11043.111 | 2027.559 | 11080.512 | 2071.851 | T | PBRP123YT,215
7 | Q5 | SOT-23B_N | 10826.575 | 2027.559 | 10826.575 | 2027.559 | 10863.977 | 2071.85 | T | PBRP123YT,215
7 | Q6 | SOT-23B_N | 11259.646 | 2027.559 | 11259.646 | 2027.559 | 11297.048 | 2071.851 | T | PBRP123YT,215
7 | R11 | 8-1206 | 9586.417 | 2391.732 | 9586.418 | 2391.732 | 9586.417 | 2336.614 | T | 150k
7 | R12 | 8-1206 | 9478.151 | 2391.732 | 9478.15 | 2391.732 | 9478.151 | 2446.85 | T | 5.1k
7 | R13 | 6-0805 | 10434.898 | 2221.418 | 10434.898 | 2221.418 | 10434.898 | 2184.017 | T | 1.2k
7 | U3 | A1101 | 12915.867 | 881.102 | 13077.284 | 711.811 | 13077.284 | 711.811 | T | A1101R09A
7 | R2 | 6-0805 | 12066.733 | 1604.331 | 12066.733 | 1604.331 | 12066.733 | 1566.929 | T | ERJ-6GEYJ103V
7 | U5 | BOURNS_4816P_RESISTOR | 11607.126 | 2209.921 | 11607.126 | 2209.921 | 11744.922 | 2034.921 | T | 4816P-T01-330LF
7 | U8 | SOIC127P600X175-16N | 11962.126 | 2209.921 | 11962.126 | 2209.921 | 12056.614 | 2034.921 | T | ULN2003A
7 | C5 | TC7343-2917 | 9340.355 | 996.063 | 9340.355 | 996.063 | 9340.355 | 870.078 | T | TPSD227M010R0100
7 | C7 | 1206 | 10141.8 | 1728.628 | 10141.8 | 1728.628 | 10086.682 | 1728.628 | T | C1206C104K5RACTU
8 | L1 | INDP104103X40N | 9123.819 | 3897.638 | 9133.662 | 3897.638 | 9123.819 | 3720.472 | T | PF0560.683NLT
8 | U4 | SOIC127P600-8AN | 9653.346 | 3901.575 | 9653.347 | 3901.575 | 9728.346 | 4000 | T | MIC4680-3.3YM
8 | D1 | B260A | 9409.252 | 3897.631 | 9409.252 | 3897.638 | 9409.252 | 3976.372 | T | B260A-13-F
8 | C4 | TC7343-2917 | 9711.127 | 4176.237 | 9711.126 | 4176.236 | 9837.111 | 4176.237 | T | TPSD156M035R0300
8 | C1 | 1206 | 12882.678 | 4039.37 | 12882.677 | 4039.37 | 12882.678 | 3984.252 | T | C1206C104K5RACTU
8 | C2 | 1206 | 12194.685 | 4014.764 | 12194.685 | 4014.764 | 12194.685 | 3959.646 | T | C1206C104K5RACTU
8 | C3 | 1206 | 12817.126 | 4710.236 | 12817.126 | 4710.236 | 12817.126 | 4765.354 | T | C1206C104K5RACTU
8 | C6 | 1206 | 12610.898 | 3503.252 | 12610.898 | 3503.252 | 12610.898 | 3448.134 | T | C1206C104K5RACTU
8 | Q2 | SOT-23B_N | 11043.11 | 4755.905 | 11043.111 | 4755.906 | 11005.708 | 4711.614 | T | PBRP123YT,215
8 | Q7 | SOT-23B_N | 11259.646 | 4755.905 | 11259.646 | 4755.906 | 11222.244 | 4711.614 | T | PBRP123YT,215
8 | R1 | 6-0805 | 12512.527 | 3701.236 | 12512.527 | 3701.237 | 12475.126 | 3701.236 | T | ERJ-6GEYJ103V
8 | U1 | TQFP-PT44_N | 12519.488 | 4027.559 | 12519.488 | 4027.559 | 12297.048 | 4185.039 | T | PIC18F45K20-I/PT
8 | U2 | SOIC127P1030-20BN | 12499.803 | 4685.039 | 12499.803 | 4685.039 | 12304.921 | 4910.039 | T | PCF2129AT
8 | C10 | 1210 | 9138.898 | 4660.134 | 9138.898 | 4660.134 | 9138.898 | 4605.016 | T | C1210C105K5RACTU
8 | C11 | 1206 | 10132.899 | 4691.134 | 10132.898 | 4691.134 | 10132.899 | 4746.252 | T | C1206C104K5RACTU
8 | C12 | 1206 | 9161.221 | 4940.946 | 9161.221 | 4940.945 | 9161.221 | 4885.828 | T | C1206C476M8PACTU
8 | C13 | 1206 | 10232.897 | 4689.133 | 10232.898 | 4689.134 | 10232.897 | 4744.252 | T | C1206C104K5RACTU
8 | C14 | 1206 | 10339.897 | 4691.133 | 10339.898 | 4691.134 | 10339.897 | 4746.252 | T | C1206C104K5RACTU
8 | C15 | 1206 | 9148.898 | 4452.134 | 9148.898 | 4452.134 | 9148.898 | 4397.016 | T | C1206C104K5RACTU
8 | C16 | PANASONIC_SIZE_G | 9672.126 | 4523.236 | 9672.126 | 4523.236 | 9672.126 | 4363.788 | T | EEE-FK1H221P
8 | Q3 | SOT-23B_N | 10826.772 | 4754.055 | 10826.772 | 4754.055 | 10789.371 | 4709.764 | T | PBRP123YT,215
8 | Q4 | SOT-23B_N | 11043.111 | 4507.874 | 11043.111 | 4507.874 | 11080.512 | 4552.166 | T | PBRP123YT,215
8 | Q5 | SOT-23B_N | 10826.575 | 4507.874 | 10826.575 | 4507.874 | 10863.977 | 4552.165 | T | PBRP123YT,215
8 | Q6 | SOT-23B_N | 11259.646 | 4507.874 | 11259.646 | 4507.874 | 11297.048 | 4552.166 | T | PBRP123YT,215
8 | R11 | 8-1206 | 9586.417 | 4872.047 | 9586.418 | 4872.047 | 9586.417 | 4816.929 | T | 150k
8 | R12 | 8-1206 | 9478.151 | 4872.047 | 9478.15 | 4872.047 | 9478.151 | 4927.165 | T | 5.1k
8 | R13 | 6-0805 | 10434.898 | 4701.733 | 10434.898 | 4701.733 | 10434.898 | 4664.332 | T | 1.2k
8 | U3 | A1101 | 12915.867 | 3361.417 | 13077.284 | 3192.126 | 13077.284 | 3192.126 | T | A1101R09A
8 | R2 | 6-0805 | 12066.733 | 4084.646 | 12066.733 | 4084.646 | 12066.733 | 4047.244 | T | ERJ-6GEYJ103V
8 | U5 | BOURNS_4816P_RESISTOR | 11607.126 | 4690.236 | 11607.126 | 4690.236 | 11744.922 | 4515.236 | T | 4816P-T01-330LF
8 | U8 | SOIC127P600X175-16N | 11962.126 | 4690.236 | 11962.126 | 4690.236 | 12056.614 | 4515.236 | T | ULN2003A
8 | C5 | TC7343-2917 | 9340.355 | 3476.378 | 9340.355 | 3476.378 | 9340.355 | 3350.393 | T | TPSD227M010R0100
8 | C7 | 1206 | 10141.8 | 4208.943 | 10141.8 | 4208.943 | 10086.682 | 4208.943 | T | C1206C104K5RACTU
9 | L1 | INDP104103X40N | 9123.819 | 6377.953 | 9133.662 | 6377.953 | 9123.819 | 6200.788 | T | PF0560.683NLT
9 | U4 | SOIC127P600-8AN | 9653.346 | 6381.89 | 9653.347 | 6381.89 | 9728.346 | 6480.315 | T | MIC4680-3.3YM
9 | D1 | B260A | 9409.252 | 6377.946 | 9409.252 | 6377.953 | 9409.252 | 6456.687 | T | B260A-13-F
9 | C4 | TC7343-2917 | 9711.127 | 6656.552 | 9711.126 | 6656.551 | 9837.111 | 6656.552 | T | TPSD156M035R0300
9 | C1 | 1206 | 12882.678 | 6519.685 | 12882.677 | 6519.685 | 12882.678 | 6464.567 | T | C1206C104K5RACTU
9 | C2 | 1206 | 12194.685 | 6495.079 | 12194.685 | 6495.079 | 12194.685 | 6439.961 | T | C1206C104K5RACTU
9 | C3 | 1206 | 12817.126 | 7190.551 | 12817.126 | 7190.551 | 12817.126 | 7245.669 | T | C1206C104K5RACTU
9 | C6 | 1206 | 12610.898 | 5983.567 | 12610.898 | 5983.567 | 12610.898 | 5928.449 | T | C1206C104K5RACTU
9 | Q2 | SOT-23B_N | 11043.11 | 7236.22 | 11043.111 | 7236.221 | 11005.708 | 7191.929 | T | PBRP123YT,215
9 | Q7 | SOT-23B_N | 11259.646 | 7236.22 | 11259.646 | 7236.221 | 11222.244 | 7191.929 | T | PBRP123YT,215
9 | R1 | 6-0805 | 12512.527 | 6181.551 | 12512.527 | 6181.552 | 12475.126 | 6181.551 | T | ERJ-6GEYJ103V
9 | U1 | TQFP-PT44_N | 12519.488 | 6507.874 | 12519.488 | 6507.874 | 12297.048 | 6665.355 | T | PIC18F45K20-I/PT
9 | U2 | SOIC127P1030-20BN | 12499.803 | 7165.354 | 12499.803 | 7165.354 | 12304.921 | 7390.354 | T | PCF2129AT
9 | C10 | 1210 | 9138.898 | 7140.449 | 9138.898 | 7140.449 | 9138.898 | 7085.331 | T | C1210C105K5RACTU
9 | C11 | 1206 | 10132.899 | 7171.449 | 10132.898 | 7171.449 | 10132.899 | 7226.567 | T | C1206C104K5RACTU
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

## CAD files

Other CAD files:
Schematics/Gerbers/LED_Panel_Gerbers/Nixie panel.SLDPRT

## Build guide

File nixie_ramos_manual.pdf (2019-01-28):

# Ramos Alarm Clock

### A Sammut Technologies Product

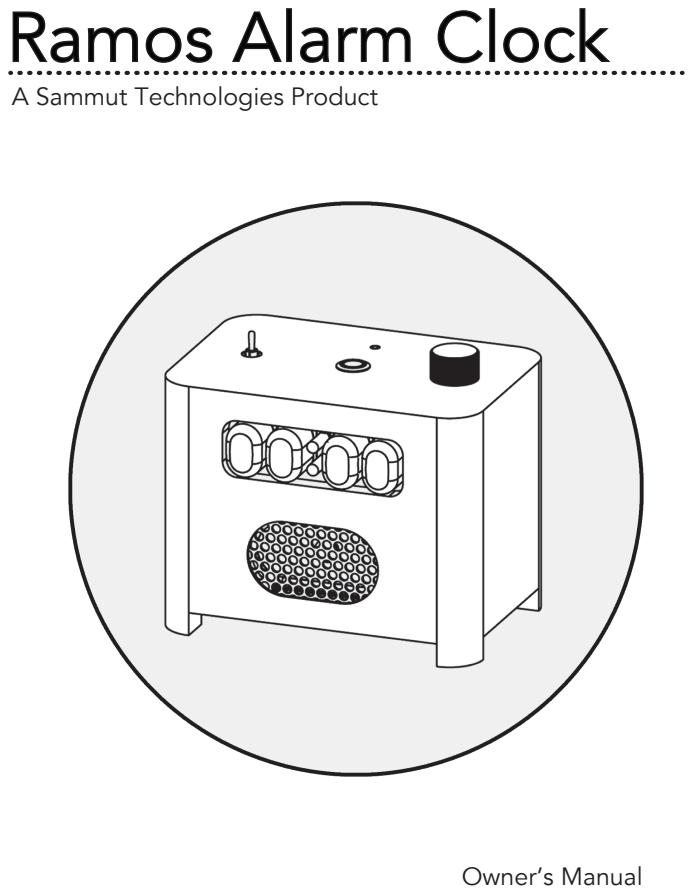
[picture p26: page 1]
Owner’s Manual

The Ramos Alarm Clock comes fully packed with features. A remote alarm system to make sure you get started. A customizable snooze lets you wake up at your pace. Enable lockdown mode if you're prone to changing the alarm overnight. Turn on courtesy mode to keep things quiet. Do it al l with Ramos.

# Features

### Ramos Mode

Ramos mode enables the Defuse Panel. Once the alarm begins to ring, the only way to turn it off is by entering the defuse code into the panel.

### Snooze Settings

To snooze, press the snooze button. In the menu, you can set the number of snoozes allowed [0-1 0] before the Defuse panel is enabled. You can also set the period in minutes [5-60] that Ramos will snooze for.

### Courtesy Mode

Courtesy mode keeps the Ramos from waking the whole house. The alarm will ring for [5-60] seconds before going quiet for 1 minute, allowing you time to defuse Ramos.

### Lockdown Mode

Lockdown mode prevents any last minute changes to the alarm settings. Once you turn your alarm on, it will need be defused before the setting can be changed.

# What’s in the box?

1 Ramos Alarm Clock | 2 Defuse Panel

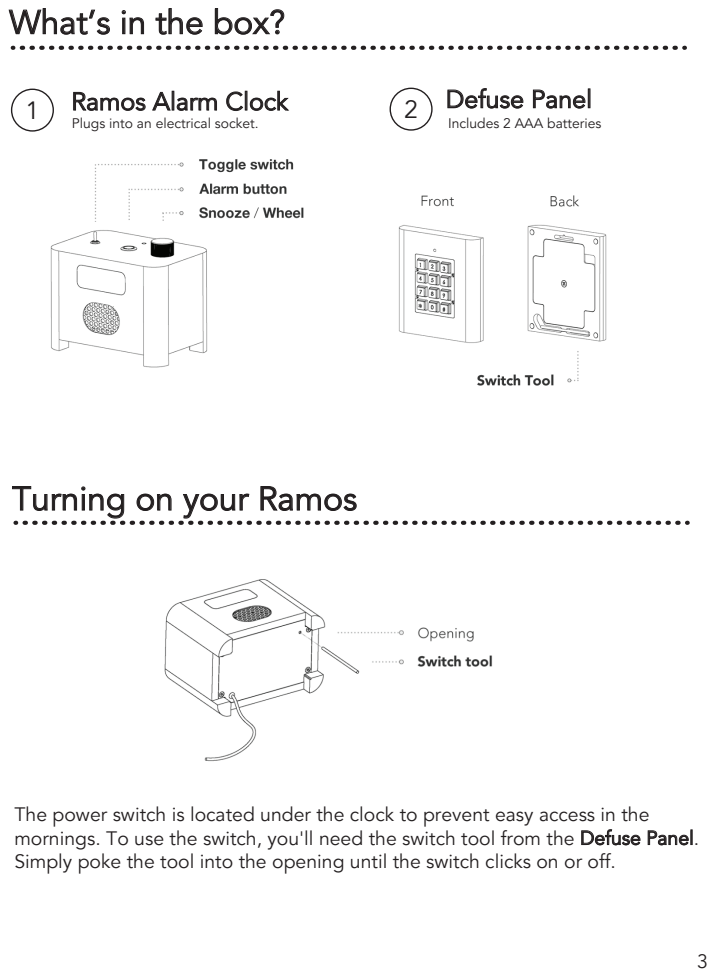
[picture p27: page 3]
Plugs into an electrical socket.; Includes 2 AAA batteries

Turning on your Ramos

The power switch is located under the clock to prevent easy access in the
mornings. To use the switch, you'll need the switch tool from the Defuse Panel.
Simply poke the tool into the opening until the switch clicks on or off.

# Setting the time and the alarm

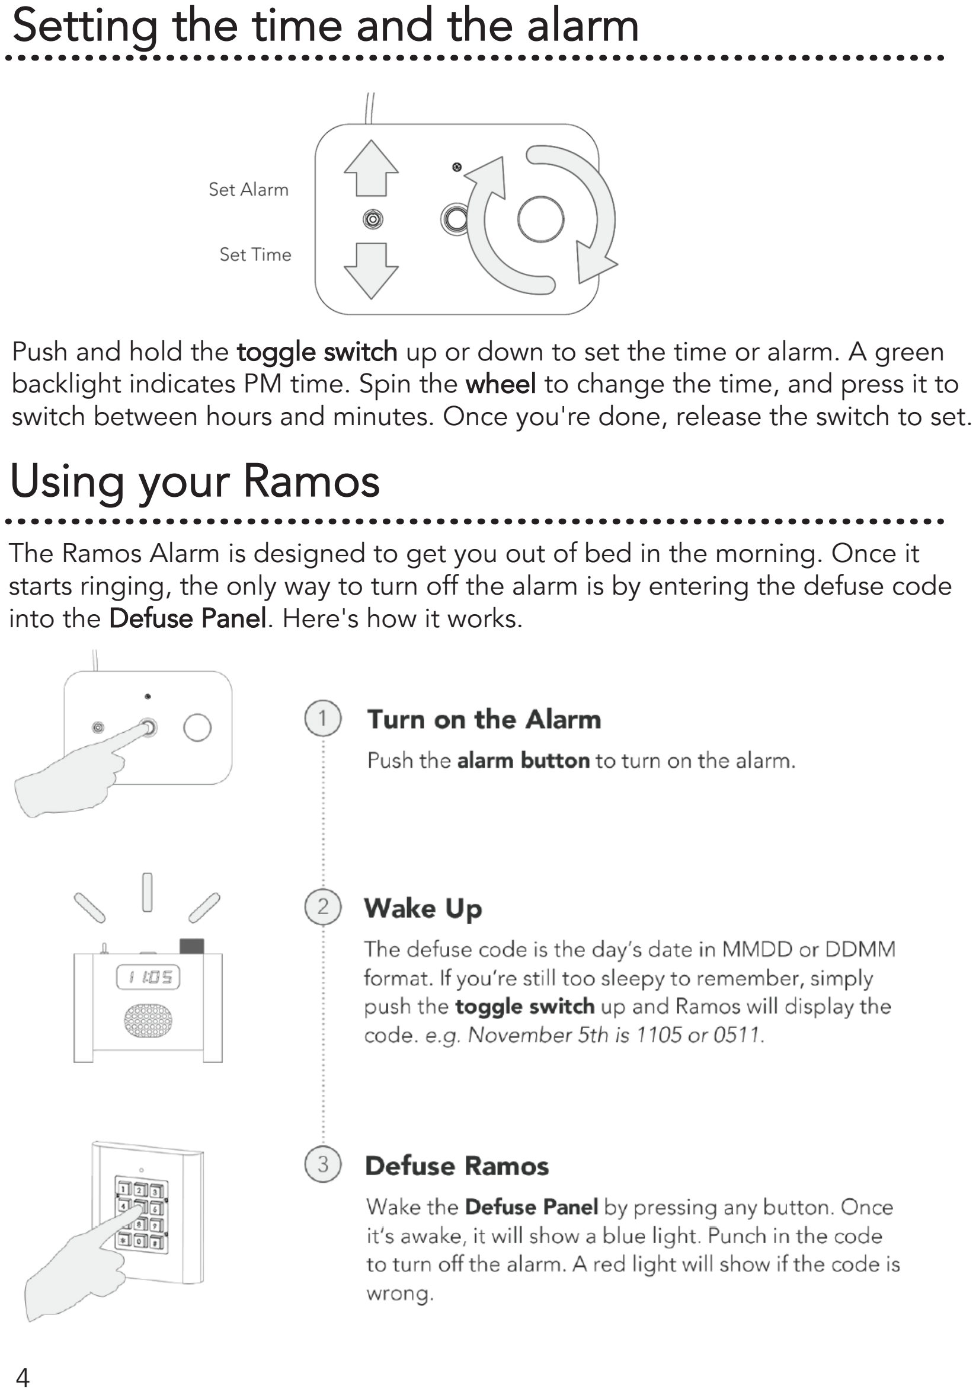
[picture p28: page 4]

# Using your Ramos

Push and hold the toggle switch up or down to set the time or alarm. A green backlight indicates PM time. Spin the wheel to change the time, and press it to switch between hours and minutes. Once you're done, release the switch to set.

The Ramos Alarm is designed to get you out of bed in the morning. Once it starts ringing, the only way to turn off the alarm is by entering the defuse code into the Defuse Panel. Here's how it works.

# Settings Menu

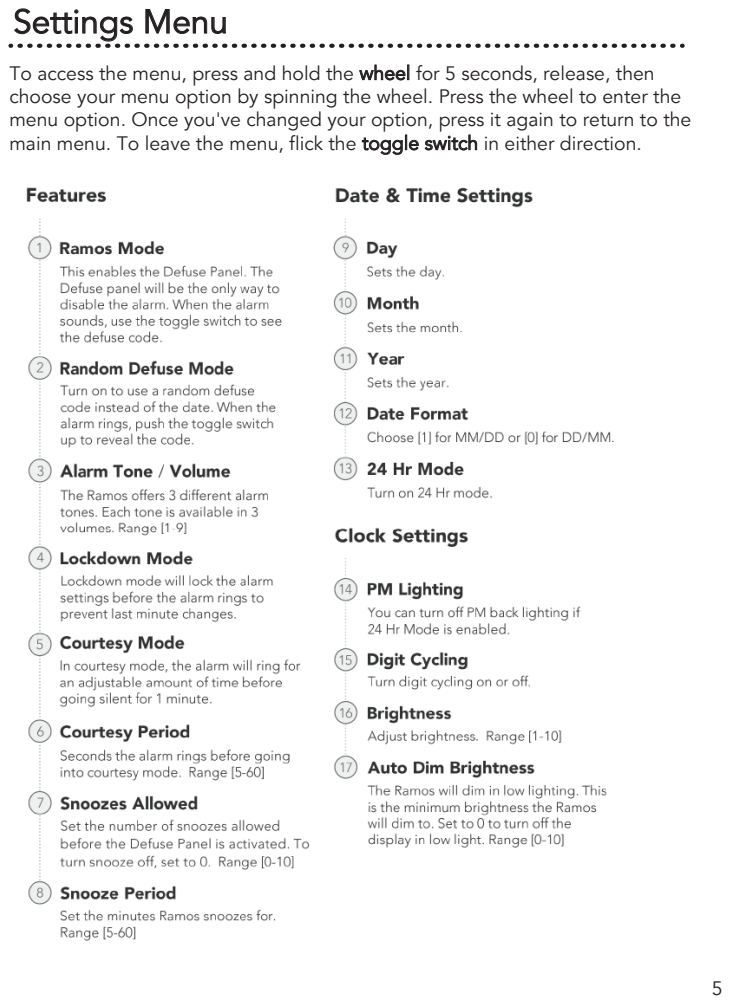
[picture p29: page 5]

To access the menu, press and hold the wheel for 5 seconds, release, then
choose your menu option by spinning the wheel. Press the wheel to enter the
menu option. Once you've changed your option, press it again to return to the
main menu. To leave the menu, flick the toggle switch in either direction.

Wake the defuse panel by pressing any button, then press#. The light will blink green if the panel is in range. If it bli nks red, move the panel closer to Ramos.

# Range check

The defuse panel should be placed where you want to get your day started, whether its the kitchen to make coffee or the bathroom to wake up. It's easier to stay out of bed if you're close to your morning routine.

# Defuse panel placement

The defuse panel uses two AAA batteries. If the panel shows a red light when woken, the batteries need to be replaced.

# Batteries

The Ramos is constructed from wood sealed with shellac, then coated with a lacquer clear coat for a maintenance free finish. Avoid damaging the finish by keeping your Ramos away from sharp objects and liquids.

# Care

The Nixie Ramos uses 4 original Soviet-era nixie tubes. In the case that you have to replace a tube, follow this procedure:

1. Unplug the Nixie Ramos while it is still on. Wait 6 hours for the battery to fully drain. If you don’t do this, you risk blowing the internal safety fuse and rendering your Nixie Ramos useless.
2. Wiggle (gently) out the used nixie tube.
3. Wiggle (gently) in the new one. Do not force the tube.

Nixie tubes contain mercury. Wear gloves when doing this and dispose
of the old tube in accordance to your local laws. Keep children away from this product. In the case of a shattered tube, wear gloves, then unplug the unit and turn it off using the switch rod. Carefully collect all the broken glass.
Do not attempt to replace a shattered tube.

# Nixie tubes

The Nixie Ramos also uses two orignal neon bulbs as a colon seperators. When you first use it, the neon bulbs will flicker. This is normal. After 1-2 weeks of use, the bulbs will age and maintain a steady glow.

# Troubleshooting

If your keypad isn’t communicating with your Nixie Ramos, it most likely means that it is not paired correctly. Follow these steps to pair it:

1. On the clock, hold the knob button for 5 seconds to go into the menu.
2. Get the keypad and press only one button on it to turn it on. Once you
see the blue light, it is on.
3. Bring the keypad within a couple of feet of the clock. Press Star, 9 , 3 , 8. You should see a green light meaning the keypad is paired.
4. Press the range button and see if it goes green. Test it with an alarm and you should now have a paired and working keypad!

# Warranty

Sammut Tech LLC manufactures its products to very high standards and we are confident our products will perform well. Accordingly, we warranty our products against manufacturing defects in material and workmanship to the original owner, for a period of one year from the original date of purchase. In the case of pre-order purchase the warranty will be one year from the date received. This warranty does not extend to damage caused by improper installation, faulty ancillary equipment, modifications, unauthorized repair, shipping damage or loss, abuse, accidents, use on improper voltage/current, lightning or other acts of God, normal wear and tear, commercial use, or purchase from unauthorized dealers. Proof of purchase as evidence the unit was purchased from an authorized dealer within the warranty period may be required for warranty service. This warranty is non-transferable. Sammut Tech LLC wi ll not pay for loss of t ime, inconvenience, loss of use of the product, or damages caused by this product. This warranty gives you specific legal rights and you may also have other rights which vary from state to state. Some states do not allow limitations on implied warranties or the exclusion of consequentia l damages, therefore, these restrictions may not apply to you.

# Feedback & Support

We love hearing from our customers; if you have any questions or comments, please don't hesistate to email us at support@ramosclock.com

WARNING: This product contains lead and lead compounds, and mercury known to the State of
California to cause cancer and
birth defects or other reproductive

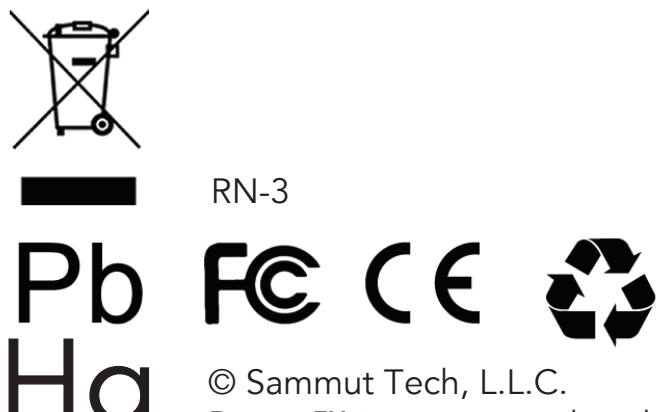
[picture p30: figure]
© Sammut Tech, L.L.C.

harm. | Hg

Ramos™ is a registered trademark. Patent Pending. All rights reserved.

Made in Jersey City,
U.S.A.

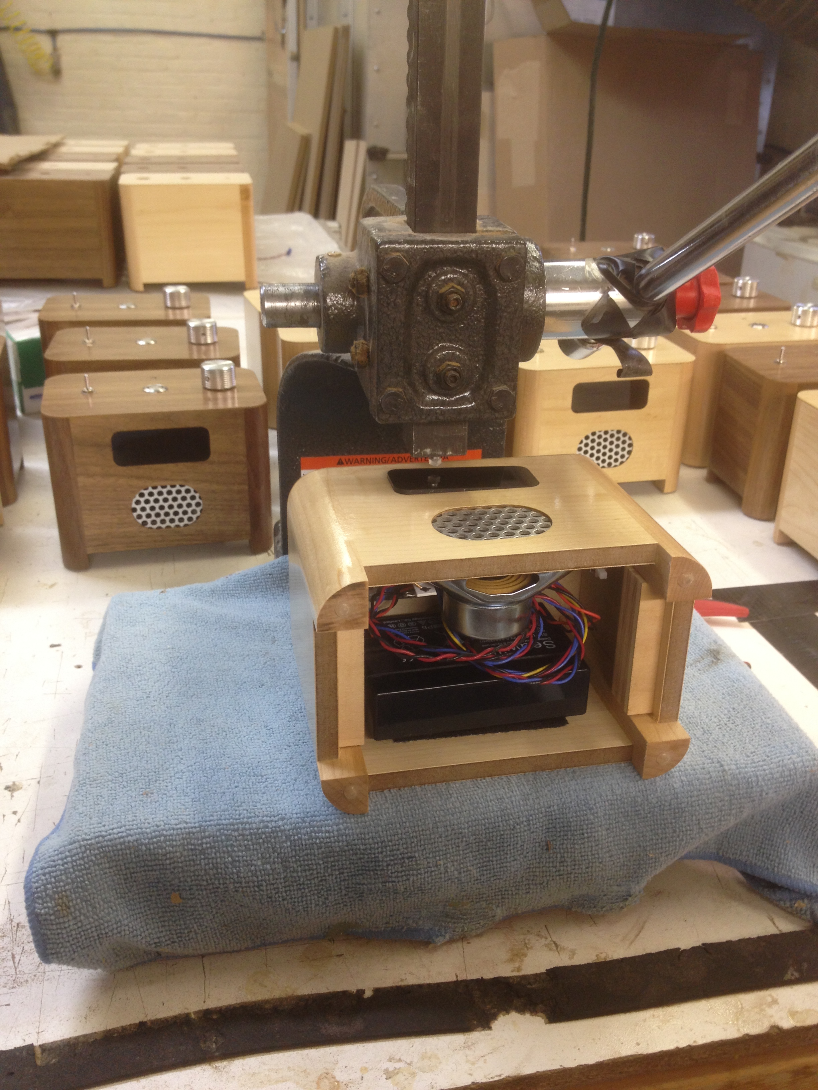
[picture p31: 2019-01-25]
images/assembly.jpg

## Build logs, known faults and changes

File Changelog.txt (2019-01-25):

V1.2 
---------------------------------------
6.2.14

Changed the timers to volatile, along with everything in the LED_display and Nixie_display files.
This was to fix the system hang that occured after the clock ran for a day and the alarm went off.

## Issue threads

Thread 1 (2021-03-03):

LDR diode

cpayne14, 2021-03-03:
Hey Paul,
Having an issue with the LDR on my Nixie Ramos but can't find the product code or specs of the LDR anywhere in the documentation

Do you happen to still have that info?

Thanks in advance
Cameron :)

paulsammut, 2025-04-23:
Sorry for the delay! Whats the LDR?

cpayne14, 2025-04-23:
Hey Paul! I thought you died ahha
I mean the light dependent resistor that adjusts the brightness
If you also have the specs of the click wheel / potentiometer thing that would be sick :)

Thanks!

paulsammut, 2025-04-25:
https://www.digikey.com/en/products/detail/advanced-photonix/NSL-5150/5039798

There it is! FYI it's gonna be a PAIN to replace it. We hot glued it in place. Good luck, maybe u could drill it out CAREFULLY.

See issue #2 for the encoder part info 😀

Are you sure it's broken?

Please Lmk if u need more help!

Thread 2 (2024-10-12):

Encoder problem

racalac, 2024-10-12:
Hi, do you have a part number for the encoder? Mine is acting up after all this time. I rotate to change the alarm time and 2 clicks do nothing, next click changes the value by 1, next click does nothing, next click lowers the value by 1. Probably something impeding part of the quadrature encoding. Blowing air into the part fixed things temporarily.

A BOM would be very helpful for repair work.

Thank you.

MiskatonicU, 2025-04-22:
@racalac Don't suppose you ever got any further details form @paulsammut ?  My LED Ramos started having this same issue and I was hoping it would just be a matter of replacing the encoder, but that means knowing the part number.

racalac, 2025-04-23:
@MiskatonicU Sorry I never heard from him. Maybe a replacement part is obvious to someone who works with them more often?

paulsammut, 2025-04-23:
Sorry i missed this guys!!!

Here's the part: https://www.digikey.com/en/products/detail/cts-electrocomponents/288X232R161B2/270037

It's got a 3 wire cable soldered to it terminated to 3 pin MTA100 connector. Would be easy to desolder and solder it back on the replacement. Just keep note of the pinout to wire color.

FYI CAD is here which is where i found the part number cause I lost all the bom files this project 😂

https://grabcad.com/library/nixie-ramos-alarm-clock-1/details?folder_id=5791349

paulsammut, 2025-04-23:
Yup same one in the LED ramos. Hah yeah cut em by hand but we had a lathe at least.

I may have some spares (cut and with cable) laying around - I'll check this week. DM your address and I'll send it over when/if i find it

paulsammut, 2025-04-23:
Yup same one in the LED ramos. Hah yeah cut em by hand but we had a lathe at least.

I may have some spares (cut and with cable) laying around - I'll check this week. DM your address and I'll send it over when/if i find it

MiskatonicU, 2025-04-23:
@paulsammut You already got in contact with me via email, but I'm glad you also responded here as I saw someone else had posted with the same issue.

Also, sorry again for pinging you on so many platforms,

paulsammut, 2025-04-25:
Ah sorry guys just checked my boxes of clock parts and I dont have spares. you can order a replacement from Digikey and desolder the wires and solder on the new one. Also you'll have to cut the stem to the same height.

Lmk if u need more info on how to do it!

MiskatonicU, 2025-04-25:
No worries, I appreciate that you checked if you had any replacements.

I too am more of a software person than hardware.  I've used an iron to do some through-hold soldering, but it's been quite some time and I don't own an iron anymore.

I roughly described what I understand to be the steps involved in the repair to an engineer friend and he thought the soldering work would be easy enough and offered to do it for me if can provide the parts.

I haven't opened the clock myself yet, but I took a few captures from this [YouTube video where the backup battery was replaced](https://www.youtube.com/watch?v=4GUXdHicJHw) to get an idea of the internals.

If you don't mind, could you give a rough set of steps involved with the repair?  If that's a bit too involved, maybe just answering the following questions will clear up a few of the steps for me.

1. What is needed to prepare the new encoder for installation?  It sounds like the stem will need to be cut down to the correct height.  Not sure I can get access to a belt sander, so maybe a vice and hacksaw will do?

2. In the above video,  a screwdriver was ground down to fit the screws used to secure the clock's base panel.  Is there a particular size and style of bit to use to avoid the need to sacrifice a screwdriver?

3. I think the biggest unknown for me is how to remove the existing encoder from the clock, as I'm not entirely sure how it's secured to the top of the clock.  I assume the cap can be removed just by loosening the screw securing it to the stem, but how is the base of the encoder mounted inside?  Should the internal battery be disconnected before removing the encoder?

4. The other end of the wires terminates in a 3 pin connector which plugs in somewhere on the main board, does the orientation matter?  Any chance you can attach a picture of the main board highlighting the pins the connector goes to?

5. Any other repairs I should make while I have the clock open?  Replace the CR2032 battery?  Replace the backup battery as in the Youtube video?  If the latter is recommended, is searching eBay for "UB1208K" still the best way to get a replacement?

paulsammut, 2025-05-01:
1. cut the encoder shaft same length as the orig. Chuck the waste stem end and cut with a hacksaw
2. use a square drive bit
3. take the knob off and use a socket to loosen the nut that holds the encoder
4. take a pick of where the encoder connector is on the main board and put it in the same exact spot
5. yup both those things are good to do

MiskatonicU, 2025-05-01:
@paulsammut Thanks again for the details.  I just got the replacement encoder, waiting on the battery and should be able attempt the repair soon.

Ramosuser007, 2025-08-21:
Hi. The 5 cable soldering has come apart on my ramos adjuster know. Can anyone assist with a wiring diagram so I can try reconnecting?
I'm lost without my 11 year old alarm clock... only thing that was ever worked 💪
Many thanks,  Mark

paulsammut, 2025-08-21:
This should help:

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

schematics are in the repo. Not sure which blue wire goes where but it’s 50/50 so give it a shot :)

Ramosuser007, 2025-08-26:
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

Thanks Paul. Thats magic! You're a gentleman.

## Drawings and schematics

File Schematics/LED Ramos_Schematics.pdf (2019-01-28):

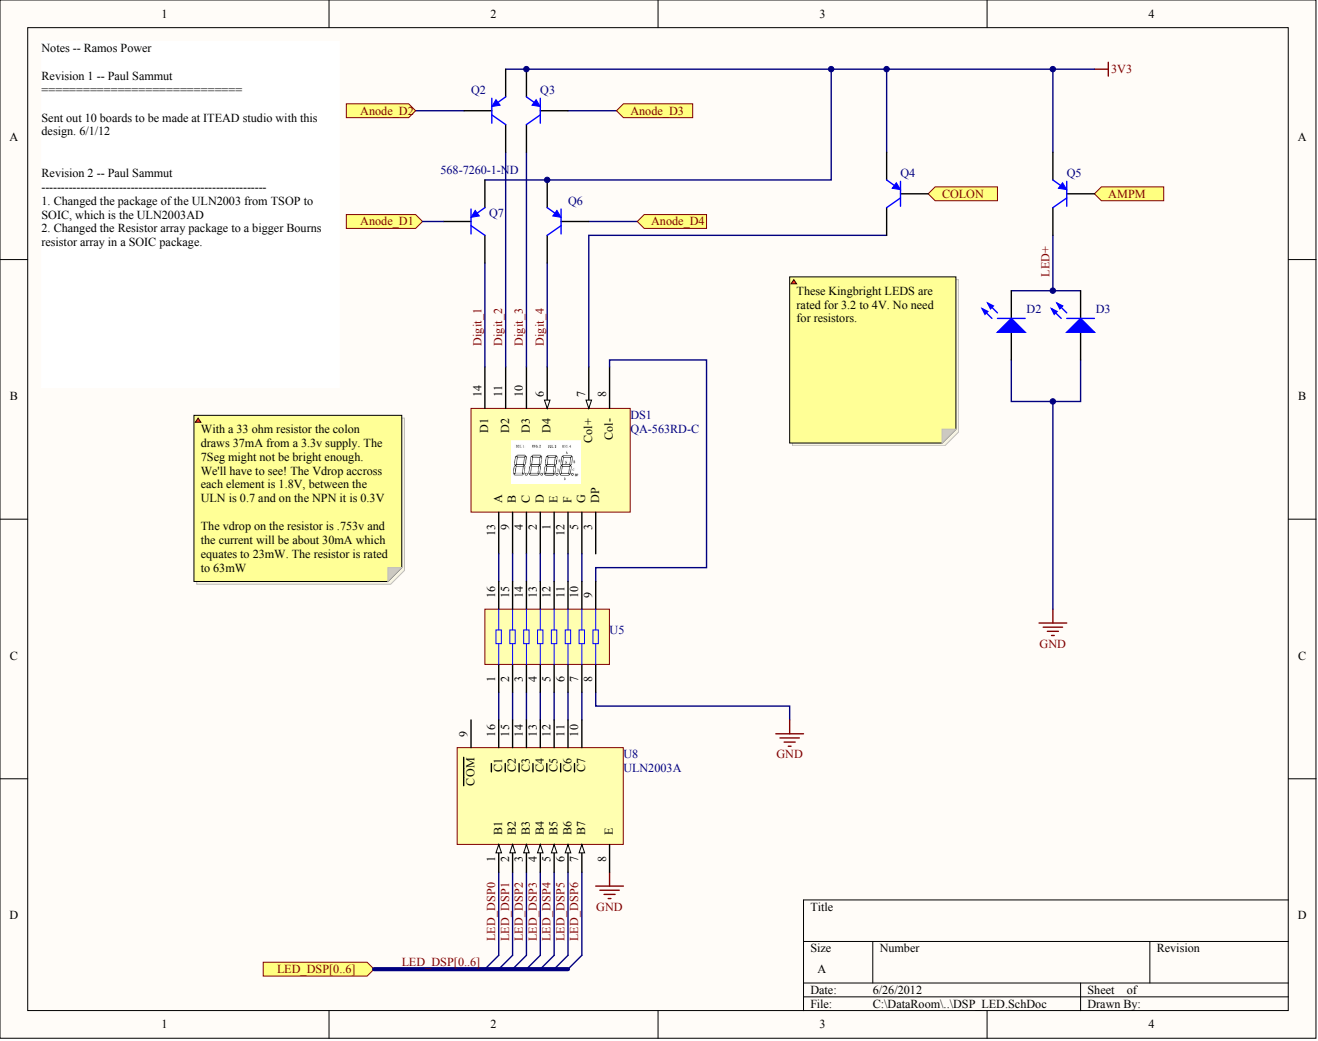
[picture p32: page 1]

Sent out 10 boards to be made at ITEAD studio with this
design. 6/1/12

Revision 2 -- Paul Sammut
1. Changed the package of the ULN2003 from TSOP to
SOIC, which is the ULN2003AD
2. Changed the Resistor array package to a bigger Bourns
resistor array in a SOIC package.

These Kingbright LEDS are
rated for 3.2 to 4V. No need
for resistors.

With a 33 ohm resistor the colon
draws 37mA from a 3.3v supply. The
7Seg might not be bright enough.
We'll have to see! The Vdrop accross
each element is 1.8V, between the
ULN is 0.7 and on the NPN it is 0.3V

The vdrop on the resistor is .753v and
the current will be about 30mA which
equates to 23mW. The resistor is rated

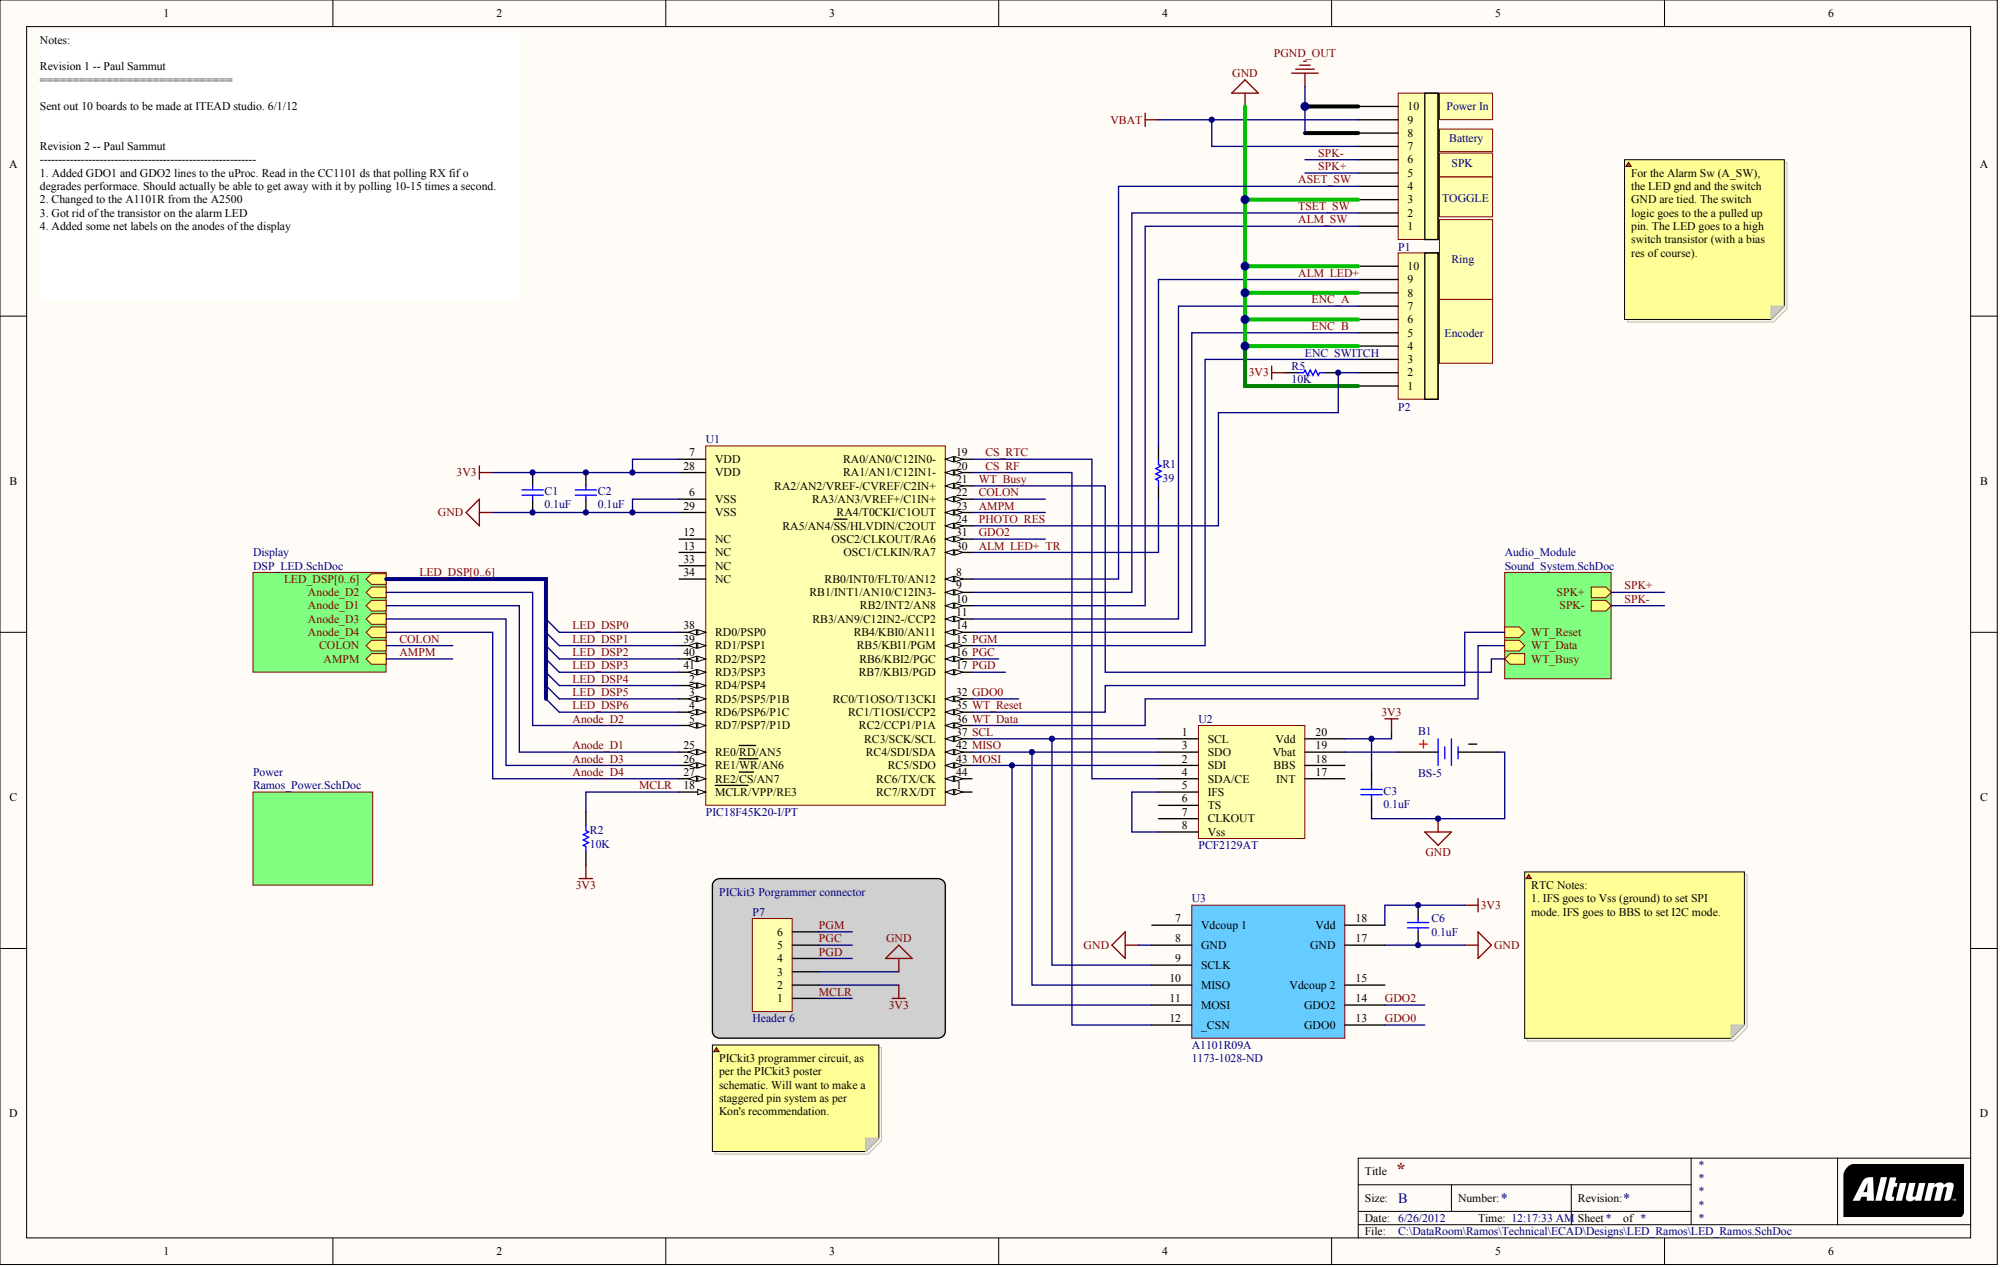
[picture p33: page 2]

Sent out 10 boards to be made at ITEAD studio. 6/1/12

1. Added GDO1 and GDO2 lines to the uProc. Read in the CC1101 ds that polling RX fif o
degrades performace. Should actually be able to get away with it by polling 10-15 times a second.
2. Changed to the A1101R from the A2500
3. Got rid of the transistor on the alarm LED
4. Added some net labels on the anodes of the display

For the Alarm Sw (A_SW),
the LED gnd and the switch
GND are tied. The switch
logic goes to the a pulled up
pin. The LED goes to a high
switch transistor (with a bias
res of course).

TSET_SW
ALM_SW

ENC_SWITCH

CS_RTC

RTC Notes:
FS goes to Vss (ground) to set SP
mode. I

FS goes to BBS to set I2C mode.

ICkit3 program
per the P
schematic. Will want to make a
staggered pin system as per Kon's recommendation.

Title | ****

Size: B | Number: | Revision:

6/26/2012 Time: 12:17:33 AM | | Sheet * of

C:\DataRoom\Ramos\Technical\ECAD\Designs\LED_Ramos\LED_Ramos.SchDoc

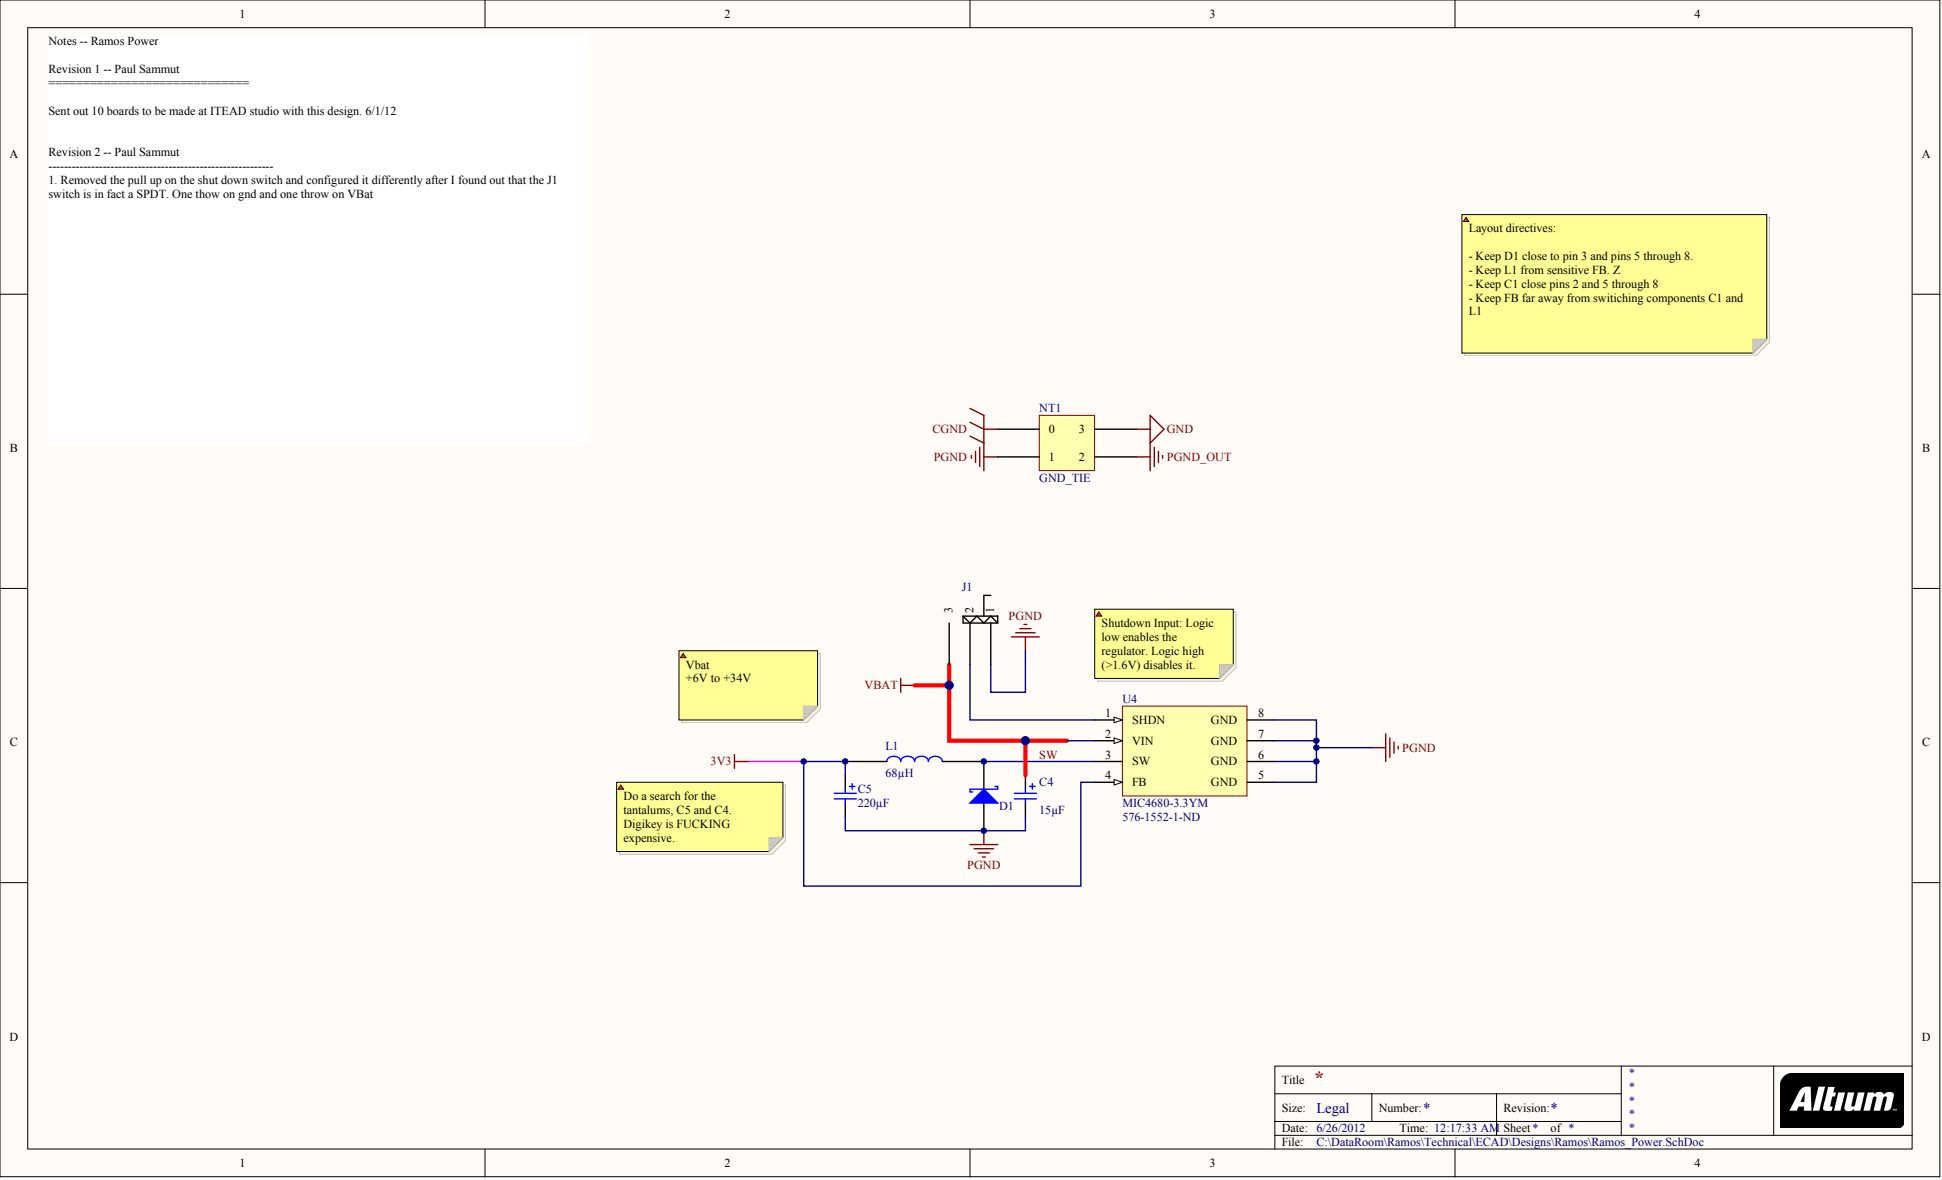
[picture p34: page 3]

Sent out 10 boards to be made at ITEAD studio with this design. 6/1/12

Revision 2 -- Paul Sammut
1. Removed the pull up on the shut down switch and configured it differently after I found out that the J1
switch is in fact a SPDT. One thow on gnd and one throw on VBat

- Keep D1 close to pin 3 and pins 5 through 8.
- Keep L1 from sensitive FB. Z
- Keep C1 close pins 2 and 5 through 8
- Keep FB far away from switiching components C1 and

Do a search for the
tantalums, C5 and C4.
Digikey is FUCKING
expensive.

Legal | * | *

Date: | | *

C:\DataRoom\Ramos\Technical\ECAD\Designs\Ramos\Ramos_Power.SchDoc

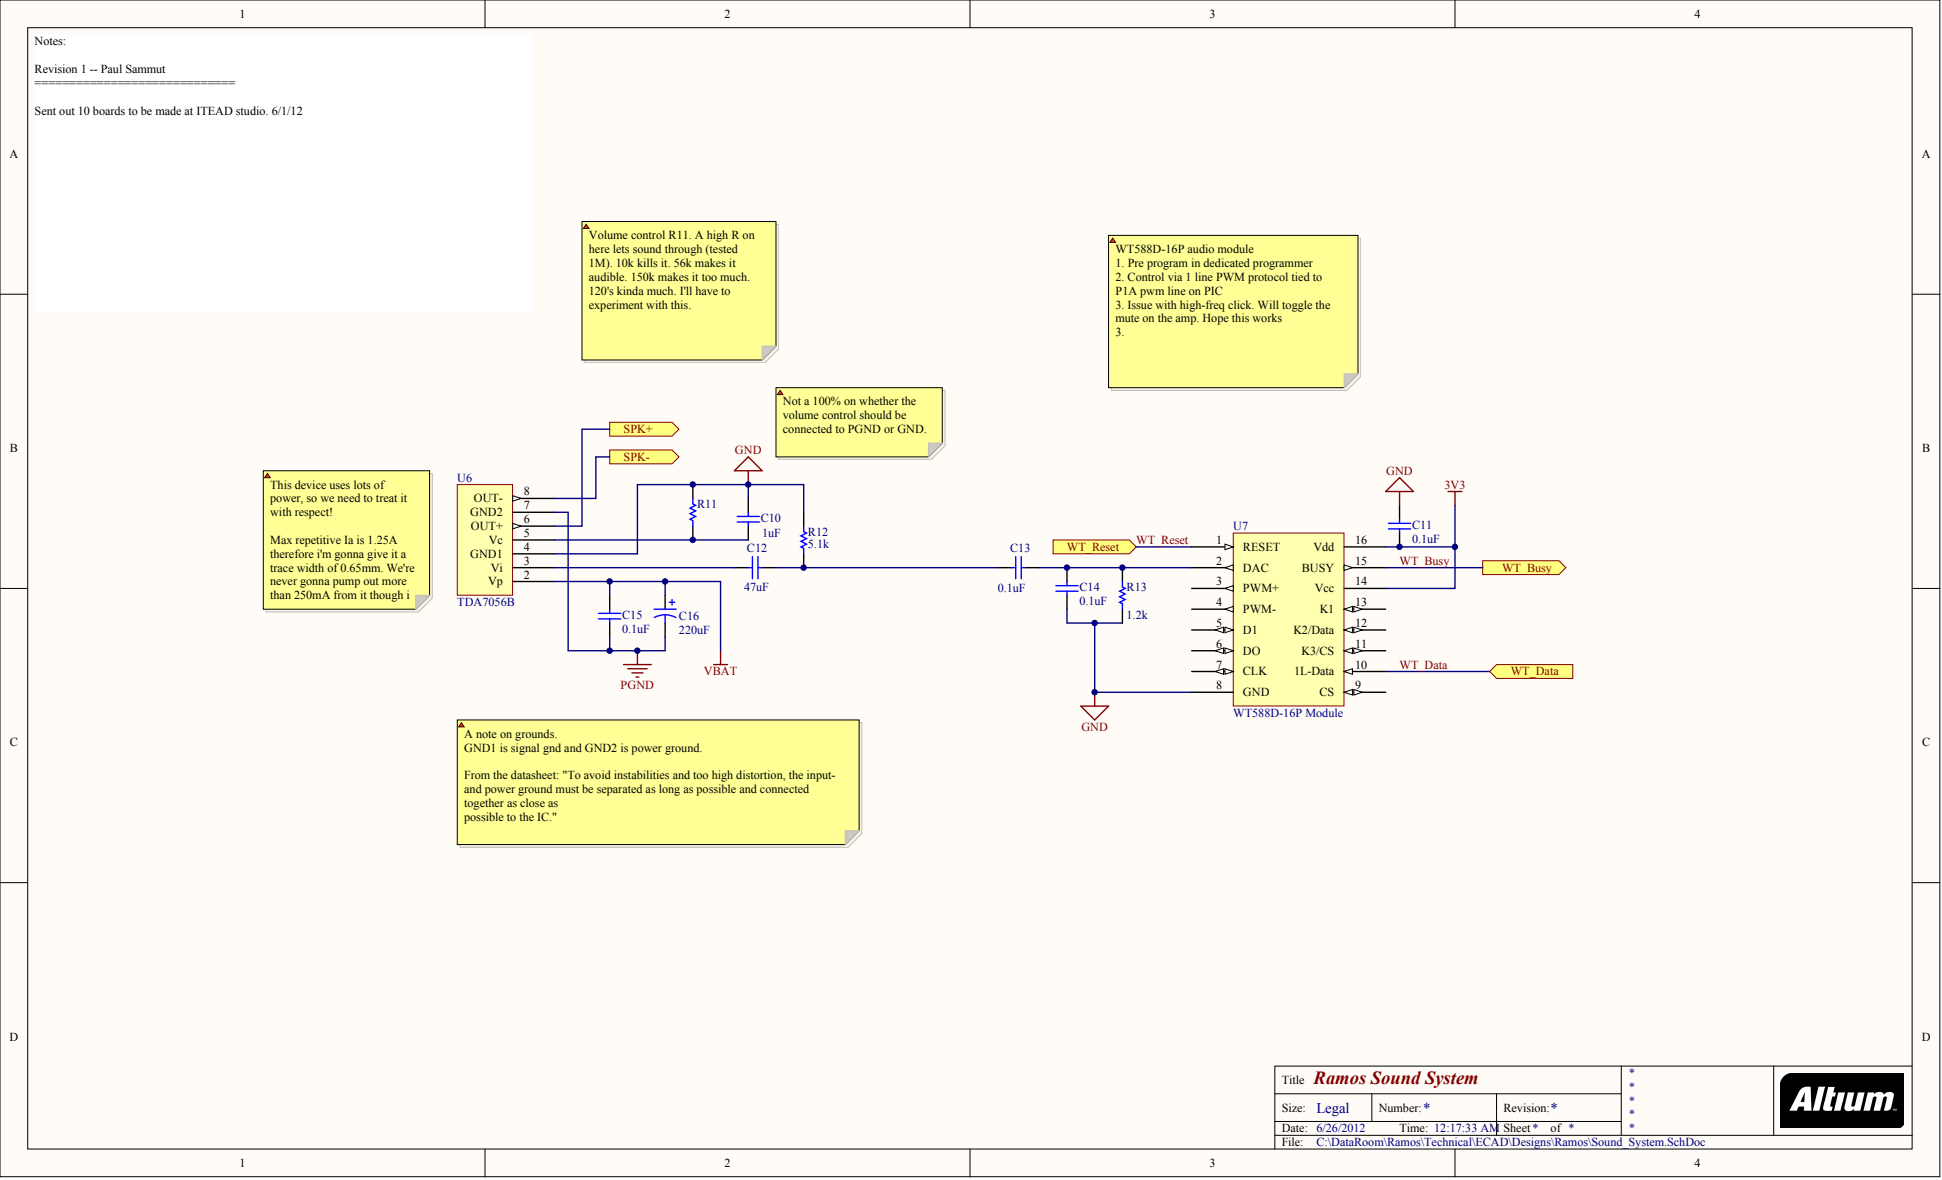
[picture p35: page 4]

Sent out 10 boards to be made at ITEAD studio. 6/1/12

Volume control R11. A high R on
here lets sound through (tested
1M). 10k kills it. 56k makes it
audible. 150k makes it too much.
120's kinda much. I
experiment with this.

WT588D-16P audio module
1. Pre program in dedicated program
2. Control via 1 line PWM protocol tied to P1A pwm line on PIC

3. Issue with high-freq click. Will toggle the mute on the amp. Hope this works

Not a 100% on whether the volume control should be

connected to PGND or GND.

This device uses lots of
power, so we need to treat it
with respect!

Max repetitive Ia is 1.25A
therefore i'
trace width of 0.65m
never gonna pump out more
than 250mA from it though i

A note on grounds.
GND1 is signal gnd and GND2 is power ground. From the datasheet: "To avoid instabilities and too high distortion, the input-

and power ground must be separated as long as possible and connected
together as close as
possible to the IC."

C:\DataRoom\Ramos\Technical\ECAD\Designs\Ramos\Sound_System.SchDoc

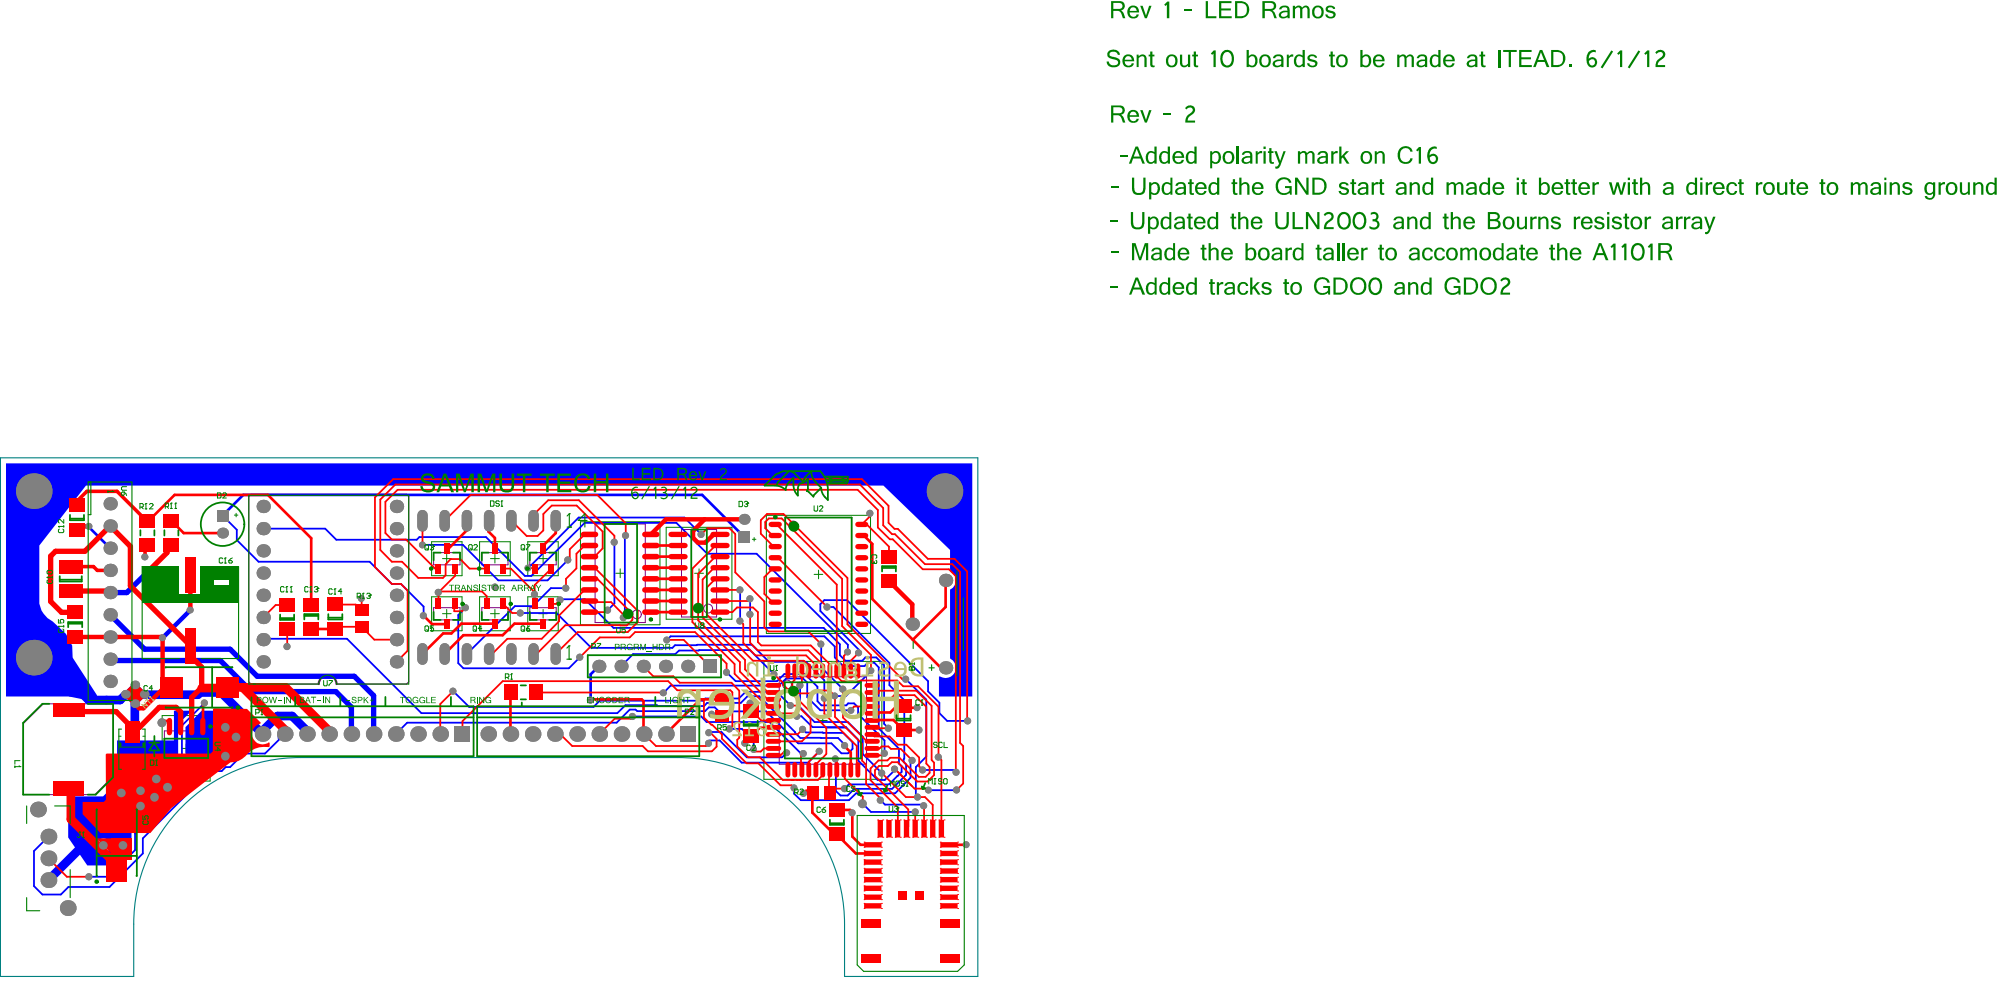
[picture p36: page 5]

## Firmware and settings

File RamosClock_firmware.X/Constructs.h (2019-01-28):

/*
 * File:   Constructs.h
 * Author: Nolan
 *
 * Created on July 11, 2012, 7:21 PM
 */

#ifndef CONSTRUCTS_H
#define	CONSTRUCTS_H

#include <p18f45k20.h>
#include "Ramos_Sys/LED_display.h"
#include "Ramos_sys/Ramos_sys.h"
#include "Ramos_sys/RTC.h"
#include "Ramos_sys/Sound.h"

// Timer limits
#define MENU_TIMER_LIMIT 2500   // How long the alarm button needs to be held to enter the menu mode
#define MENU_SND_WAIT_TIME 450 // how long we wait for play menu sound
#define MENU_TIMEOUT_TIME 20000 // how long until the menu times out
#define RAMPUP_PERIOD 15000  // how long we wait to increment the volume during rampup
#define ALARM_TIMEOUT_LIMIT 45 // how many minutes to wait before timing out alarm
#define AUTODIM_SPEED 50 // how long we wait to increment

// pulse settings
#define PULSE_MIN 4
#define PULSE_MAX 32
#define PULSE_RATE 15 //number of milliseconds to wait until changing

#define BRIGHTNESS_TIMER_LIMIT  3000

/**
 * @brief The modes that the clock could be in
 */
enum Mode
{
    TIME=0,
    SET_TIME,
    SET_ALARM,
    MENU,       // cycling through options in the menu
    MENU_SET    // setting selected options in the menu
};

/**
 * @brief Months of the year
 */
enum months
{
    JAN=1,
    FEB,
    MAR,
    APR,
    MAY,
    JUN,
    JUL,
    AUG,
    SEP,
    OCT,
    NOV,
    DEC
};

/**
 * @brief List of options used in the menu
 */
enum options
{
    REMOTE_ALARM=0,
    DEFUSE_CODE,
    ALARM_TONE,
    LOCKDOWN,
    COURTESY,
    COURTESY_PERIOD,
    NUM_SNOOZES,
    SNOOZE_PERIOD,
    DAY,
    MONTH,
    YEAR,
    DATE_FORMAT,
    TWENTY4_HOUR,
    PM_LIGHT_24HR_VAL,
    DIGIT_CYCLING,
    BRIGHTNESS,
    AUTO_DIM_LEVEL,
    NUM_OPTIONS
};

/**
 * @brief Various "soft" timers used during manual polling.
 */
enum timers_enum
{
    TEMP_TIMER,
    ALARM_TIMER,        // how long the timer has been going off
    MENU_ENTER_TIMER,   // how long we have to hold alarm button to enter menu
    MENU_ANIM_TIMER,
    MENU_SOUND_TIMER,
    MENU_TIMEOUT_TIMER,
    DIGIT_TIMER,
    PULSE_TIMER,
    DEFUSE_CODE_TIMER,
    BRIGHTNESS_TIMER,   // timer to show brightness at full whenever a button is hit
    NUM_TIMERS
};

/**
 * @brief States if using lockdown mode
 */
enum lockdownandalarmstate
{
    NEITHER=0,
    INLOCKDOWN,
    PSUEDOLOCKDOWN,
    ALARM_TRIGGERED
};

/**
 * @brief Main statemachine of the clock
 */
typedef struct
{
    unsigned char setHourMode; // true == set hours, false == set minutes
    unsigned char alarmOn;     // alarm on
    unsigned char lockDownAndAlarmState;
    // Time
    unsigned char hours;
    unsigned char minutes;
    // Alarm Time
    unsigned char alarmHours;
    unsigned char alarmMinutes;
    unsigned char snoozeCount;
    unsigned char defuseFirst;
    unsigned char defuseSecond;
    // Display mode
    unsigned char mode;
    // options
    unsigned int curOption;
    unsigned char options[NUM_OPTIONS];
    // Addresses for remote alarm
    unsigned char address0;
    unsigned char address1;
} State;



#endif

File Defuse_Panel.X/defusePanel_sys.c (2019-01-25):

/** I N C L U D E S **************************************************/
#include "defusePanel_sys.h"

/** C O N F I G U R A T I O N   B I T S ******************************/
#pragma config FOSC = INTIO67, FCMEN = OFF, IESO = OFF                      // CONFIG1H
#pragma config PWRT = OFF, BOREN = ON, BORV = 18                           // CONFIG2L
#pragma config WDTEN = OFF, WDTPS = 8192                                    // CONFIG2H
#pragma config MCLRE = ON, LPT1OSC = OFF, PBADEN = OFF, CCP2MX = PORTC       // CONFIG3H
#pragma config STVREN = ON, LVP = OFF, XINST = OFF                          // CONFIG4L
#pragma config CP0 = OFF, CP1 = OFF, CP2 = OFF, CP3 = OFF                   // CONFIG5L
#pragma config CPB = OFF, CPD = OFF                                         // CONFIG5H
#pragma config WRT0 = OFF, WRT1 = OFF, WRT2 = OFF, WRT3 = OFF               // CONFIG6L
#pragma config WRTB = OFF, WRTC = OFF, WRTD = OFF                           // CONFIG6H
#pragma config EBTR0 = OFF, EBTR1 = OFF, EBTR2 = OFF, EBTR3 = OFF           // CONFIG7L
#pragma config EBTRB = OFF                                                  // CONFIG7H


#pragma idata
/* Counts how many seconds we've waited in inactivty */
unsigned char shutOffCounter = 0;
/* Time treshold in seconds of how long to stay on while inactive*/
unsigned char shutOffTime = 19;
unsigned int RF_TIMER = 0;
/* If in the past it was turned off, then turn it on! */
unsigned char PWM_past = 0;

#pragma udata
unsigned char SYS_addr0;
unsigned char SYS_addr1;
unsigned char PWM_enable;
unsigned char PWM_blueOldVal;
unsigned char PWM_redOldVal;
unsigned char PWM_greenOldVal;

#pragma code

/** P R O T O T Y P E S **********************************************/

void initDefusePanel(void) {

    //Get rid of the analog input stuff
    ANSELH = 0x00; // AN8-12 are digital inputs (AN12 on RB0)

    /*--- P O W E R - O P T I M I Z A T I O N ----------*/
    // As per http://ww1.microchip.com/downloads/en/AppNotes/01416a.pdf
    // "An unused I/O pin should be left unconnected, but configured as an output pin, driving to either state (high or
    //  low)
    TRISA = 0; //output
    TRISB = 0; //output
    TRISC = 0; //output
    TRISD = 0; //output
    TRISE = 0; //output
    LATA = 0;
    LATB = 0;
    //LATC = 0;
    LATD = 0;
    //LATE has the LEDS on the line, so leave it high
    LATE = 0xFF;


    /*--- S Y S - C O N F I G --------------------------*/
    OSCCONbits.IRCF = 0b110; //8 mhz clock
    // Delay10K(10) is 50 ms

    //Set the LEDs as outputs
    TRIS_Blue = 0;
    TRIS_Green = 0;
    TRIS_Red = 0;

    //Go Orange
    setLights(0, 0, 1);

    /**--- L O W - B A T T - D E T E C T ---------------*/
    //enable the HLVD
    //HLVDCONbits.HLVDL = 0b0100; //2.3 volts so 1.15
    HLVDCONbits.HLVDL = 0b0111; //2.46 2.61 2.76 (min typ max)
    HLVDCONbits.VDIRMAG = 0;
    HLVDCONbits.HLVDEN = 1;
    //clear the interrupt flag
    PIR2bits.HLVDIF = 0;
    while (!HLVDCONbits.IRVST); //wait for stability

    /*--- T I M E R S ---------------------------------*/
    /* Turn on Timer0. This is the PWM interrupt timer to make the LEDs not so
     * fucking bright. */
    T0CONbits.T08BIT = 1; //8 Bit timer
    T0CONbits.T0PS = 0b010; //1:16 prescale value
    T0CONbits.PSA = 0; //Timer0 prescaler is assigned. Timer0 clock input comes from prescaler output.
    T0CONbits.T0CS = 0; //Internal instruction cycle clock (CLKOUT)
    T0CONbits.TMR0ON = 1; //Turn timer0 on
    INTCONbits.TMR0IF = 0; //Clear the Interrupt Flag
    INTCONbits.TMR0IE = 1; //enable the timer0 interrupt


    /* Turn on Timer 1, this shuts off the units when not in use. */
    T1CONbits.T1CKPS = 0b11; //1:8 prescale
    T1CONbits.TMR1CS = 0; //Internal clock
    T1CONbits.TMR1ON = 1; //turn the timer on

    /*--- I N T E R R U P T S ------------------------*/
    RCONbits.IPEN = 0; //no priority levels please
    INTCONbits.GIE = 1; // enable interrupts
    INTCONbits.PEIE = 1; // enable peripheral interrupts.

    //Read the address bytes from memory
    SYS_addr0 = EEPROM_Read(MEM_SYS_ADDR0);
    SYS_addr1 = EEPROM_Read(MEM_SYS_ADDR1);

}

void enterSleep(void) {
    INTCONbits.GIE = 0; //so we don't get interrupted
    RF_send_Strobe(SIDLE);
    RF_send_Strobe(SPWD);
    CSn_RF = 1;
    T0CONbits.TMR0ON = 0; //stop Timer 0
    INTCONbits.TMR0IE = 0; //turn off the interrupt
    INTCONbits.TMR0IF = 0; //clear the flag
    T1CONbits.TMR1ON = 0; //stop Timer 1
    PIE1bits.TMR1IE = 0; //turn off the interrupt enable.
    PIR1bits.TMR1IF = 0; //clear the flag

    CloseSPI();

    RF_POW = 0; //as of 11/6/12 this works well.
    //All off
    Blue = 1;
    Red = 1;
    Green = 1;

    //Peripheral shut-down
    HLVDCONbits.HLVDEN = 0;
    CVRCON = 0;
    CVRCON2 = 0;
    CCP1CON = 0;
    CCP2CON = 0;
    CM2CON0bits.C2ON = 0;
    CM1CON0bits.C1ON = 0;
    OSCCONbits.IDLEN = 0; //enter sleep on sleep instruction
    SSPCON1bits.SSPEN = 0;
    T1CONbits.T1OSCEN = 0; //nada

    //Set the RB ports to low to make sure we're good for wakeup
    Row0 = 0;
    Row1 = 0;
    Row2 = 0;
    Row3 = 0;

    //Enabling the interrupts on the keypad lines INT0 INT1 and INT2
    INTCONbits.GIE = 1;
    RCONbits.IPEN = 0; //no priority levels please
    PIR1bits.TMR1IF = 0; //clear the timer1 interrupt flag

    //clear the flags
    INTCONbits.INT0IF = 0;
    INTCON3bits.INT1IF = 0;
    INTCON3bits.INT2IF = 0;

    INTCON2bits.INTEDG0 = 0; //trigger on a falling edge
    INTCON2bits.INTEDG1 = 0; //trigger on a falling edge
    INTCON2bits.INTEDG2 = 0; //trigger on a falling edge

    //enable the external interrupts
    INTCONbits.INT0IE = 1;
    INTCON3bits.INT1IE = 1;
    INTCON3bits.INT2IE = 1;

    Sleep();

}

void checkBattery(void) {
    if (PIR2bits.HLVDIF) {//Battery to no PWM point
        // check for No PWM point
        PIR2bits.HLVDIF = 0;
        PWM_enable = 0; //turn off the PWM to make the LEDs brighter
        // check for Low Voltage point
        HLVDCONbits.HLVDL = 0b0101; //2.37 volts so 1.185
        while (!HLVDCONbits.IRVST); //wait for stability
        PIR2bits.HLVDIF = 0;
        if (PIR2bits.HLVDIF) { //   Low voltage point
            setLights(0, 1, 1);
            blinkRed();
            setStandbyLight(0); //low battery red standby light
        }

    } else {
        setLights(1, 1, 0);
        blinkBlue();
        setStandbyLight(1); //blue standby light.
        PWM_enable = 1; //turn on the PWM to not make it so fucking bright
    }
}

void shutOffTickTock(void) {
    if (PIR1bits.TMR1IF) {
        shutOffCounter++;
        PIR1bits.TMR1IF = 0;
    }
    //if we have wated till our shut off time
    if (shutOffCounter >= shutOffTime) {
        enterSleep();
    }
}

void resetTickTock(void) {
    shutOffCounter = 0;
}

#pragma code isr = 0x08
#pragma interrupt isr
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

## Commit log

2019-01-28 Adding schematics and images
    [LED Panel assembly information.xlsx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]
2019-01-28 Nixie and led ramos
